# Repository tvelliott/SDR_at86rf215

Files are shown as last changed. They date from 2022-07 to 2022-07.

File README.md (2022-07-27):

# SDR_at86rf215
SDR design based on the AT86RF215 transceiver with IQ LVDS / FPGA DDR (dual-data-rate) interface. The quadrature data is clocked on the rising *and* falling edges. Ethernet is 100Mbps. The firmware and HDL was written and operational in 2018. It supports stand-alone reception of P25. The firmware implementation is P25 P1 only. It does not currently do P25 P2 or P25 trunk-tracking, but the hardware is capable. It can also be used with SDR software over Ethernet such as GQRX with modified RTL-TCP drivers (mods allow 16-bit samples).

<BR>To compile:
<BR>install the gcc arm toolchain version gcc-arm-none-eabi-7-2018-q2-update/   
<BR>https://developer.arm.com/tools-and-software/open-source-software/developer-tools/gnu-toolchain/gnu-rm/downloads/7-2018-q2-update
<BR><BR>In the firmware directory, create a symbolic link to the toolchain: 
<BR>e.g.  ln -s ../gcc-arm-none-eabi-7-2018-q2-update  arm-toolchain
<BR>Then type 'make'
<BR>
<BR>
To compile the verilog code and place-route for the FPGA, you will need to install project ice-storm,Yosys, and nextpnr. In order to run the testbench for the DDR verilog code, you will also need to install iverilog and gtkwave.
<BR>
<BR>https://github.com/YosysHQ/icestorm
<BR>https://github.com/YosysHQ/yosys
<BR>https://github.com/YosysHQ/nextpnr
<BR>https://github.com/steveicarus/iverilog
<BR>https://github.com/gtkwave/gtkwave
<BR><BR>
AT86RF215 12-bit I/Q Receiver PCB / ICE40 BGA-256 FPGA / STM32H743 MCU / 100Mbps Ethernet / Stereo I2S Audio
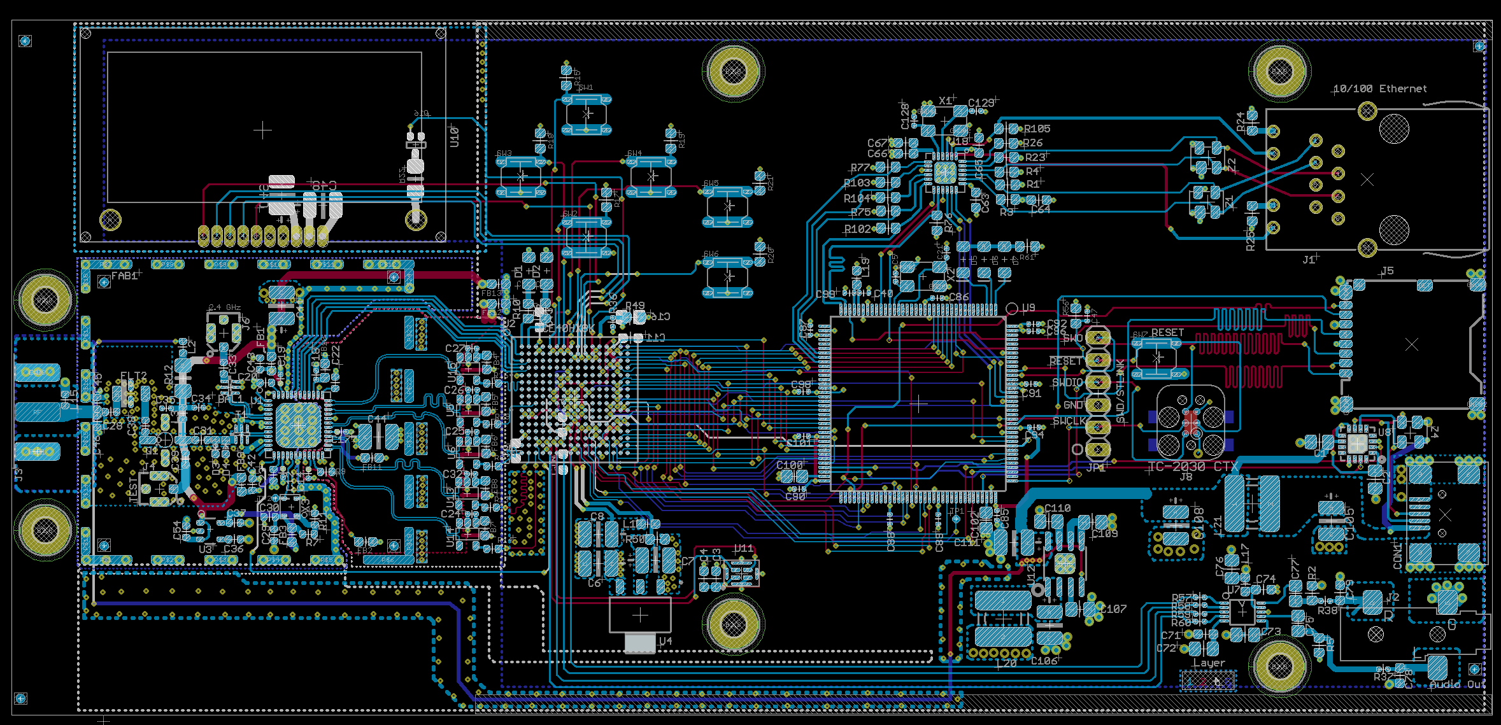
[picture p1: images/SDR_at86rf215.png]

<BR>
Dual-antenna VHF/UHF Tuner PCB (1MHz to 1200 MHz), IF output is 914 MHz and fed to the AT86RF215 receiver.
<BR>
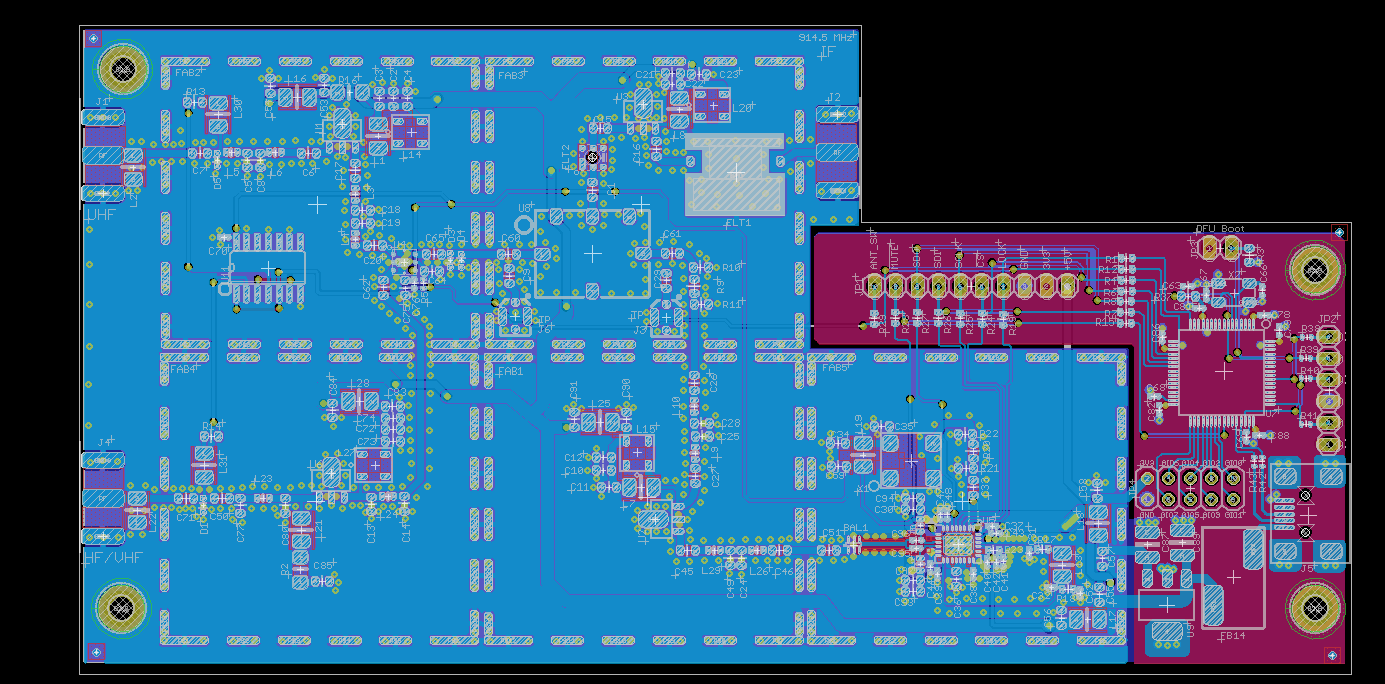
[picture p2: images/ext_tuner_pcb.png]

<BR>
FPGA Routing / Usage
<BR>
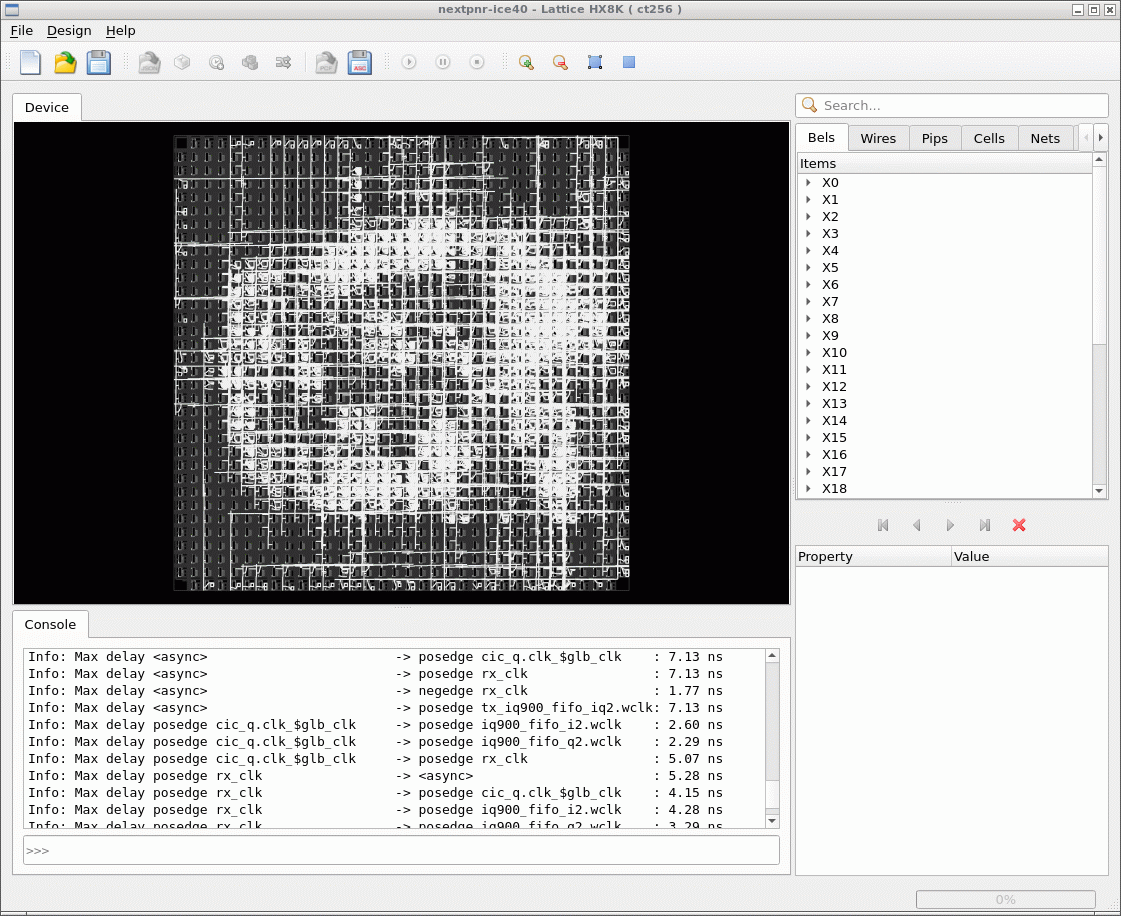
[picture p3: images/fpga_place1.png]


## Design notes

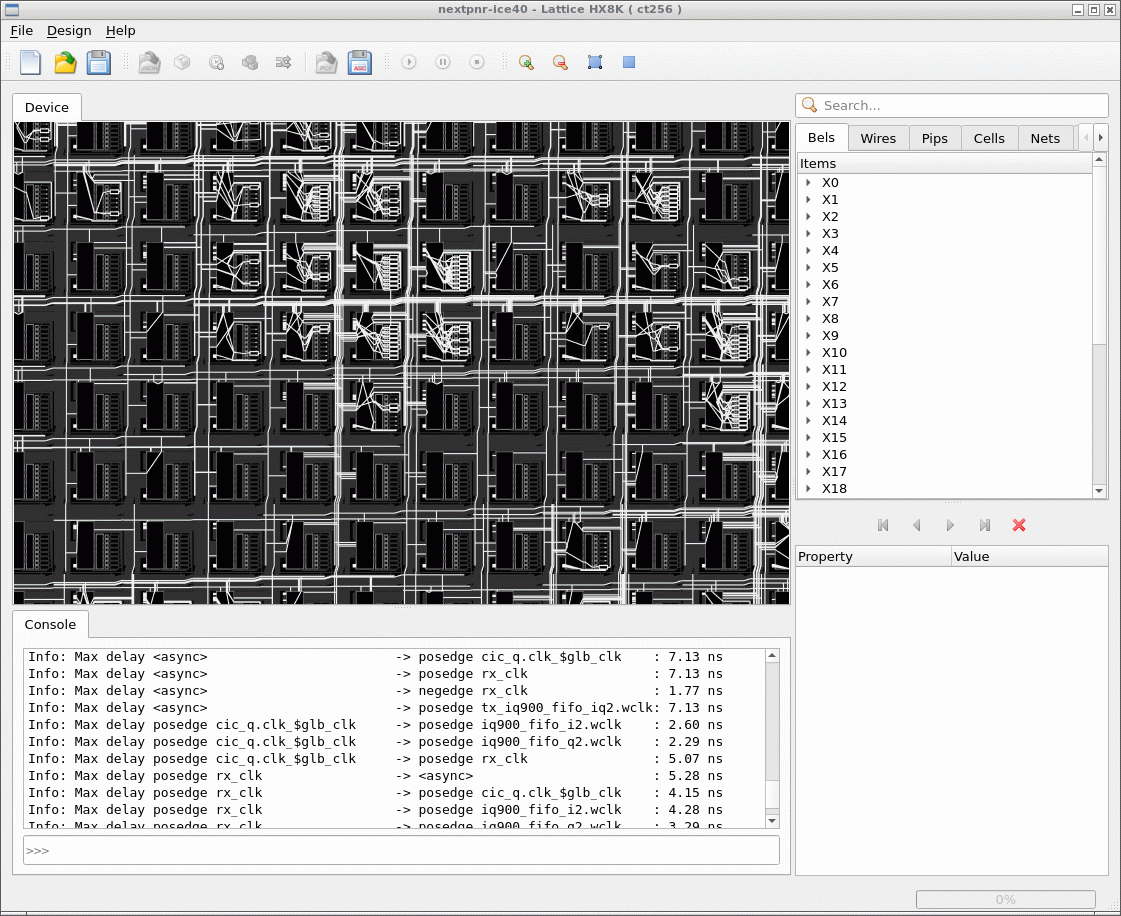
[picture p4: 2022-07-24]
images/fpga_place2.png

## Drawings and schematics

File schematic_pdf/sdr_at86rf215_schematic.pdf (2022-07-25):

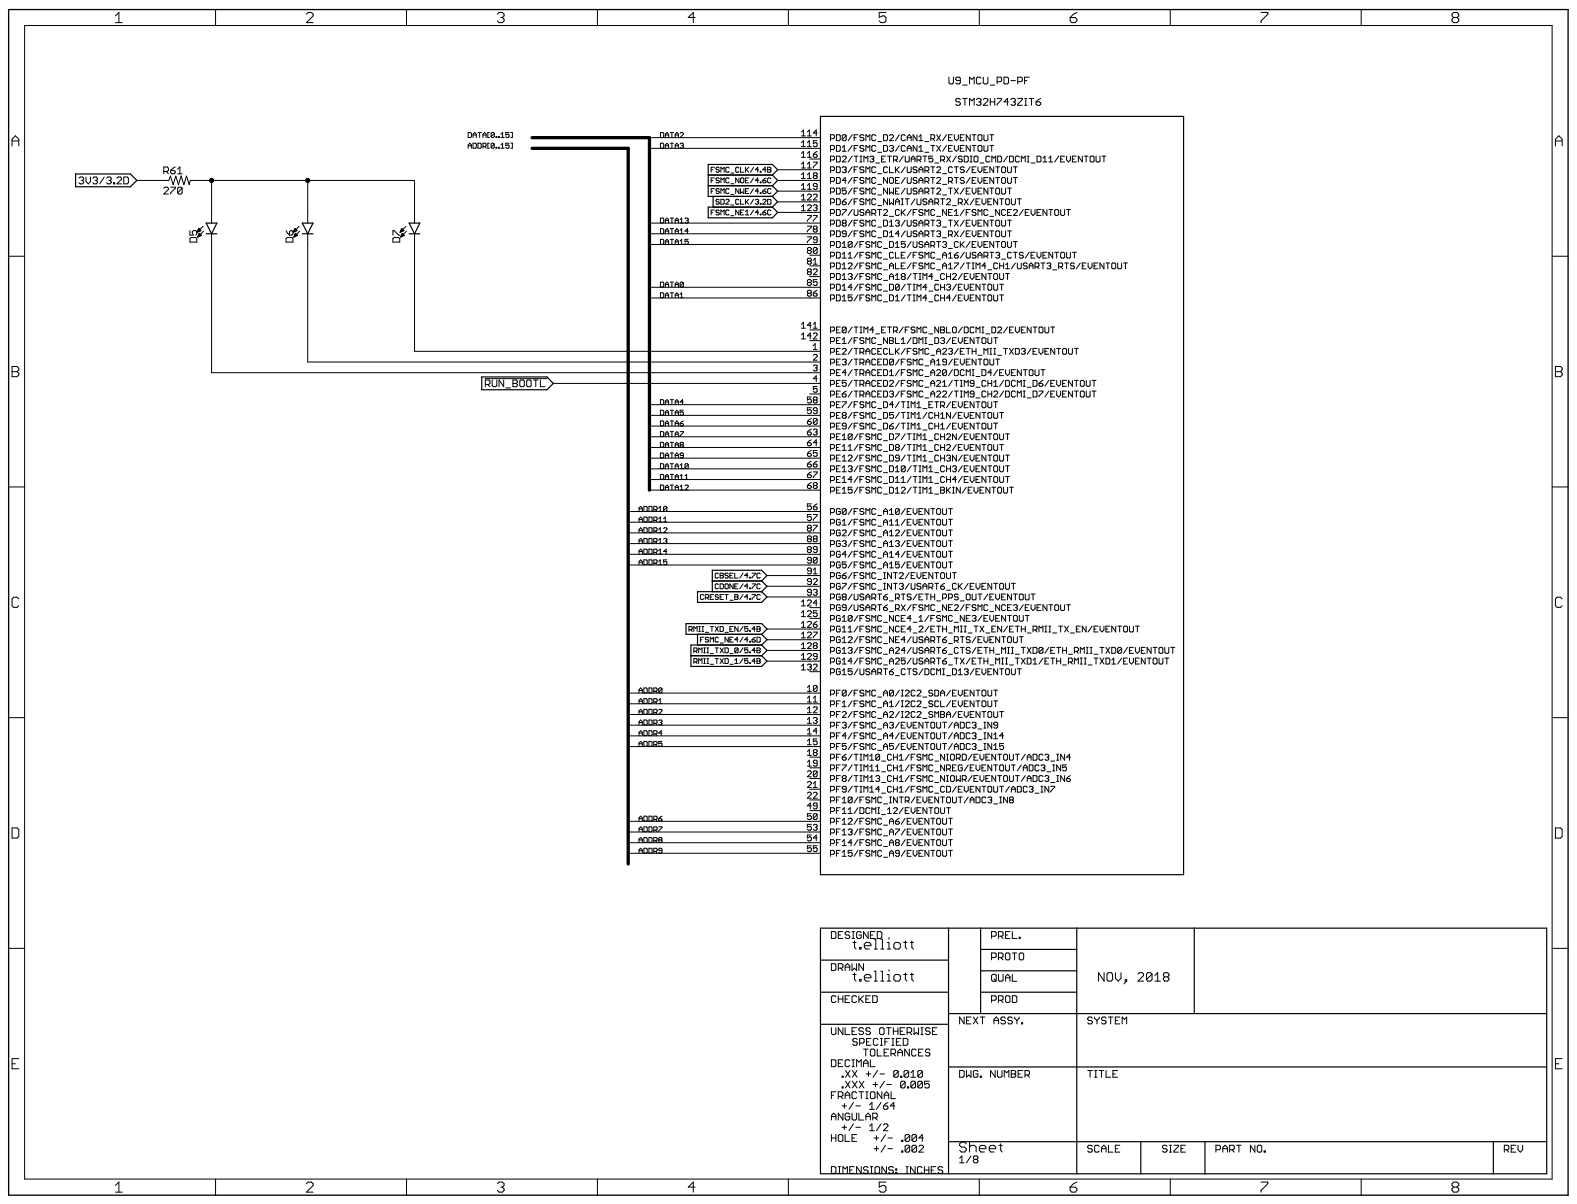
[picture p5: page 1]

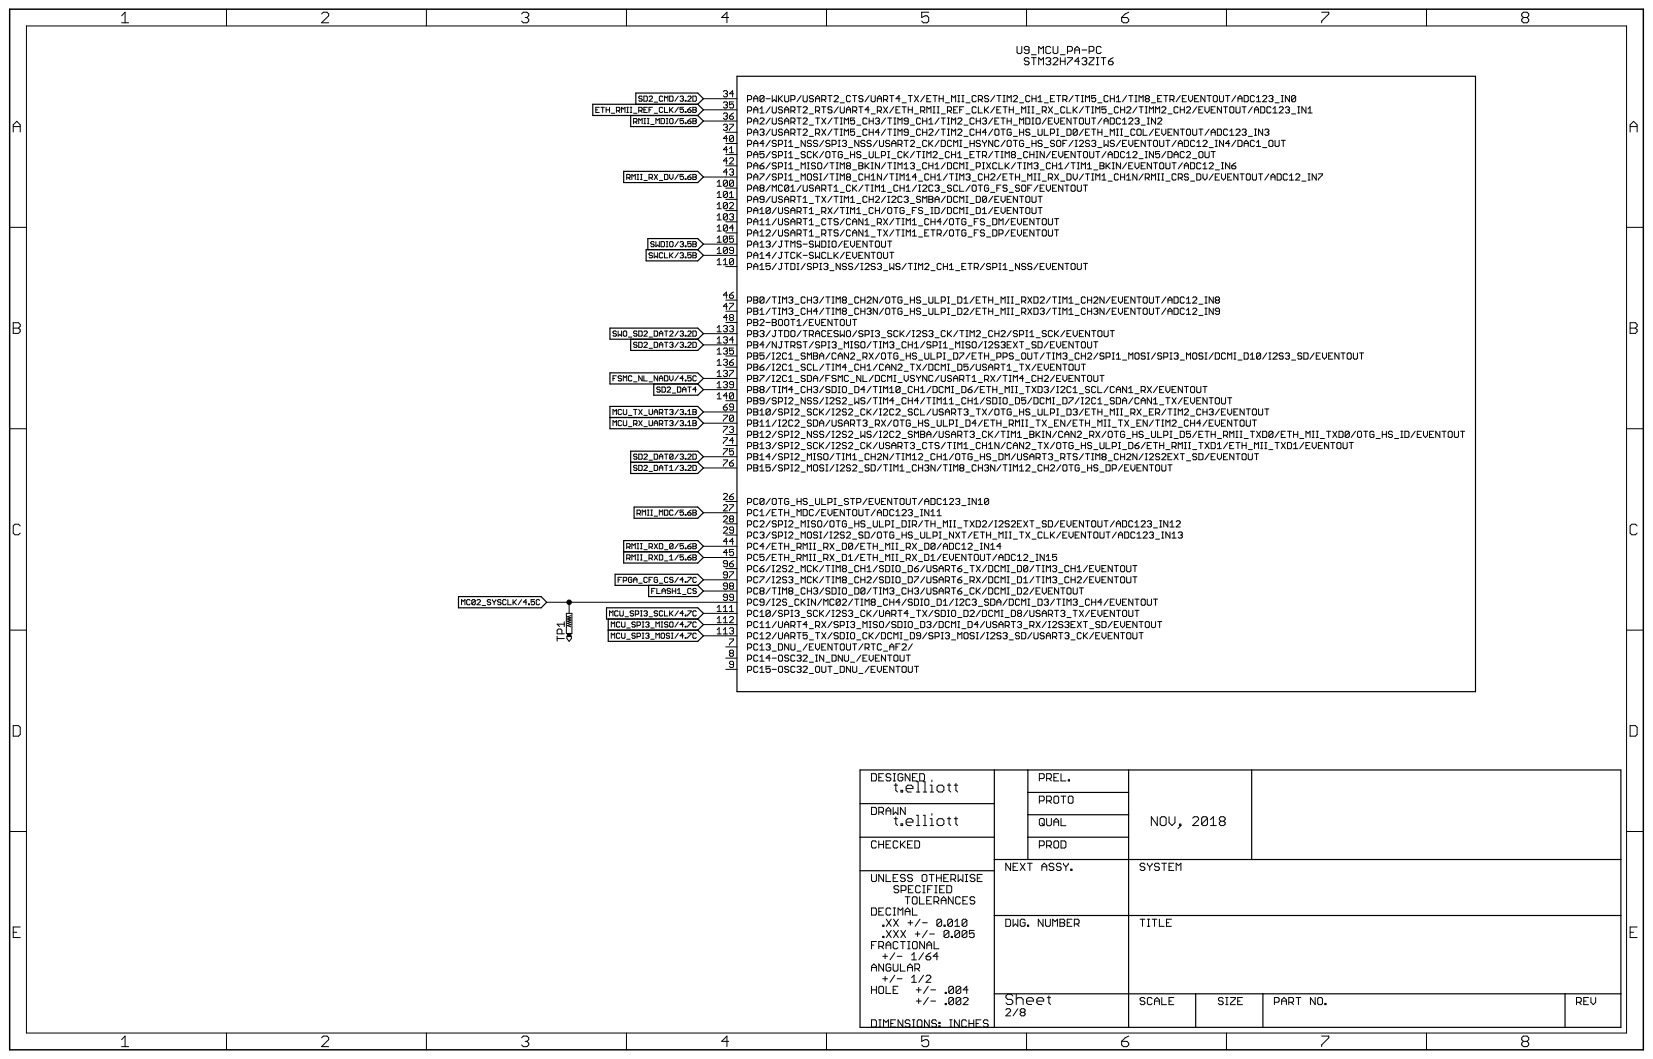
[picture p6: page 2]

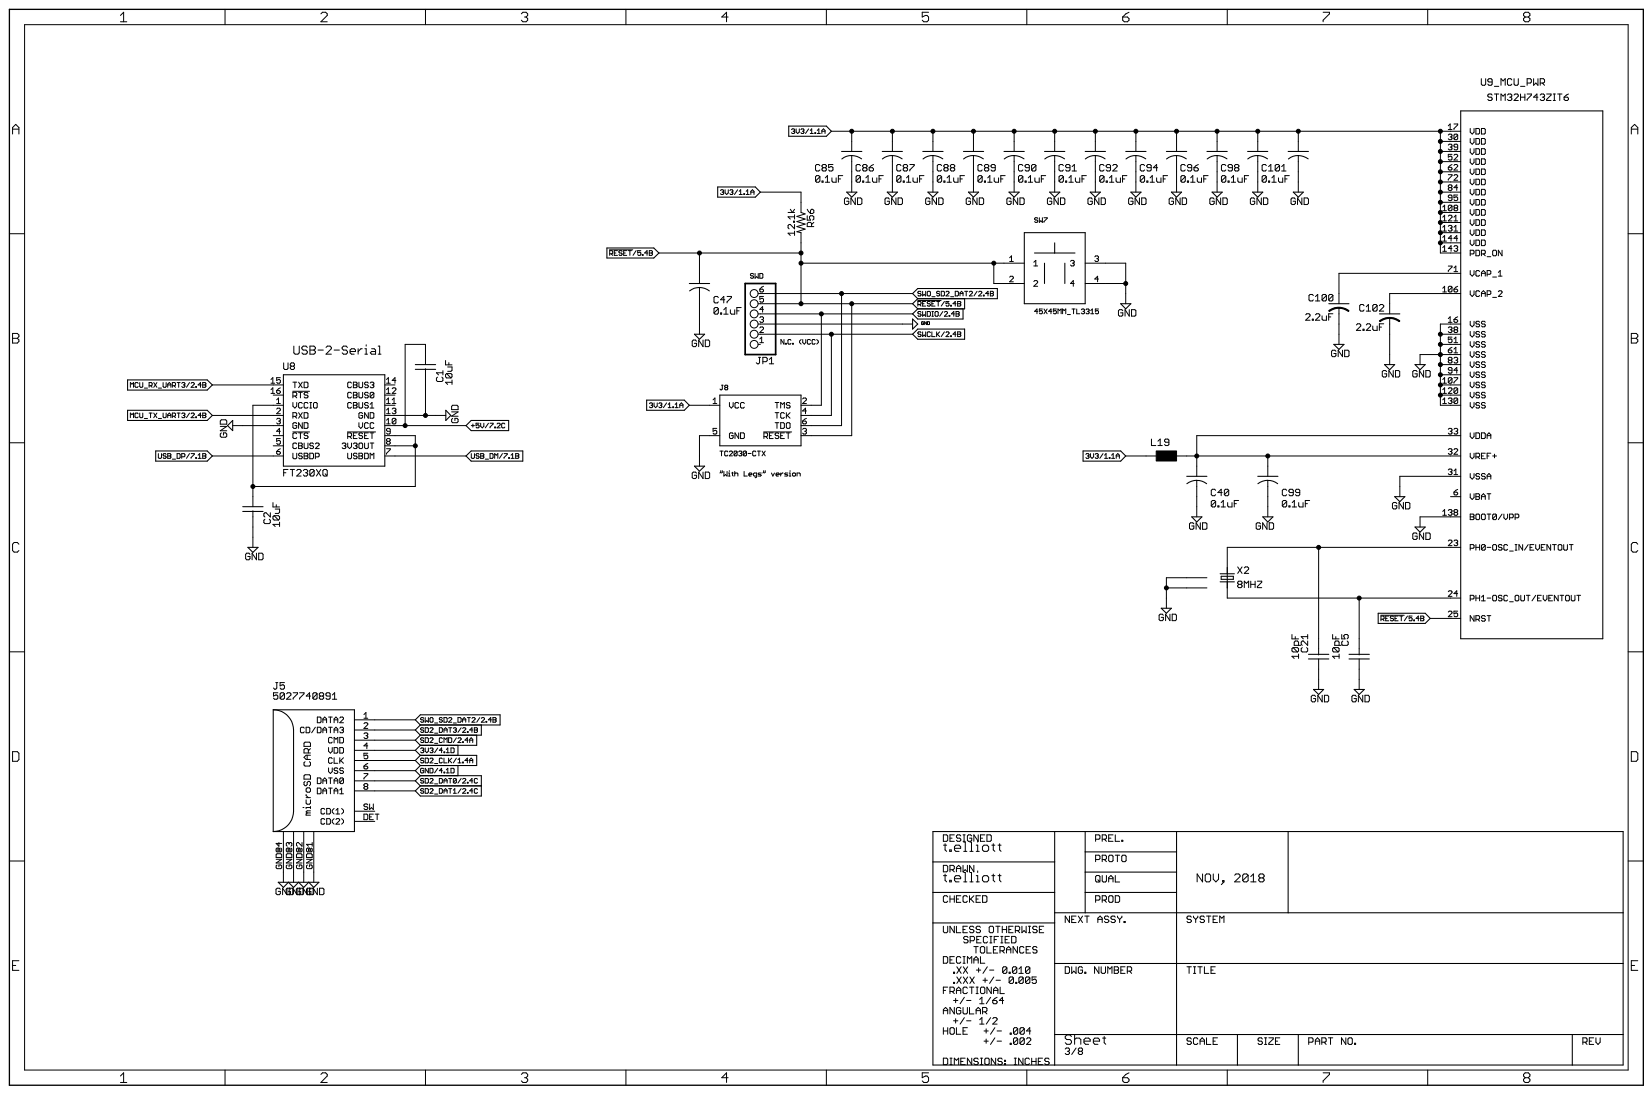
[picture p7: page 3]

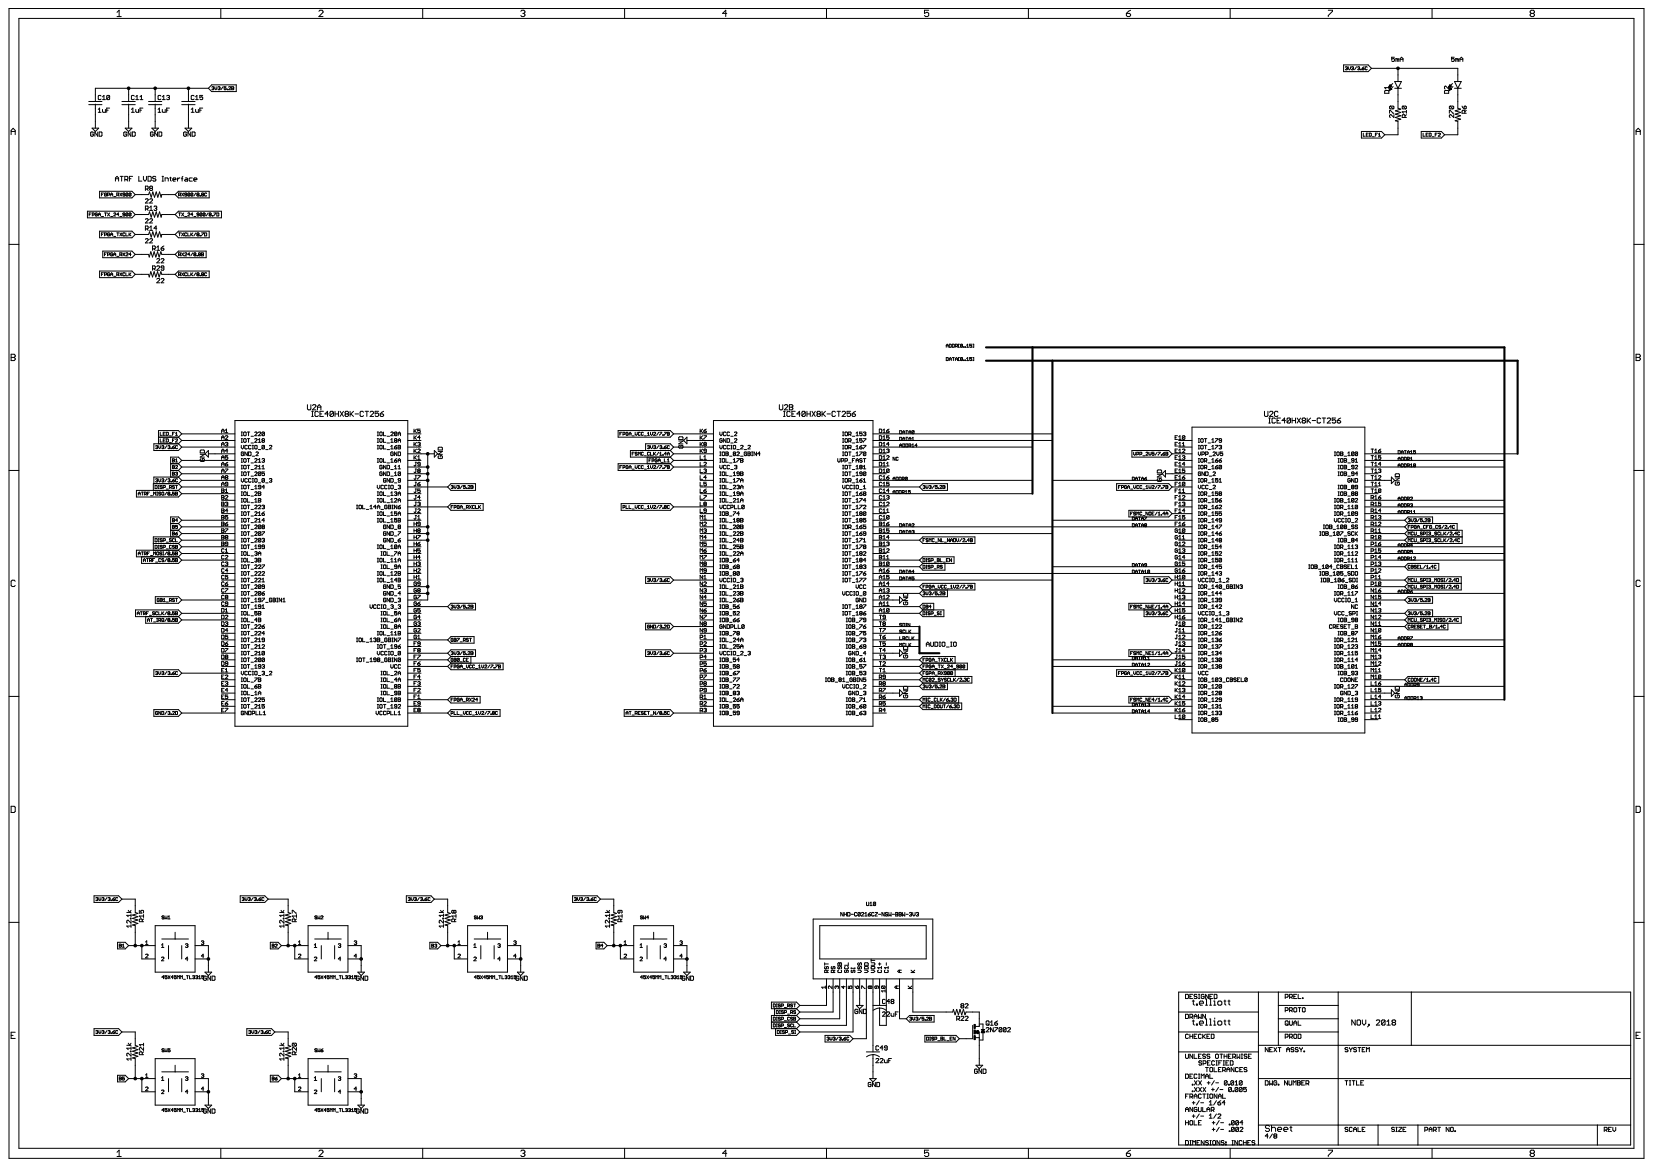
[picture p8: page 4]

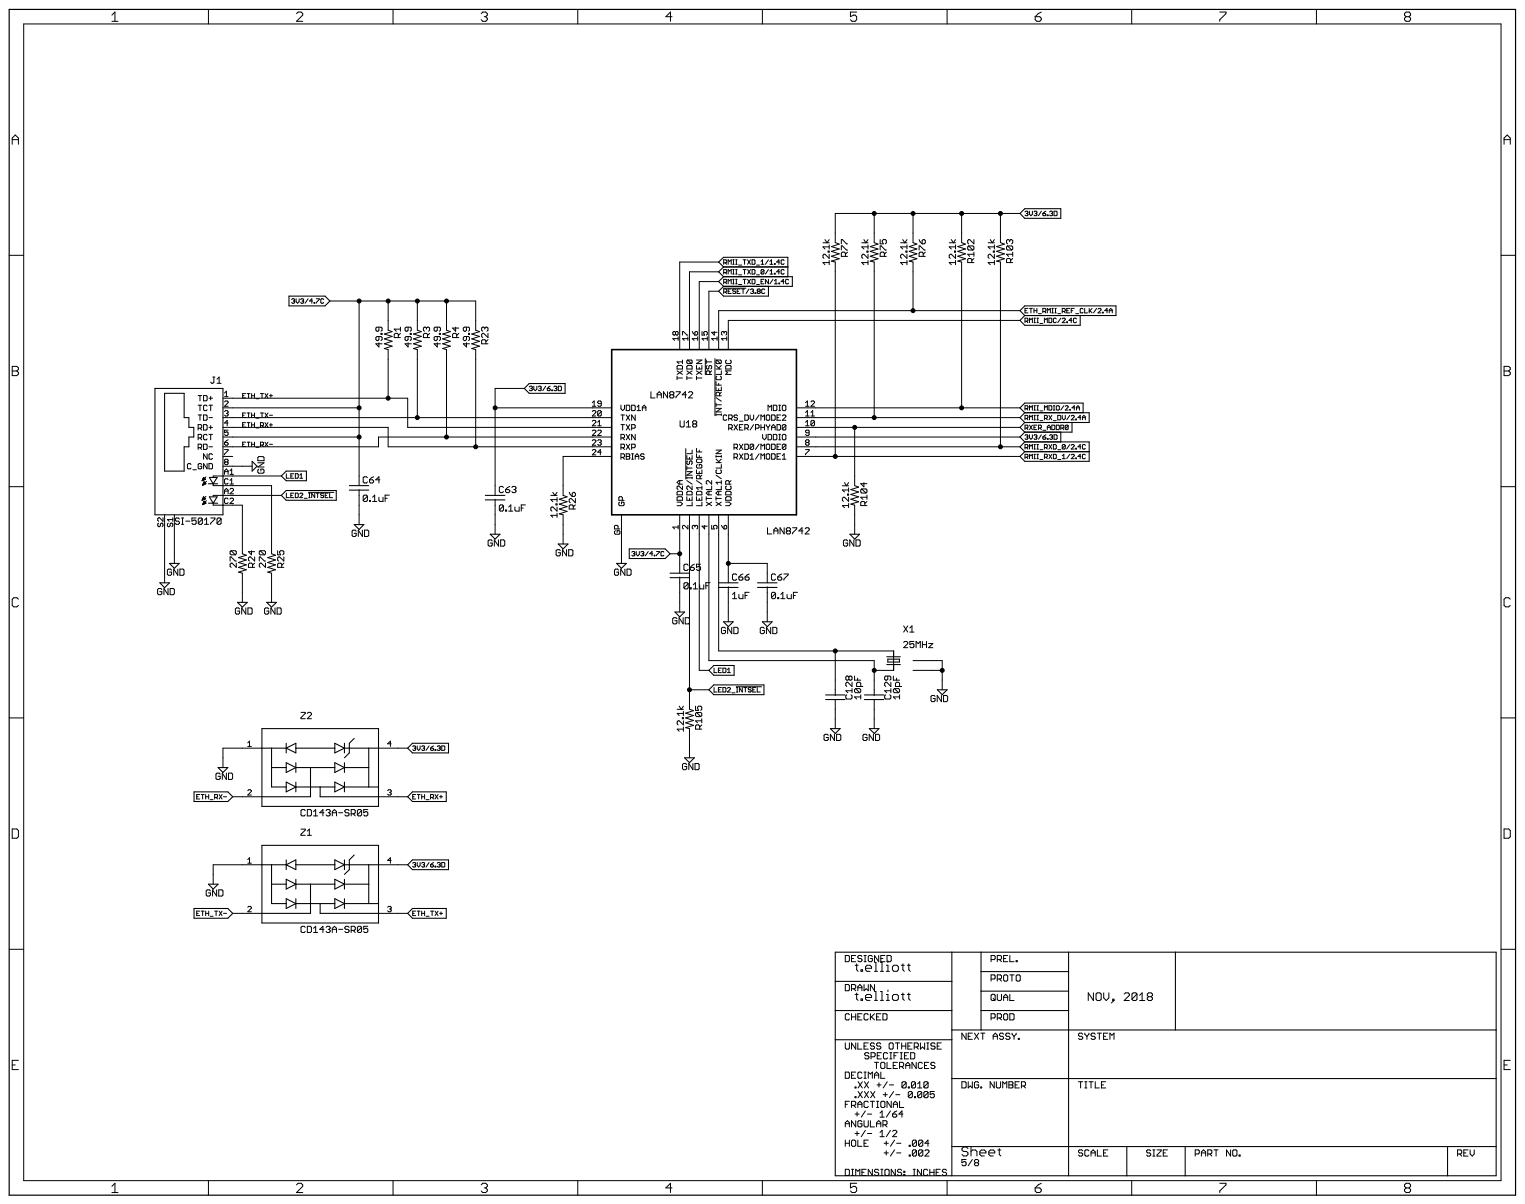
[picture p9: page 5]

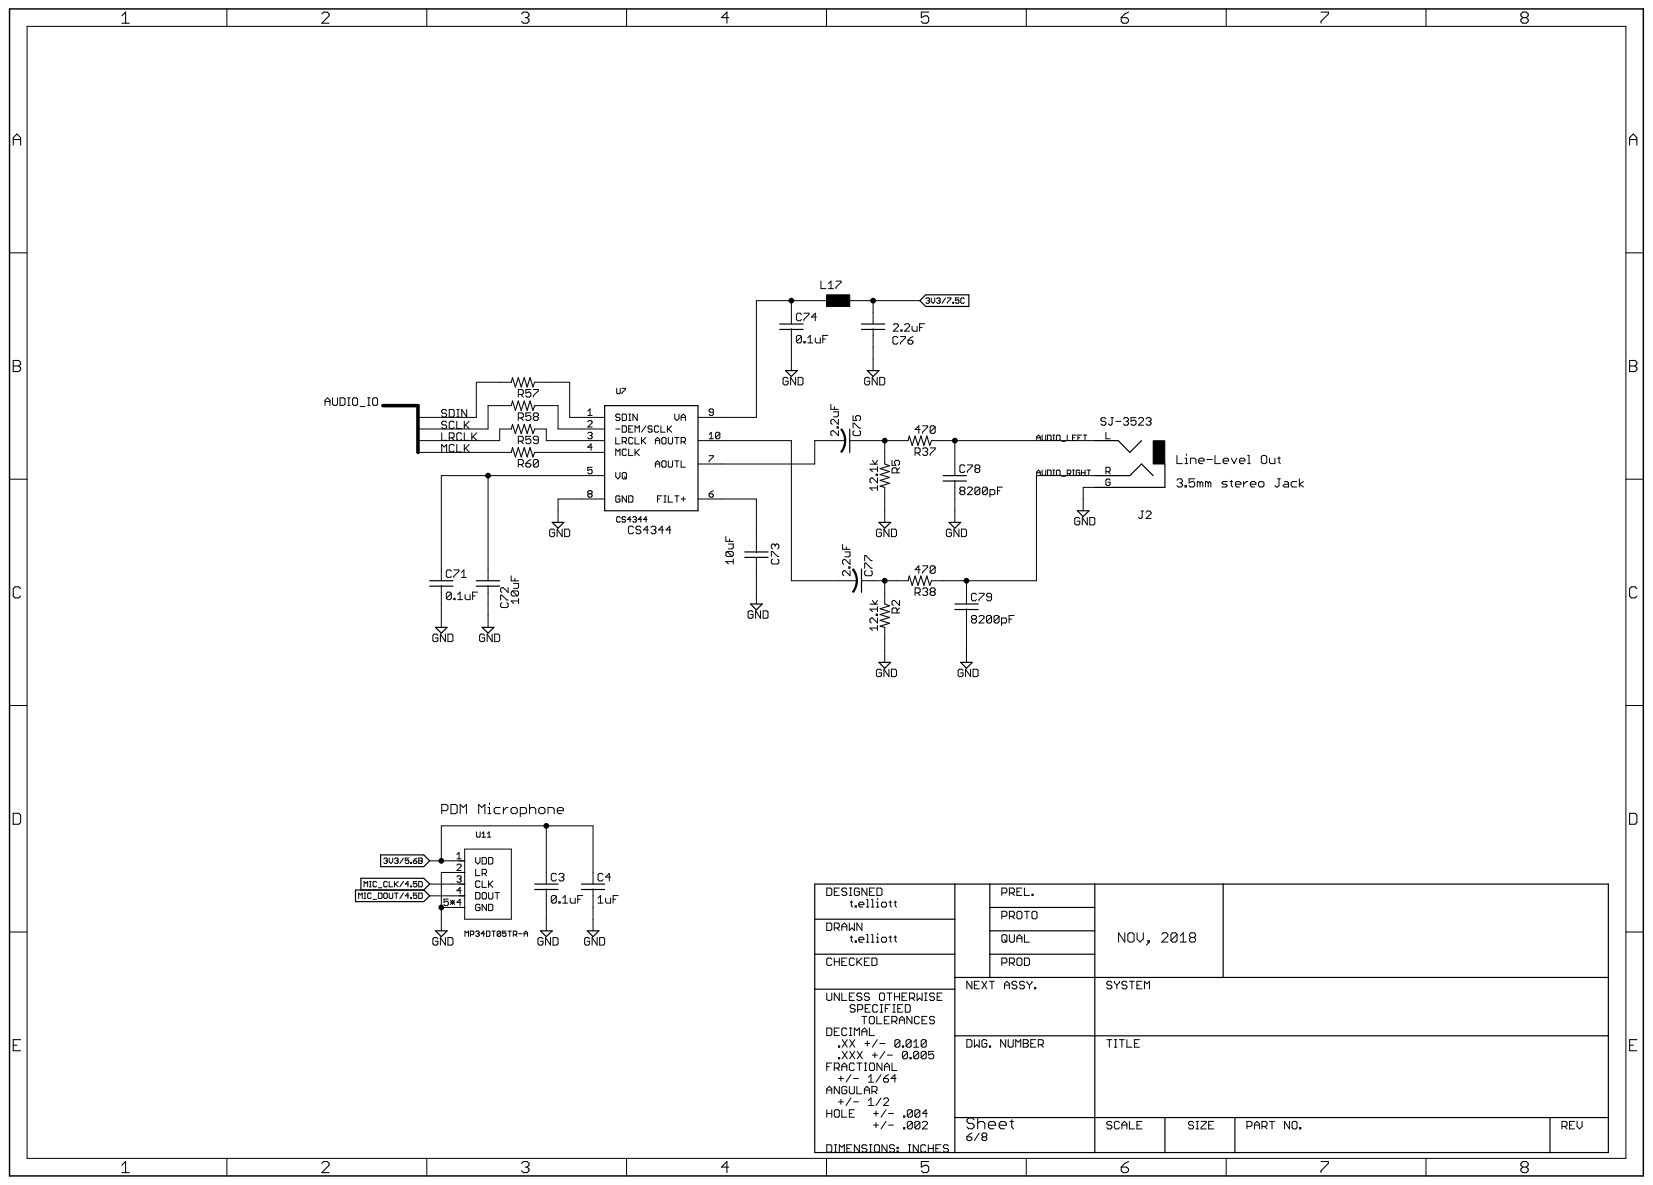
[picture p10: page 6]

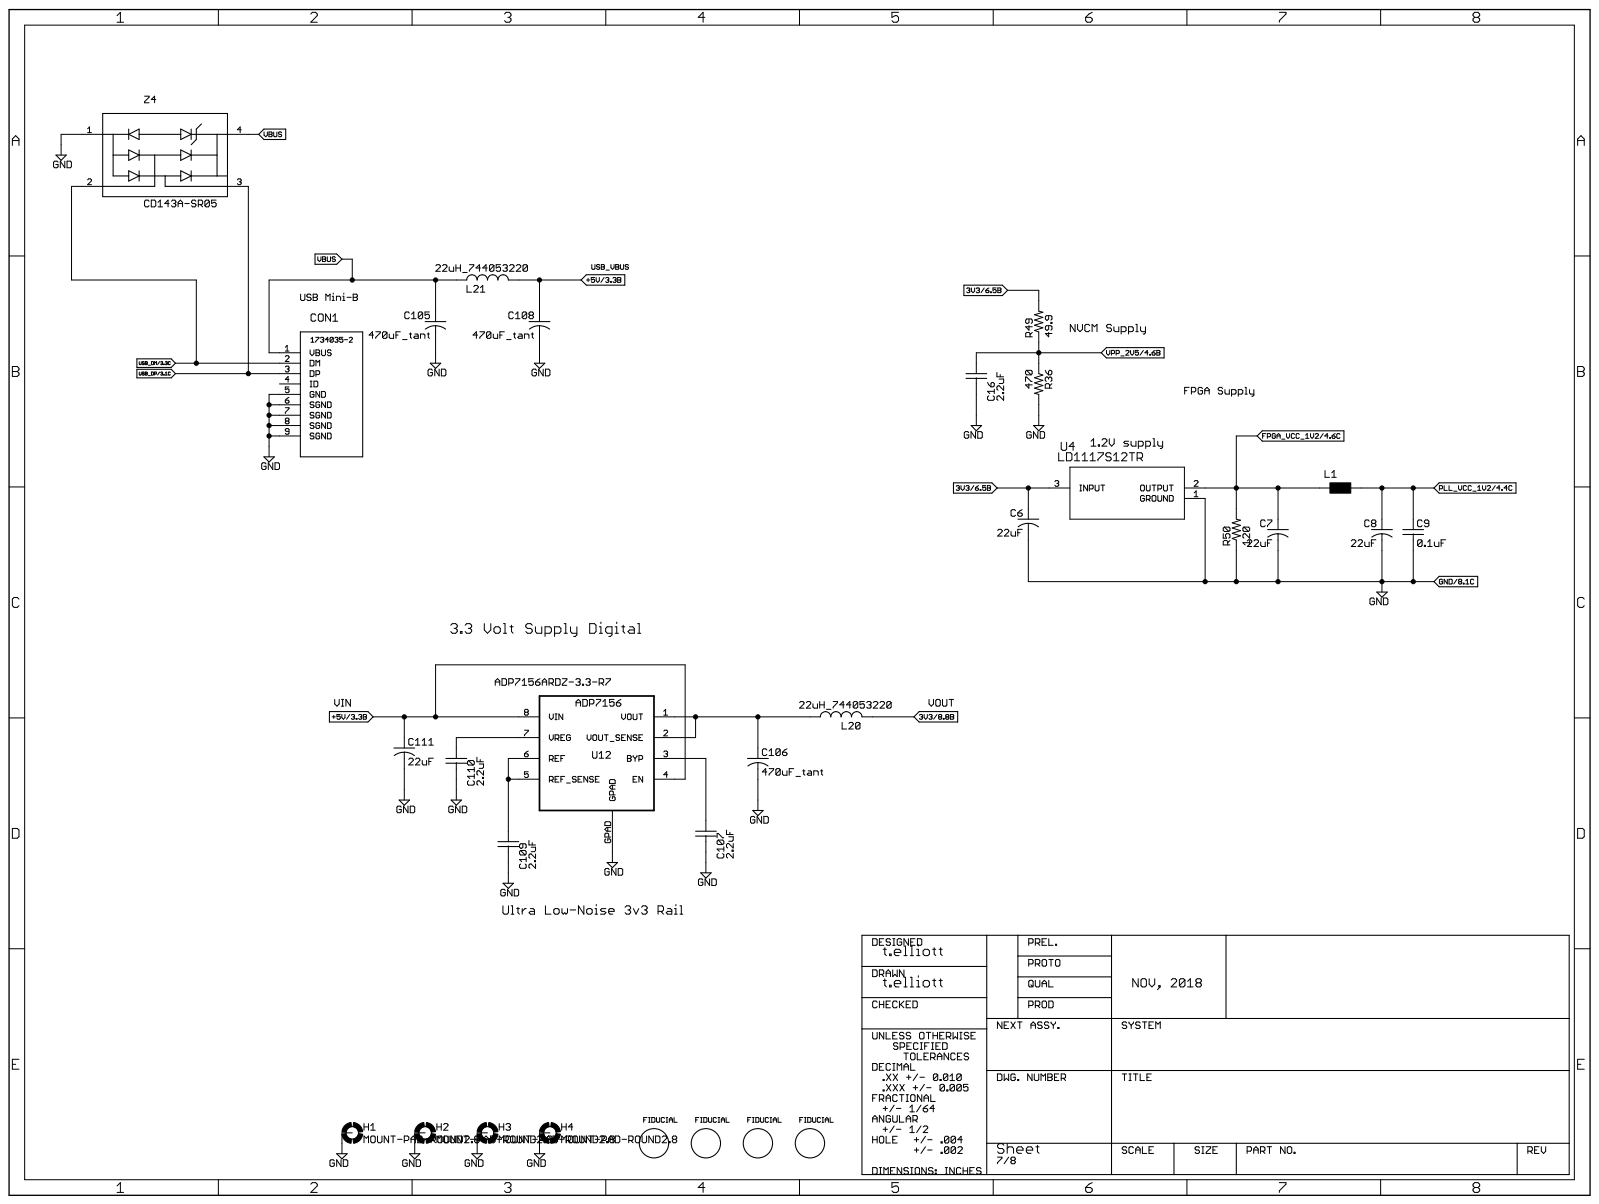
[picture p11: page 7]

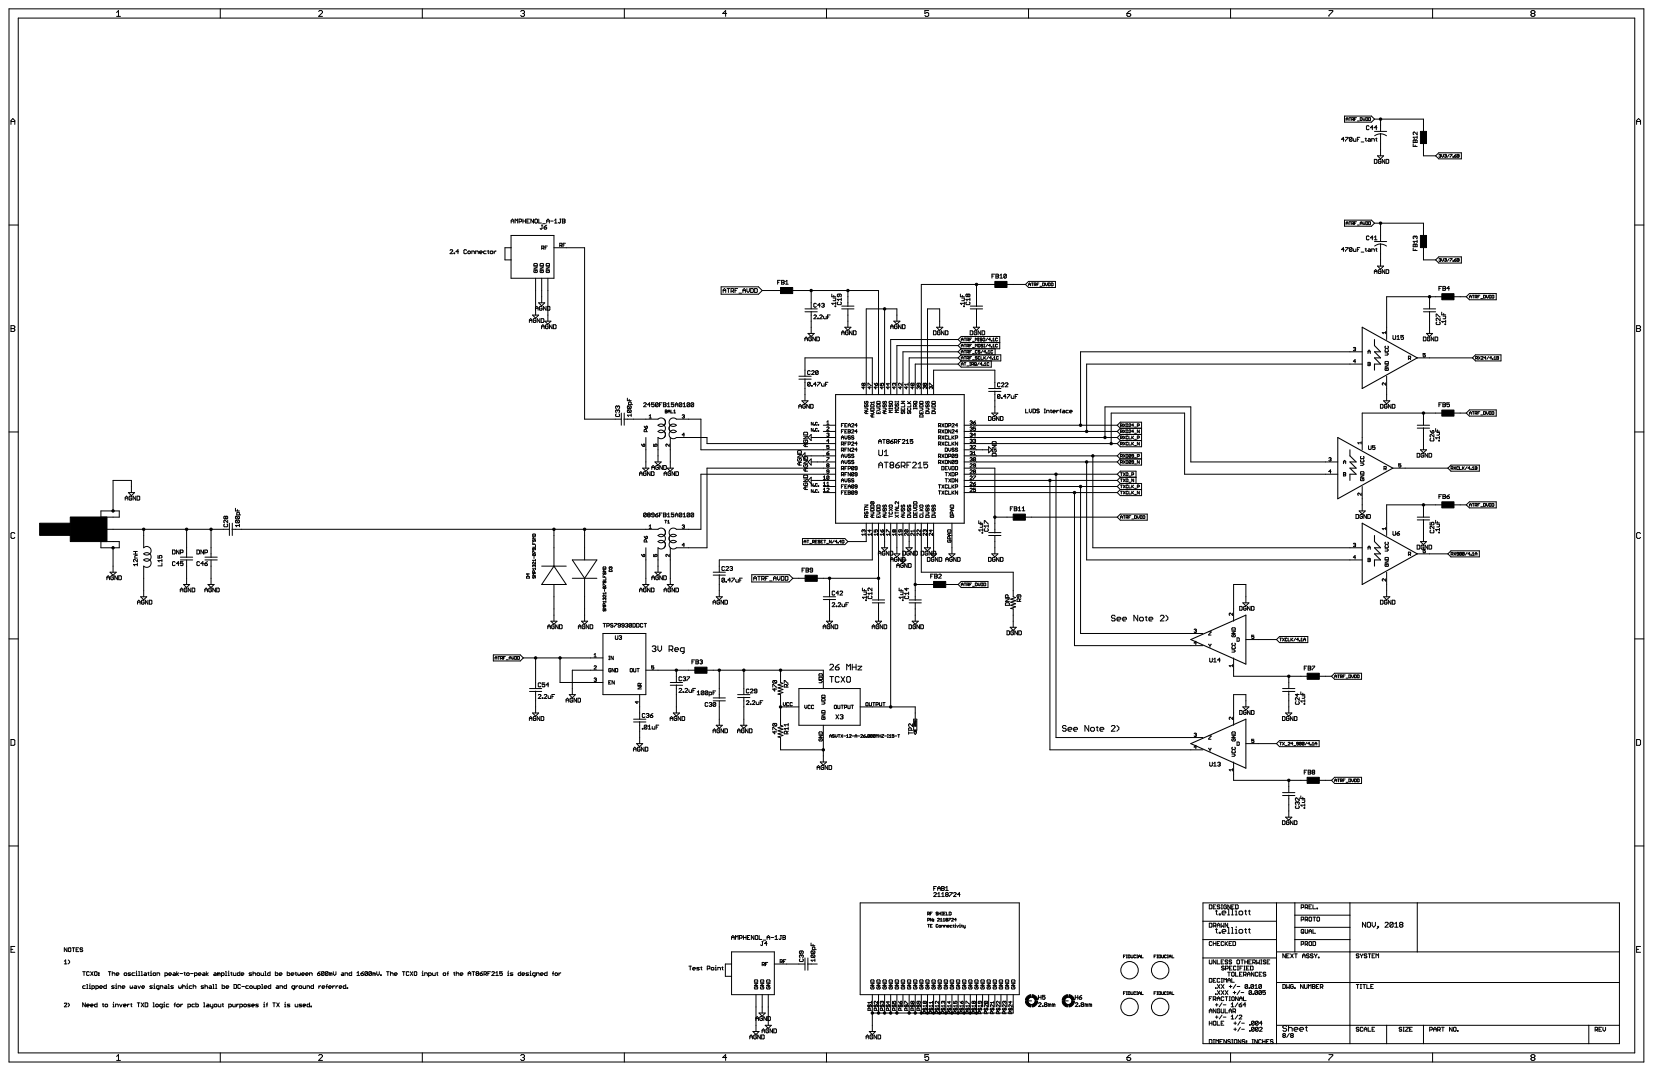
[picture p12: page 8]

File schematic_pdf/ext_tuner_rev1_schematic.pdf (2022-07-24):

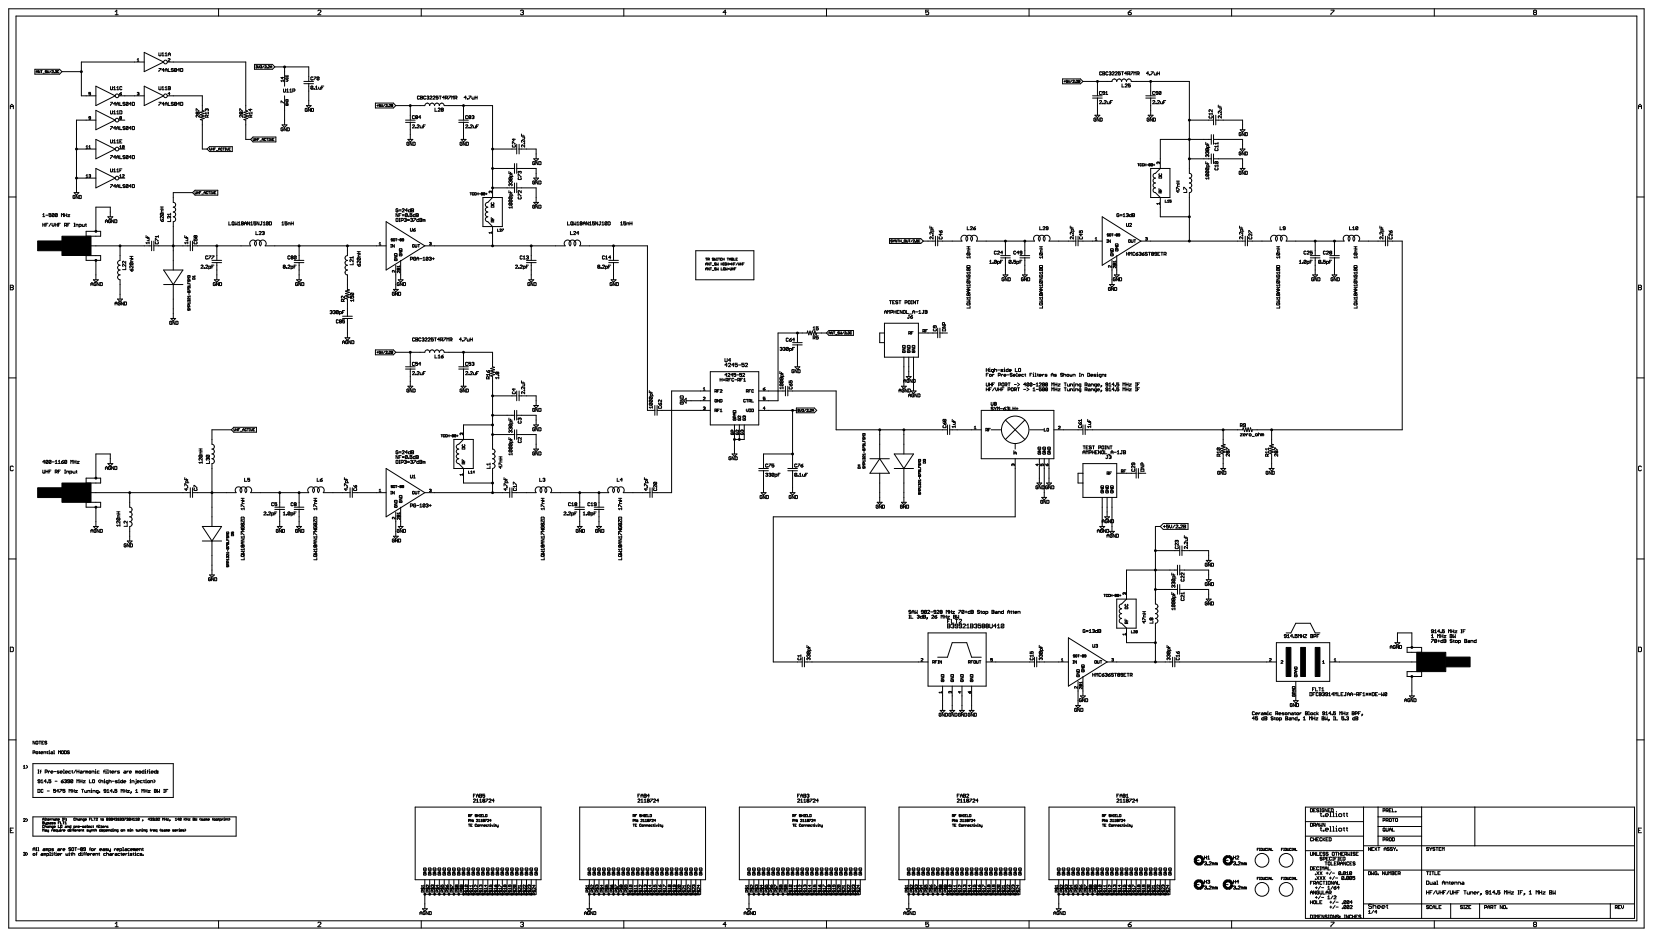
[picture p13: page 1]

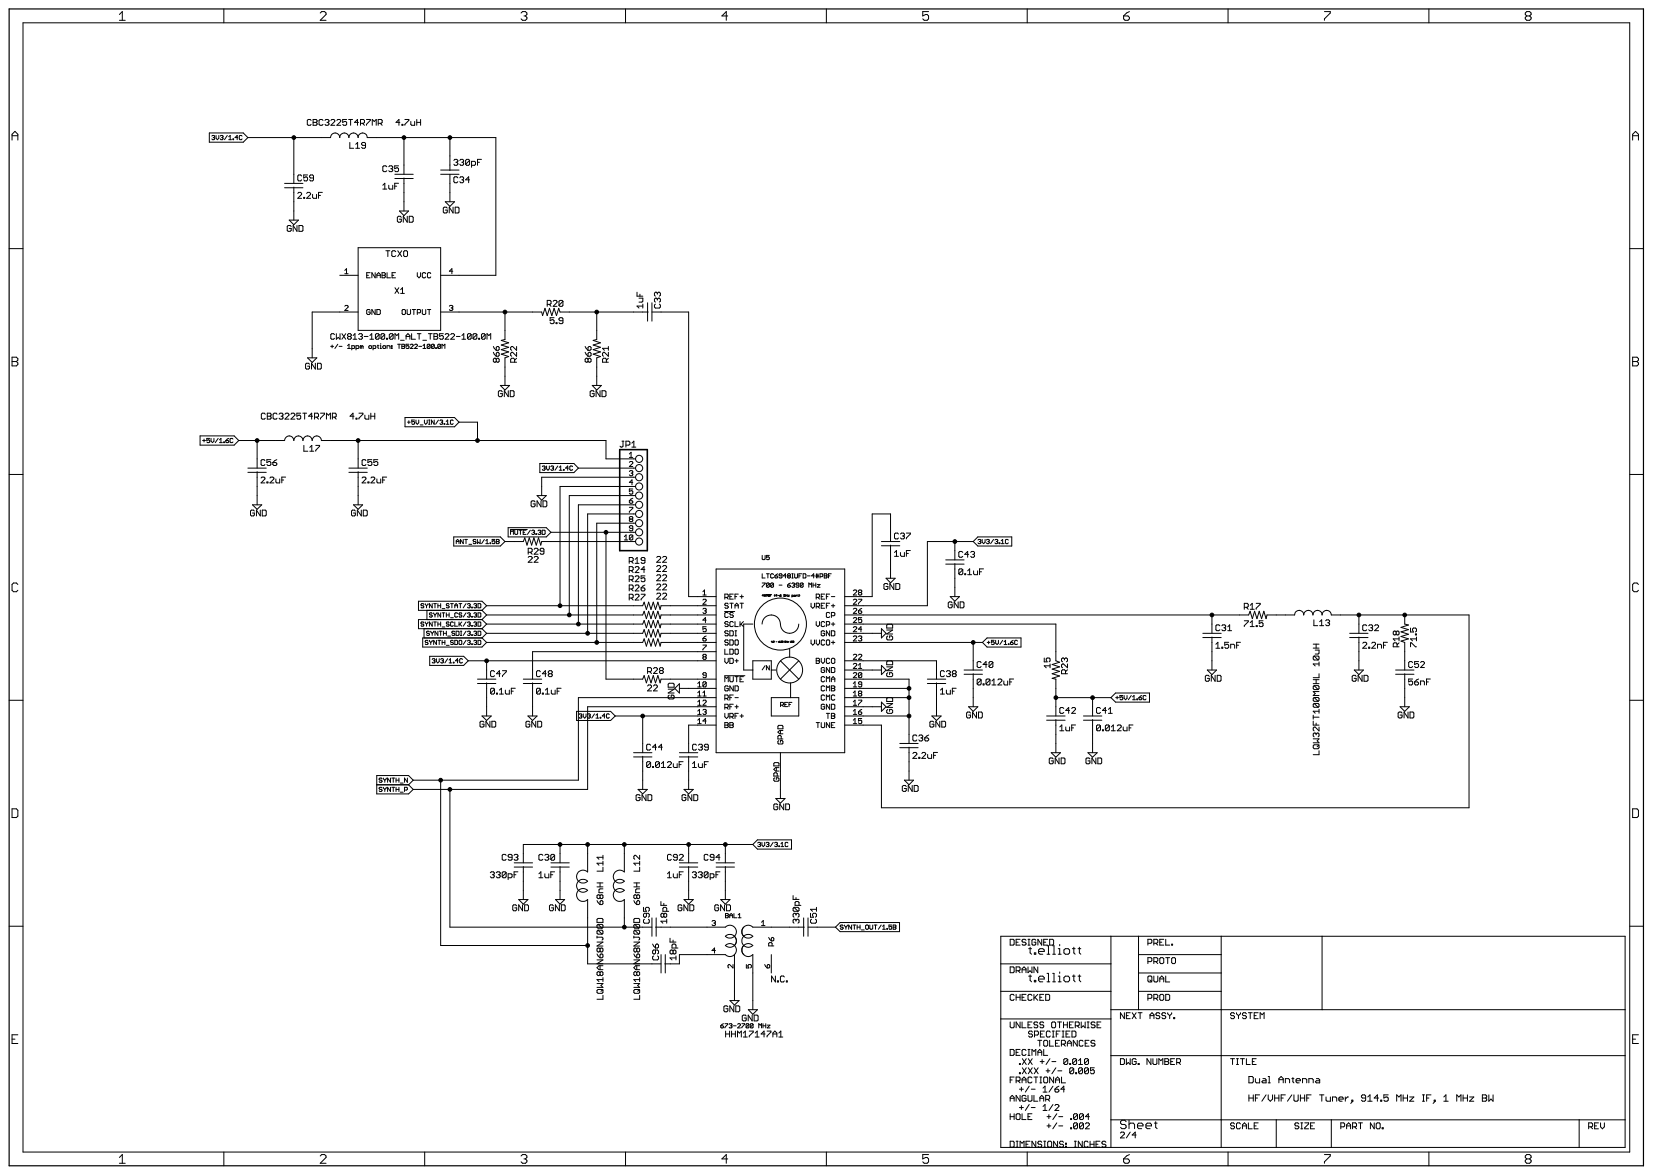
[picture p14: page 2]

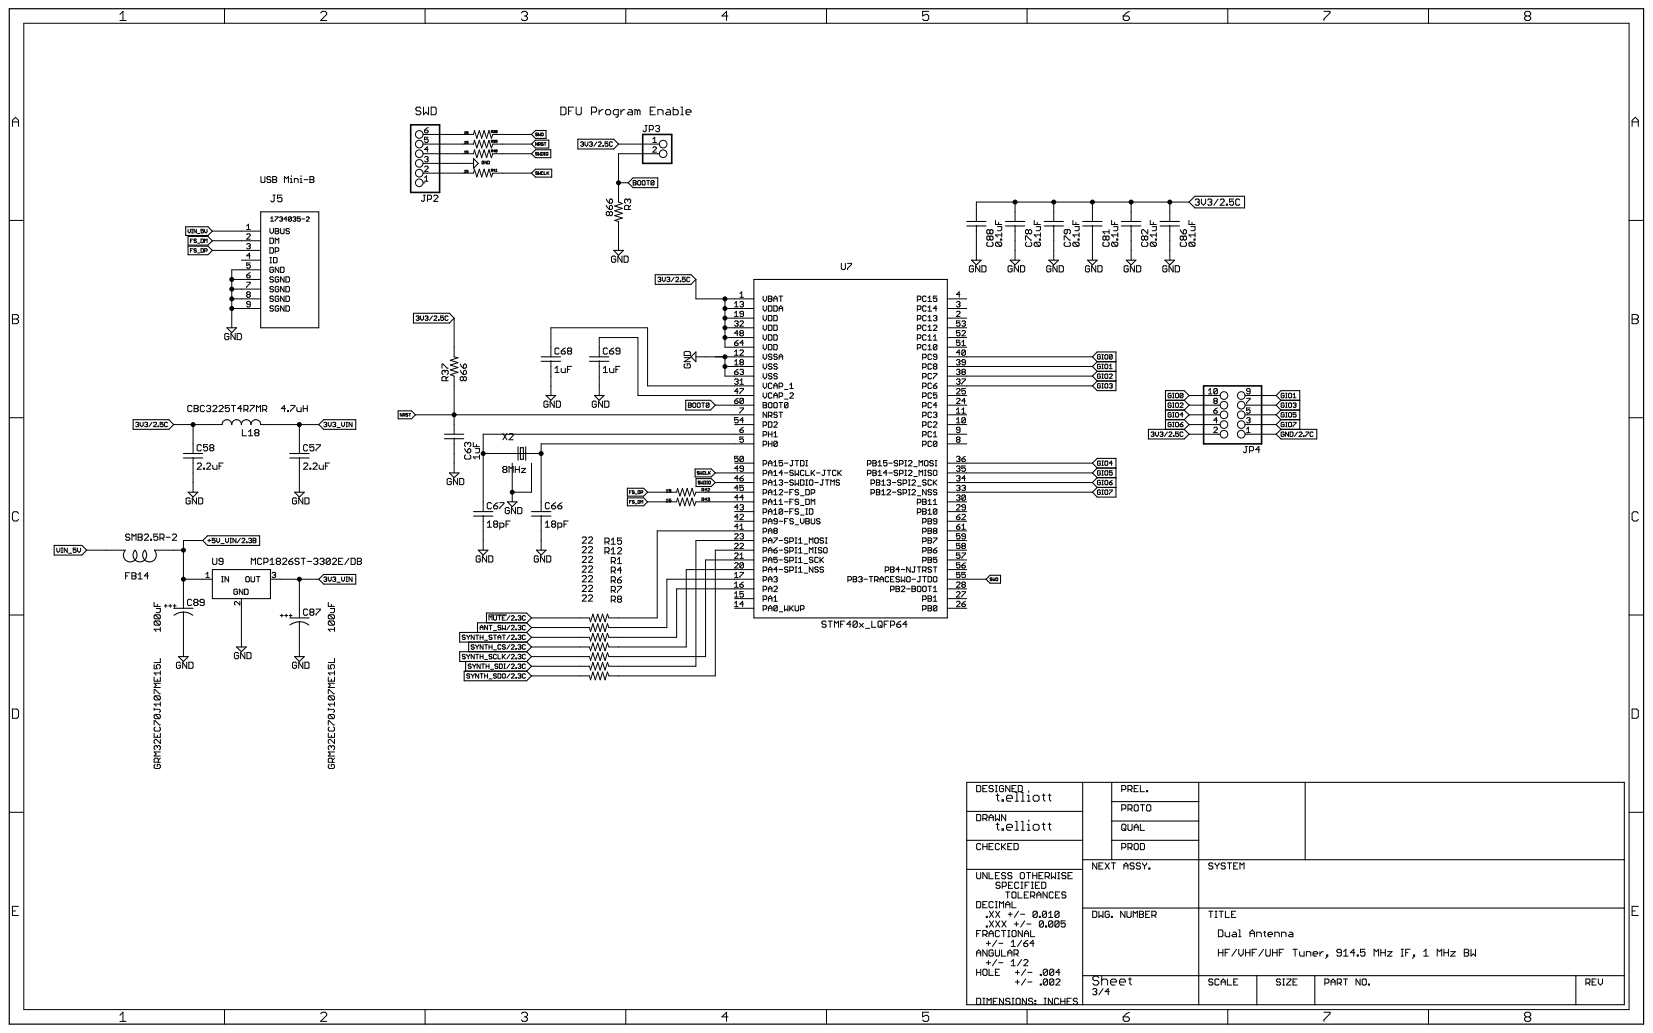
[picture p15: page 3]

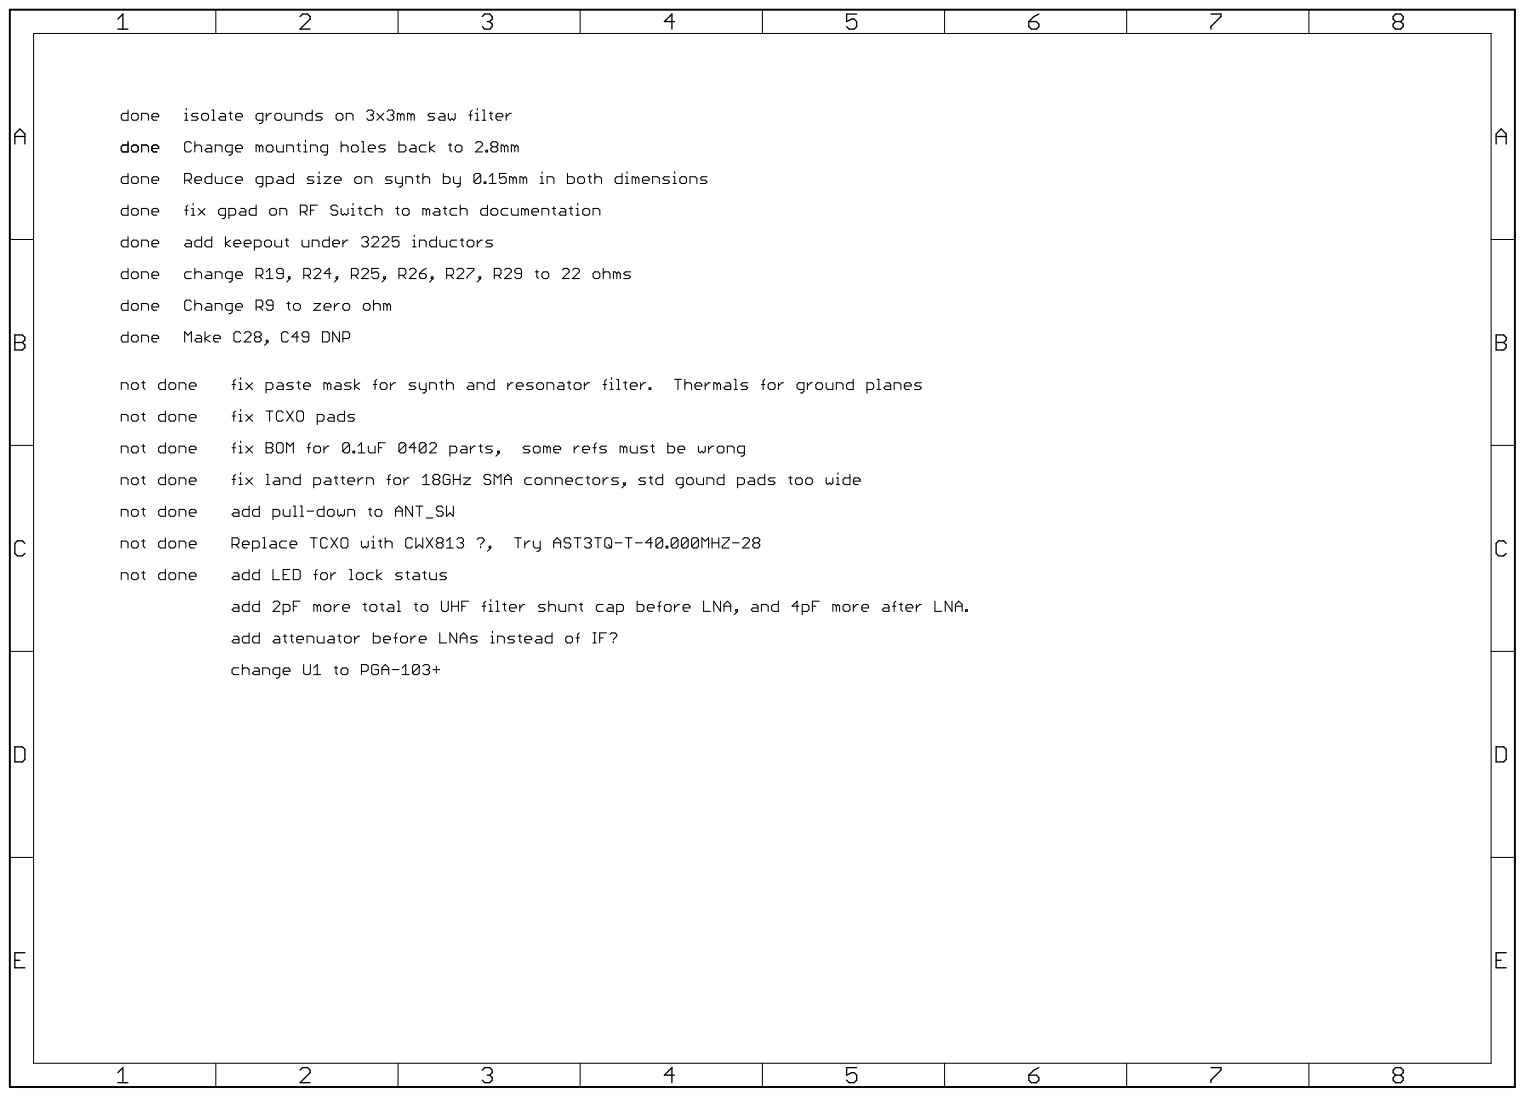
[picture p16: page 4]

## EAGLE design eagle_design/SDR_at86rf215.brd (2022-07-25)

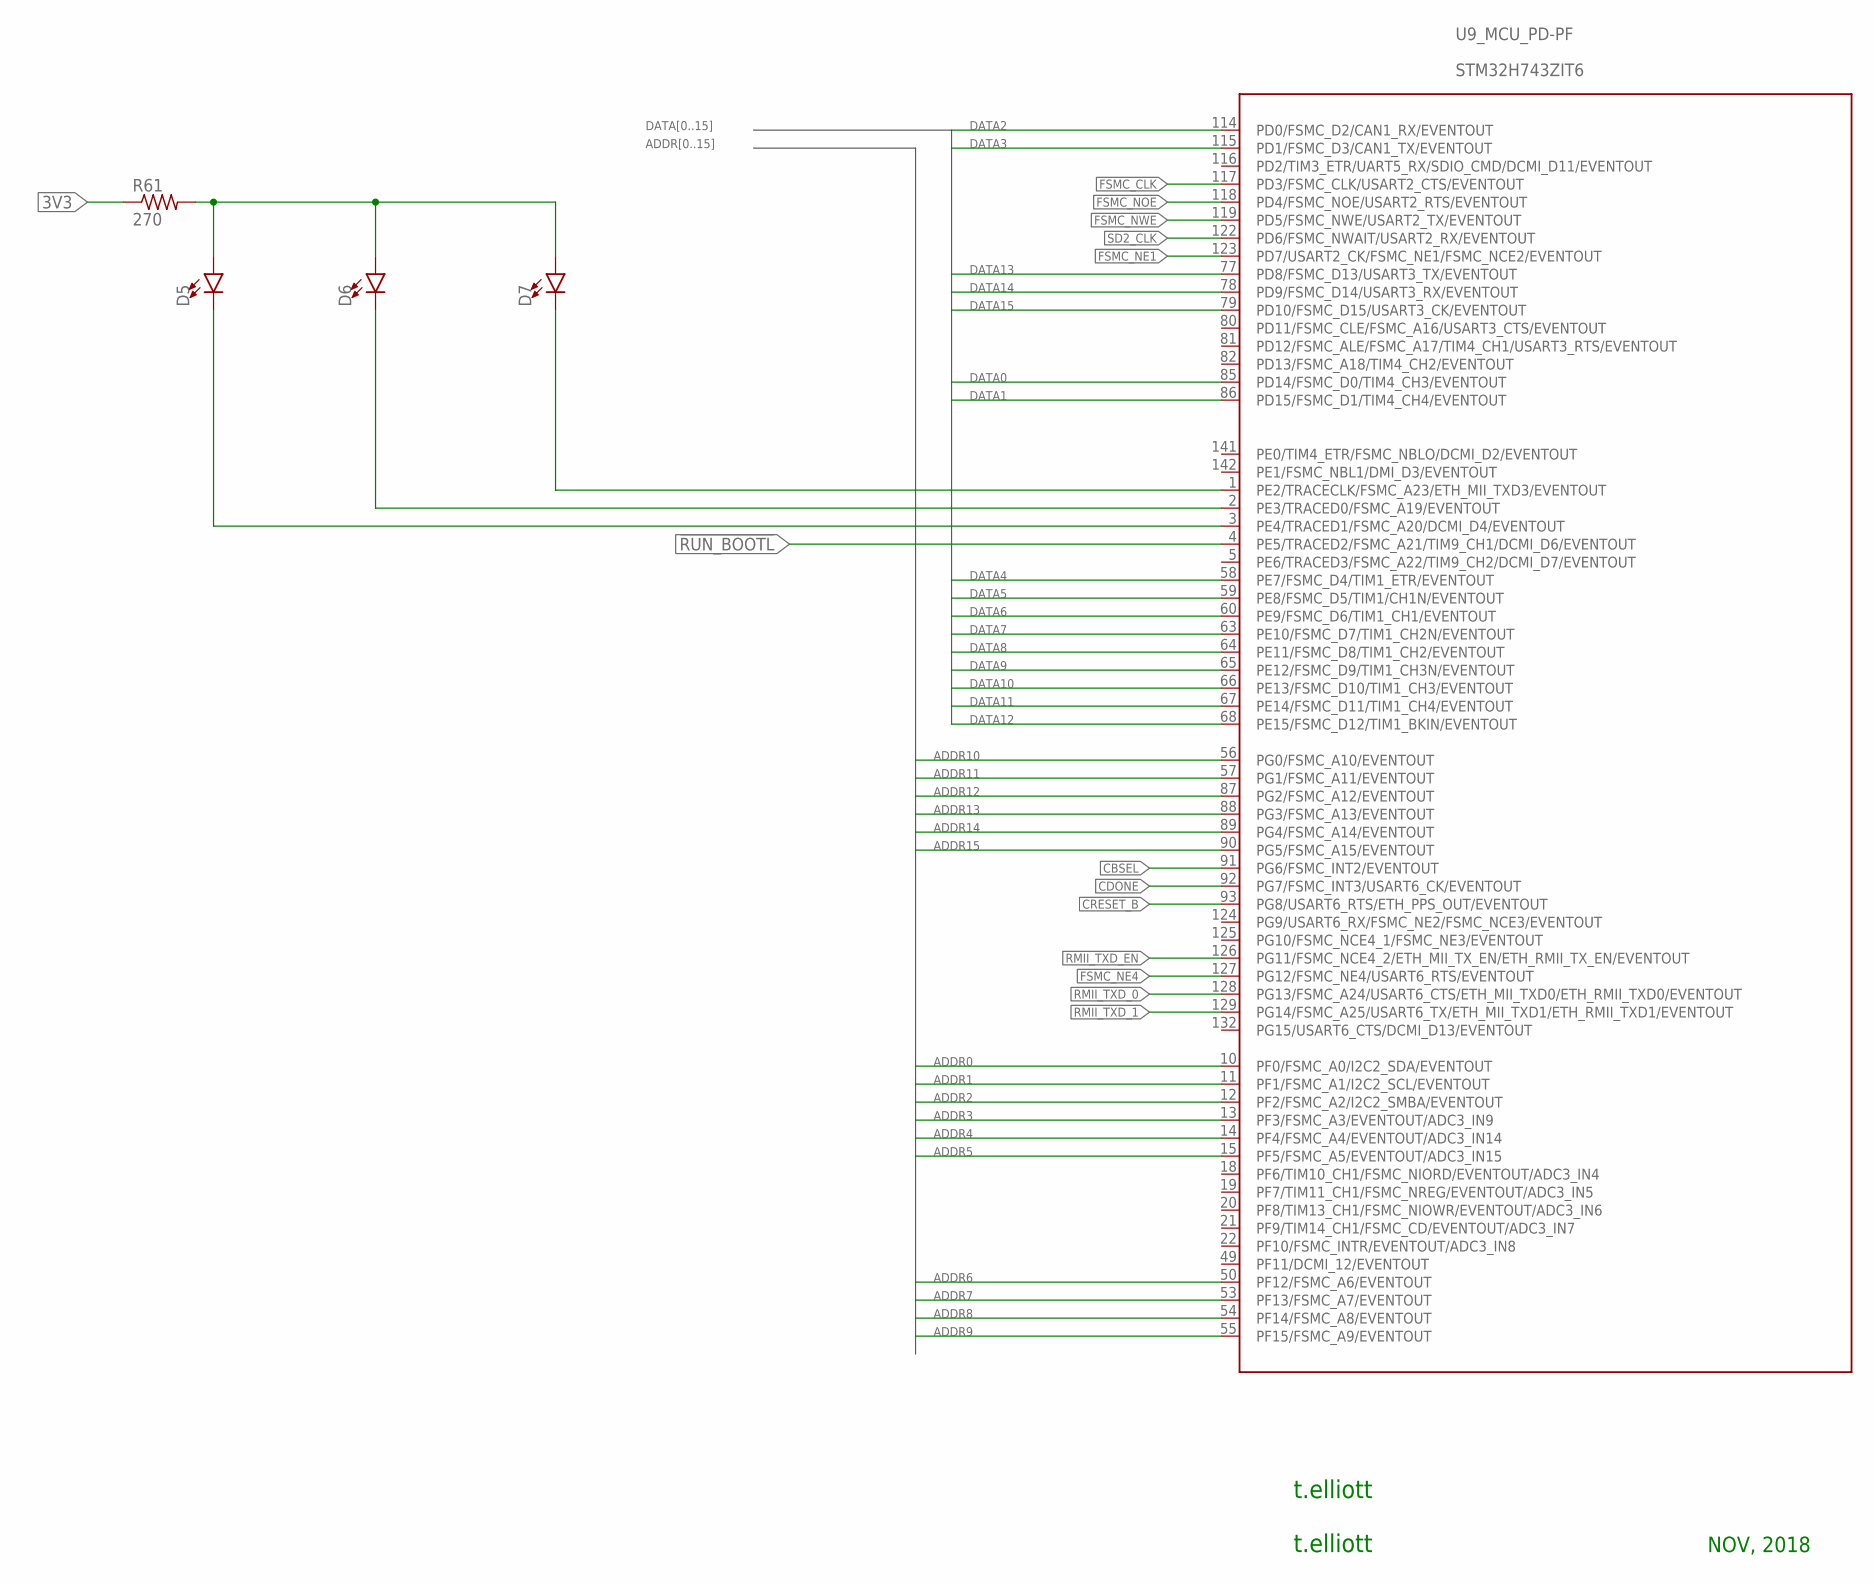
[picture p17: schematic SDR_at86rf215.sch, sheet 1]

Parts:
D5, D6, D7: LED1206; LED-1206
R61: 270; R0603
U9: STM32H743ZIT6; STM32F407_144

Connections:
3V3: R61.1; also elsewhere on the board
!RUN_BOOTL: U9.4 (PE5/TRACED2/FSMC_A21/TIM9_CH1/DCMI_D6/E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)
ADDR0: U9.10 (PF0/FSMC_A0/I2C2_SDA/EVENTOUT); also elsewhere on the board
ADDR1: U9.11 (PF1/FSMC_A1/I2C2_SCL/EVENTOUT); also elsewhere on the board
ADDR2: U9.12 (PF2/FSMC_A2/I2C2_SMBA/EVENTOUT); also elsewhere on the board
ADDR3: U9.13 (PF3/FSMC_A3/EVENTOUT/ADC3_IN9); also elsewhere on the board
ADDR4: U9.14 (PF4/FSMC_A4/EVENTOUT/ADC3_IN14); also elsewhere on the board
ADDR5: U9.15 (PF5/FSMC_A5/EVENTOUT/ADC3_IN15); also elsewhere on the board
ADDR6: U9.50 (PF12/FSMC_A6/EVENTOUT); also elsewhere on the board
ADDR7: U9.53 (PF13/FSMC_A7/EVENTOUT); also elsewhere on the board
ADDR8: U9.54 (PF14/FSMC_A8/EVENTOUT); also elsewhere on the board
ADDR9: U9.55 (PF15/FSMC_A9/EVENTOUT); also elsewhere on the board
ADDR10: U9.56 (PG0/FSMC_A10/EVENTOUT); also elsewhere on the board
ADDR11: U9.57 (PG1/FSMC_A11/EVENTOUT); also elsewhere on the board
ADDR12: U9.87 (PG2/FSMC_A12/EVENTOUT); also elsewhere on the board
ADDR13: U9.88 (PG3/FSMC_A13/EVENTOUT); also elsewhere on the board
ADDR14: U9.89 (PG4/FSMC_A14/EVENTOUT); also elsewhere on the board
ADDR15: U9.90 (PG5/FSMC_A15/EVENTOUT); also elsewhere on the board
CBSEL: U9.91 (PG6/FSMC_INT2/EVENTOUT); also elsewhere on the board
CDONE: U9.92 (PG7/FSMC_INT3/USART6_CK/EVENTOUT); also elsewhere on the board
CRESET_B: U9.93 (PG8/USART6_RTS/ETH_PPS_OUT/EVENTOUT); also elsewhere on the board
DATA0: U9.85 (PD14/FSMC_D0/TIM4_CH3/EVENTOUT); also elsewhere on the board
DATA1: U9.86 (PD15/FSMC_D1/TIM4_CH4/EVENTOUT); also elsewhere on the board
DATA2: U9.114 (PD0/FSMC_D2/CAN1_RX/EVENTOUT); also elsewhere on the board
DATA3: U9.115 (PD1/FSMC_D3/CAN1_TX/EVENTOUT); also elsewhere on the board
DATA4: U9.58 (PE7/FSMC_D4/TIM1_ETR/EVENTOUT); also elsewhere on the board
DATA5: U9.59 (PE8/FSMC_D5/TIM1/CH1N/EVENTOUT); also elsewhere on the board
DATA6: U9.60 (PE9/FSMC_D6/TIM1_CH1/EVENTOUT); also elsewhere on the board
DATA7: U9.63 (PE10/FSMC_D7/TIM1_CH2N/EVENTOUT); also elsewhere on the board
DATA8: U9.64 (PE11/FSMC_D8/TIM1_CH2/EVENTOUT); also elsewhere on the board
DATA9: U9.65 (PE12/FSMC_D9/TIM1_CH3N/EVENTOUT); also elsewhere on the board
DATA10: U9.66 (PE13/FSMC_D10/TIM1_CH3/EVENTOUT); also elsewhere on the board
DATA11: U9.67 (PE14/FSMC_D11/TIM1_CH4/EVENTOUT); also elsewhere on the board
DATA12: U9.68 (PE15/FSMC_D12/TIM1_BKIN/EVENTOUT); also elsewhere on the board
DATA13: U9.77 (PD8/FSMC_D13/USART3_TX/EVENTOUT); also elsewhere on the board
DATA14: U9.78 (PD9/FSMC_D14/USART3_RX/EVENTOUT); also elsewhere on the board
DATA15: U9.79 (PD10/FSMC_D15/USART3_CK/EVENTOUT); also elsewhere on the board
FSMC_CLK: U9.117 (PD3/FSMC_CLK/USART2_CTS/EVENTOUT); also elsewhere on the board
FSMC_NE1: U9.123 (PD7/USART2_CK/FSMC_NE1/FSMC_NCE2/EVENTO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); also elsewhere on the board
FSMC_NE4: U9.127 (PG12/FSMC_NE4/USART6_RTS/EVENTOUT); also elsewhere on the board
FSMC_NOE: U9.118 (PD4/FSMC_NOE/USART2_RTS/EVENTOUT); also elsewhere on the board
FSMC_NWE: U9.119 (PD5/FSMC_NWE/USART2_TX/EVENTOUT); also elsewhere on the board
unnamed: D5.A, D6.A, D7.A, R61.2
unnamed: D7.C, U9.1 (PE2/TRACECLK/FSMC_A23/ETH_MII_TXD3/EVEN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)
unnamed: D6.C, U9.2 (PE3/TRACED0/FSMC_A19/EVENTOUT)
unnamed: D5.C, U9.3 (PE4/TRACED1/FSMC_A20/DCMI_D4/EVENTOUT)
RMII_TXD_0: U9.128 (PG13/FSMC_A24/USART6_CTS/ETH_MII_TXD0/E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); also elsewhere on the board
RMII_TXD_1: U9.129 (PG14/FSMC_A25/USART6_TX/ETH_MII_TXD1/ET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); also elsewhere on the board
RMII_TXD_EN: U9.126 (PG11/FSMC_NCE4_2/ETH_MII_TX_EN/ETH_RMII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); also elsewhere on the board
SD2_CLK: U9.122 (PD6/FSMC_NWAIT/USART2_RX/EVENTOUT); also elsewhere on the board

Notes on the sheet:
t.elliott
NOV, 2018

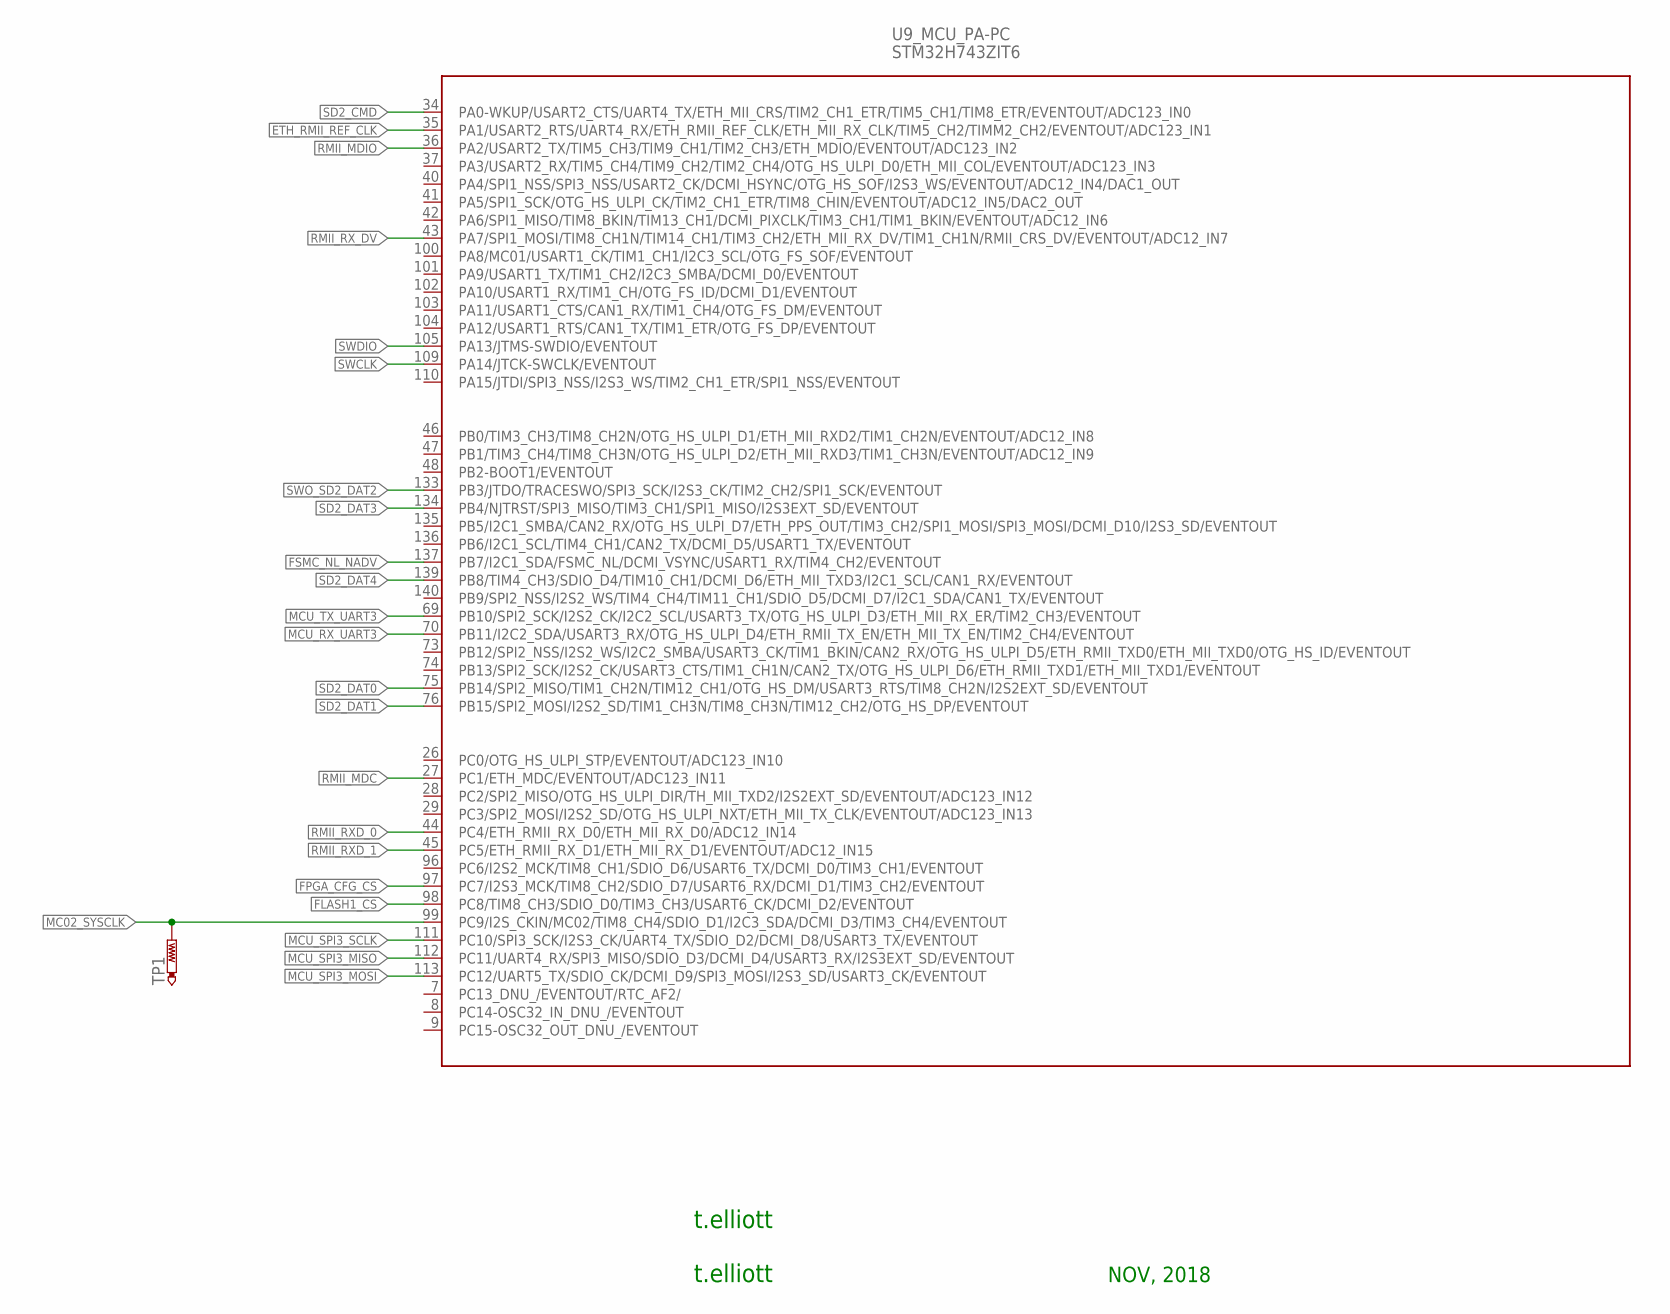
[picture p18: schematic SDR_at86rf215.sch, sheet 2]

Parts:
TP1: PTR1TP08R; TP08R
U9: STM32H743ZIT6; STM32F407_144

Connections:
ETH_RMII_REF_CLK: U9.35 (PA1/USART2_RTS/UART4_RX/ETH_RMII_REF_CL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); also elsewhere on the board
FLASH1_CS: U9.98 (PC8/TIM8_CH3/SDIO_D0/TIM3_CH3/USART6_CK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)
FPGA_CFG_CS: U9.97 (PC7/I2S3_MCK/TIM8_CH2/SDIO_D7/USART6_RX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); also elsewhere on the board
FSMC_NL_NADV: U9.137 (PB7/I2C1_SDA/FSMC_NL/DCMI_VSYNC/USART1_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); also elsewhere on the board
MC02_SYSCLK: TP1.TP, U9.99 (PC9/I2S_CKIN/MC02/TIM8_CH4/SDIO_D1/I2C3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); also elsewhere on the board
MCU_RX_UART3: U9.70 (PB11/I2C2_SDA/USART3_RX/OTG_HS_ULPI_D4/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); also elsewhere on the board
MCU_SPI3_MISO: U9.112 (PC11/UART4_RX/SPI3_MISO/SDIO_D3/DCMI_D4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); also elsewhere on the board
MCU_SPI3_MOSI: U9.113 (PC12/UART5_TX/SDIO_CK/DCMI_D9/SPI3_MOSI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); also elsewhere on the board
MCU_SPI3_SCLK: U9.111 (PC10/SPI3_SCK/I2S3_CK/UART4_TX/SDIO_D2/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); also elsewhere on the board
MCU_TX_UART3: U9.69 (PB10/SPI2_SCK/I2S2_CK/I2C2_SCL/USART3_T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); also elsewhere on the board
RMII_MDC: U9.27 (PC1/ETH_MDC/EVENTOUT/ADC123_IN11); also elsewhere on the board
RMII_MDIO: U9.36 (PA2/USART2_TX/TIM5_CH3/TIM9_CH1/TIM2_CH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); also elsewhere on the board
RMII_RXD_0: U9.44 (PC4/ETH_RMII_RX_D0/ETH_MII_RX_D0/ADC12_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); also elsewhere on the board
RMII_RXD_1: U9.45 (PC5/ETH_RMII_RX_D1/ETH_MII_RX_D1/EVENTO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); also elsewhere on the board
RMII_RX_DV: U9.43 (PA7/SPI1_MOSI/TIM8_CH1N/TIM14_CH1/TIM3_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); also elsewhere on the board
SD2_CMD: U9.34 (PA0-WKUP/USART2_CTS/UART4_TX/ETH_MII_CR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); also elsewhere on the board
SD2_DAT0: U9.75 (PB14/SPI2_MISO/TIM1_CH2N/TIM12_CH1/OTG_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); also elsewhere on the board
SD2_DAT1: U9.76 (PB15/SPI2_MOSI/I2S2_SD/TIM1_CH3N/TIM8_C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); also elsewhere on the board
SD2_DAT3: U9.134 (PB4/NJTRST/SPI3_MISO/TIM3_CH1/SPI1_MISO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); also elsewhere on the board
SD2_DAT4: U9.139 (PB8/TIM4_CH3/SDIO_D4/TIM10_CH1/DCMI_D6/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)
SWCLK: U9.109 (PA14/JTCK-SWCLK/EVENTOUT); also elsewhere on the board
SWDIO: U9.105 (PA13/JTMS-SWDIO/EVENTOUT); also elsewhere on the board
SWO_SD2_DAT2: U9.133 (PB3/JTDO/TRACESWO/SPI3_SCK/I2S3_CK/TIM2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); also elsewhere on the board

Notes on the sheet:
t.elliott
NOV, 2018

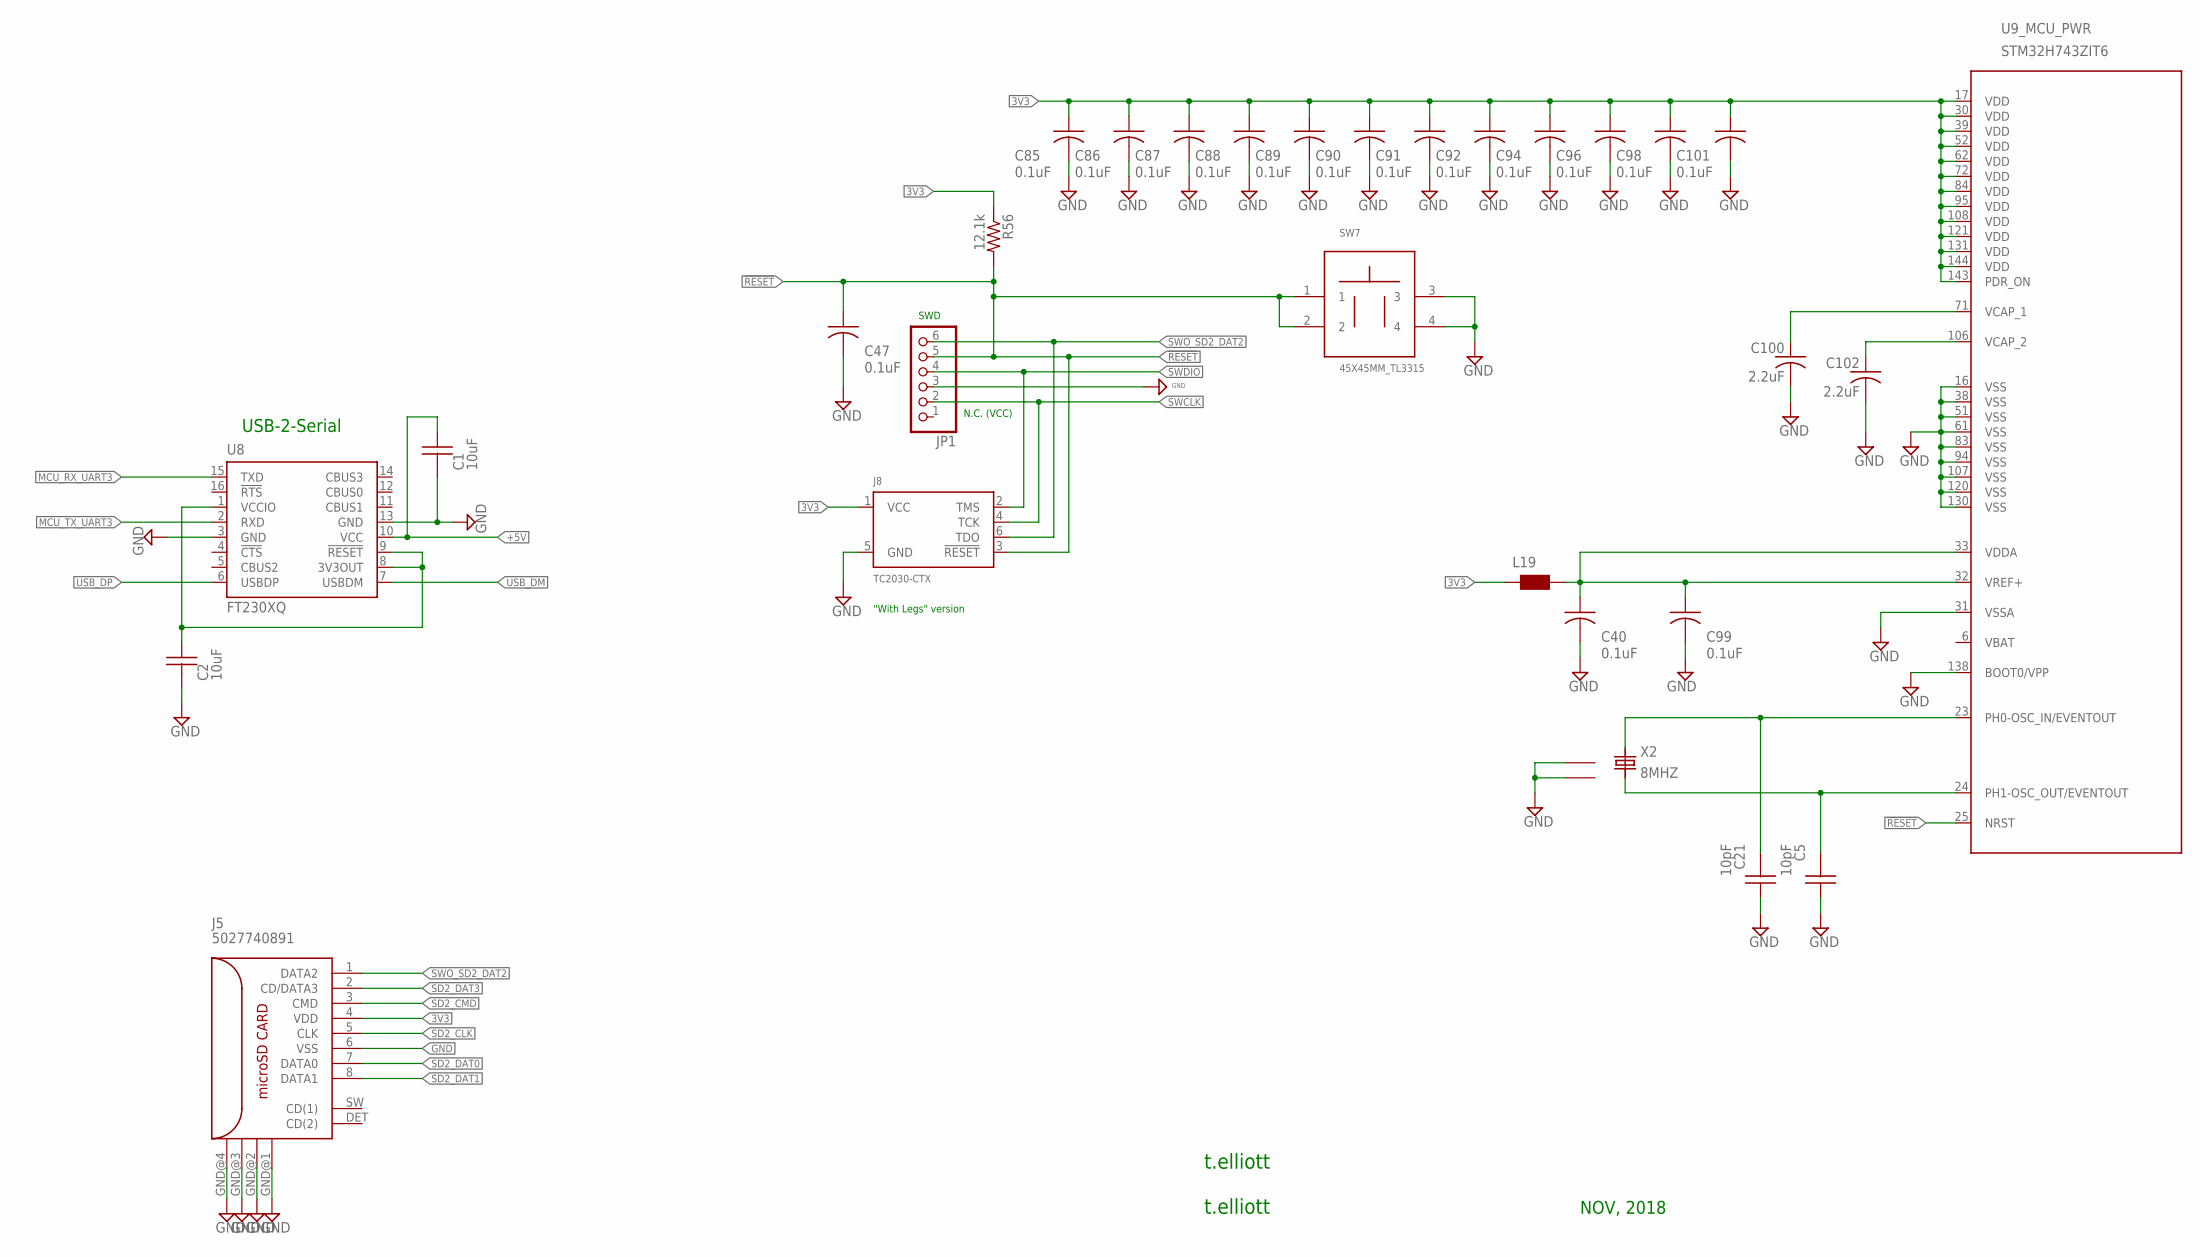
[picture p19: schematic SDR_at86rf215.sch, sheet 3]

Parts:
C1, C2: 10uF; C0805
C5, C21: 10pF; C0402
C40, C47, C85, C86, C87, C88, C89, C90, C91, C92, C94, C96, C98, C99, C101: 0.1uF; 0402
C100, C102: 2.2uF; C0805
J5: 5027740891; SD-502774-001
J8: TC2030-CTX; TC2030-IDC
JP1: PINHD-1X6; 1X06
L19: WE-CBF_0603; 0603
R56: 12.1k; R0603
SW7: 45X45MM_TL3315; PBUT_SW_TACTILE_4_5MMX4_5MM
U8: FT230XQ; QFN16
U9: STM32H743ZIT6; STM32F407_144
X2: 8MHZ; ECS-250-20-30B-DU_CRYSTAL

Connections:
3V3: C85.1 (A), C86.1 (A), C87.1 (A), C88.1 (A), C89.1 (A), C90.1 (A), C91.1 (A), C92.1 (A), C94.1 (A), C96.1 (A), C98.1 (A), C101.1 (A), J5.4 (VDD), J8.1 (VCC), L19.1, R56.1, U9.17 (VDD), U9.30 (VDD), U9.39 (VDD), U9.52 (VDD), U9.62 (VDD), U9.72 (VDD), U9.84 (VDD), U9.95 (VDD), U9.108 (VDD), U9.121 (VDD), U9.131 (VDD), U9.143 (PDR_ON), U9.144 (VDD); also elsewhere on the board
3V_ANALOG: C40.1 (A), C99.1 (A), L19.2, U9.32 (VREF+), U9.33 (VDDA)
20MHZ_REF: C21.2, U9.23 (PH0-OSC_IN/EVENTOUT), X2.1
!RESET: C47.1 (A), J8.3 (!RESET), JP1.5, R56.2, SW7.1, SW7.2, U9.25 (NRST); also elsewhere on the board
+5V: C1.1, U8.10 (VCC); also elsewhere on the board
GND: C1.2, C2.2, C5.1, C21.1, C40.2 (C), C47.2 (C), C85.2 (C), C86.2 (C), C87.2 (C), C88.2 (C), C89.2 (C), C90.2 (C), C91.2 (C), C92.2 (C), C94.2 (C), C96.2 (C), C98.2 (C), C99.2 (C), C100.2, C101.2 (C), C102.2, J5.6 (VSS), J5.GND@1 (GND), J5.GND@2 (GND), J5.GND@3 (GND), J5.GND@4 (GND), J8.5 (GND), JP1.3, SW7.3, SW7.4, U8.3 (GND), U8.13 (GND), U9.16 (VSS), U9.31 (VSSA), U9.38 (VSS), U9.51 (VSS), U9.61 (VSS), U9.83 (VSS), U9.94 (VSS), U9.107 (VSS), U9.120 (VSS), U9.130 (VSS), U9.138 (BOOT0/VPP), X2.GND@1 (1), X2.GND@2 (2); also elsewhere on the board
MCU_RX_UART3: U8.15 (TXD); also elsewhere on the board
MCU_TX_UART3: U8.2 (RXD); also elsewhere on the board
unnamed: C102.1, U9.106 (VCAP_2)
unnamed: C2.1, U8.1 (VCCIO), U8.8 (3V3OUT), U8.9 (!RESET)
unnamed: C100.1, U9.71 (VCAP_1)
SD2_CLK: J5.5 (CLK); also elsewhere on the board
SD2_CMD: J5.3 (CMD); also elsewhere on the board
SD2_DAT0: J5.7 (DATA0); also elsewhere on the board
SD2_DAT1: J5.8 (DATA1); also elsewhere on the board
SD2_DAT3: J5.2 (CD/DATA3); also elsewhere on the board
SWCLK: J8.4 (TCK), JP1.2; also elsewhere on the board
SWDIO: J8.2 (TMS), JP1.4; also elsewhere on the board
SWO_SD2_DAT2: J5.1 (DATA2), J8.6 (TDO), JP1.6; also elsewhere on the board
USB_DM: U8.7 (USBDM); also elsewhere on the board
USB_DP: U8.6 (USBDP); also elsewhere on the board
X2: C5.2, U9.24 (PH1-OSC_OUT/EVENTOUT), X2.3

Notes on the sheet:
t.elliott
SWD
USB-2-Serial
N.C. (VCC)
"With Legs" version
NOV, 2018

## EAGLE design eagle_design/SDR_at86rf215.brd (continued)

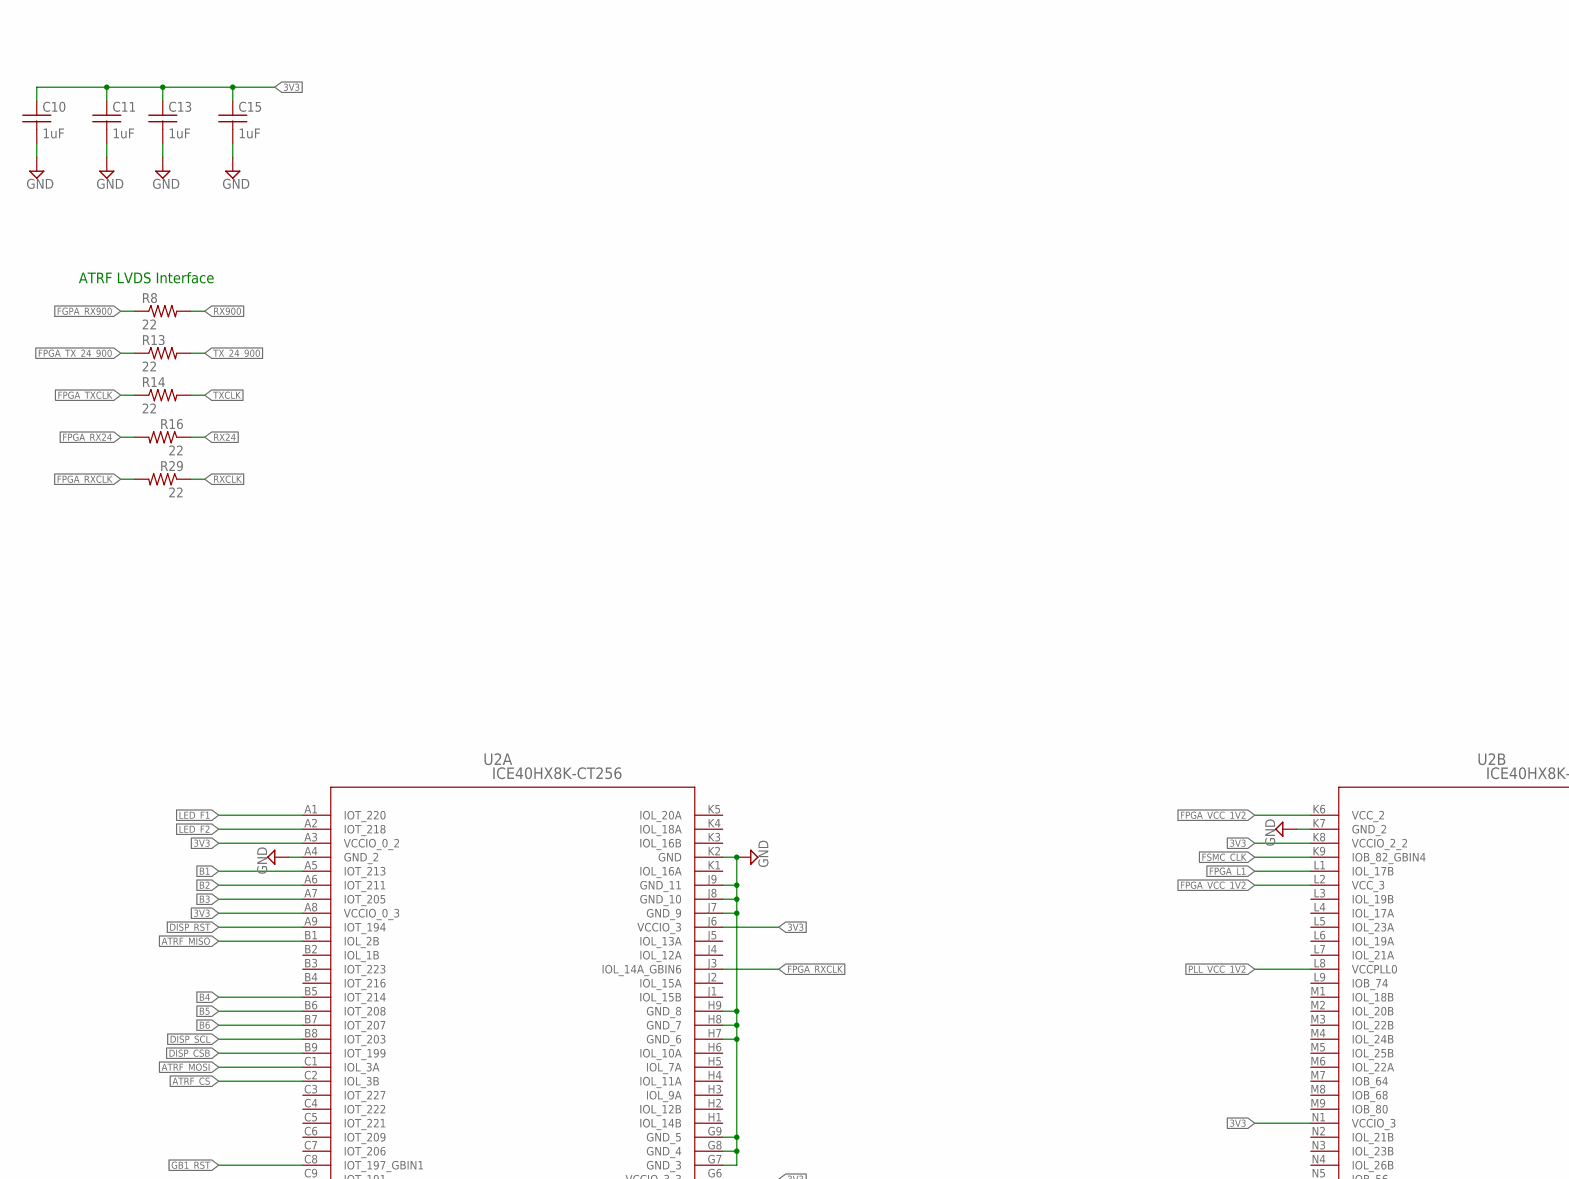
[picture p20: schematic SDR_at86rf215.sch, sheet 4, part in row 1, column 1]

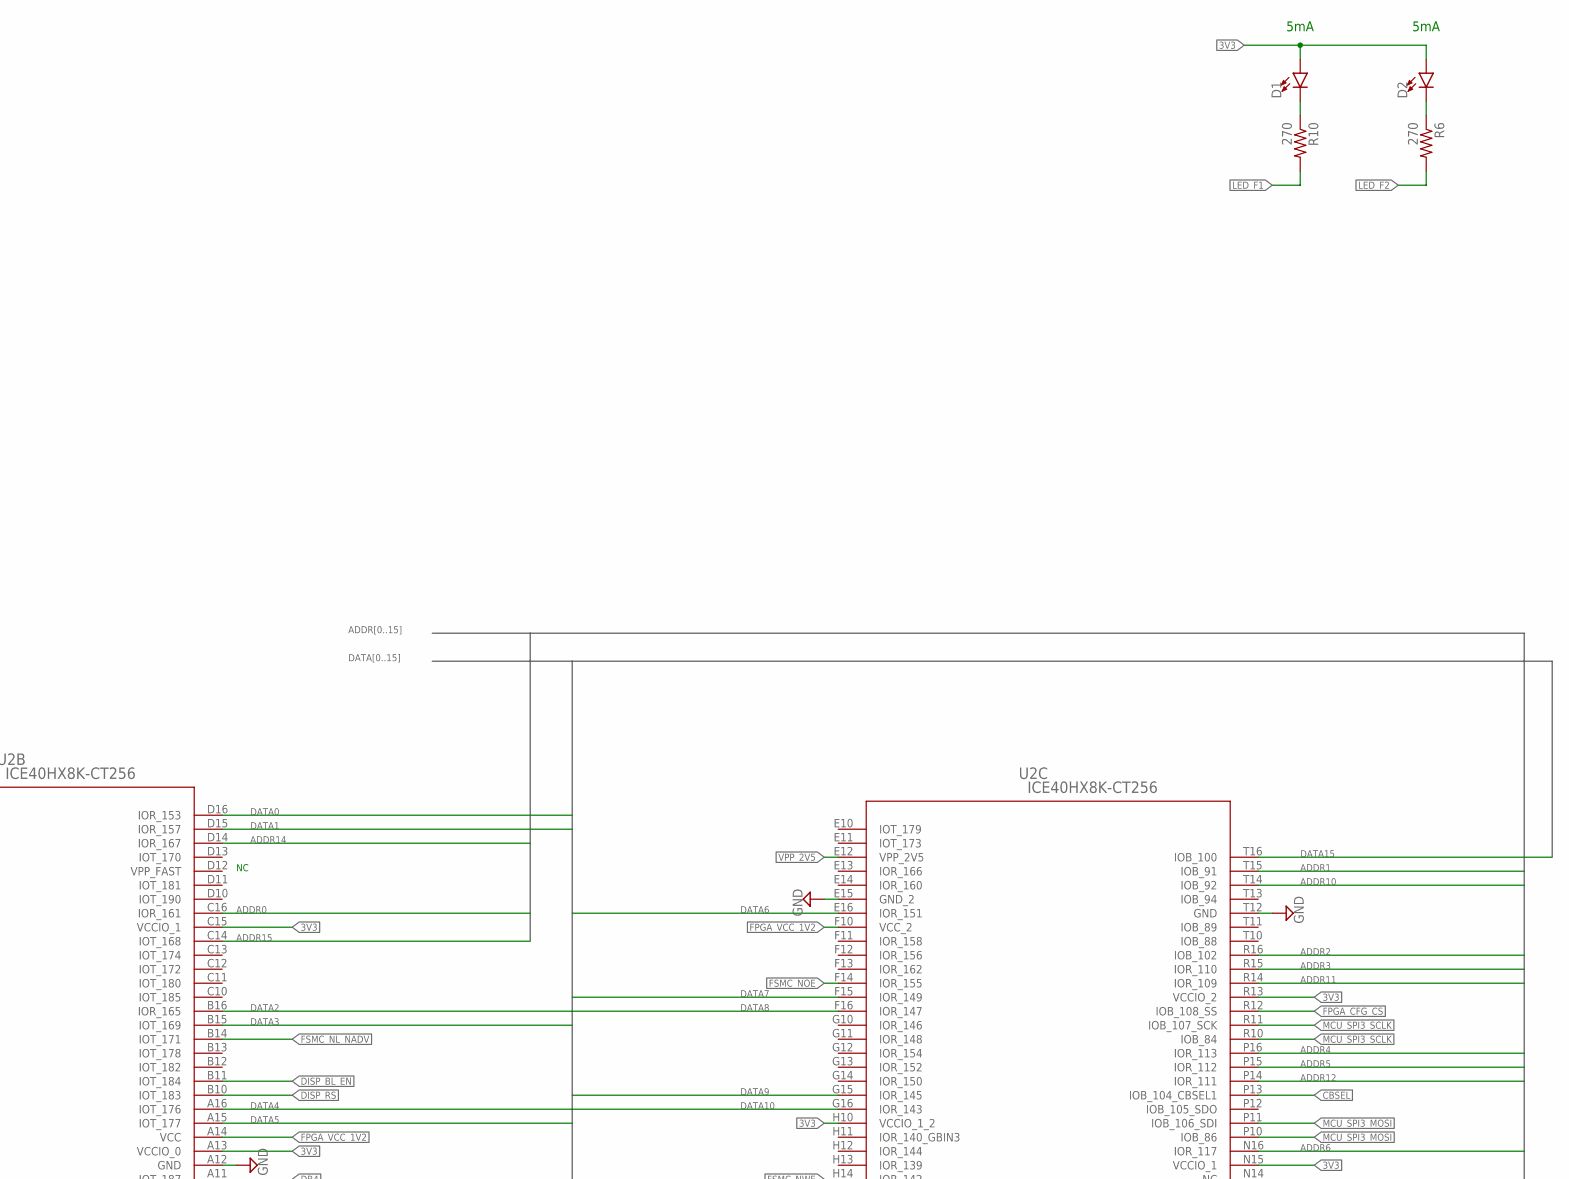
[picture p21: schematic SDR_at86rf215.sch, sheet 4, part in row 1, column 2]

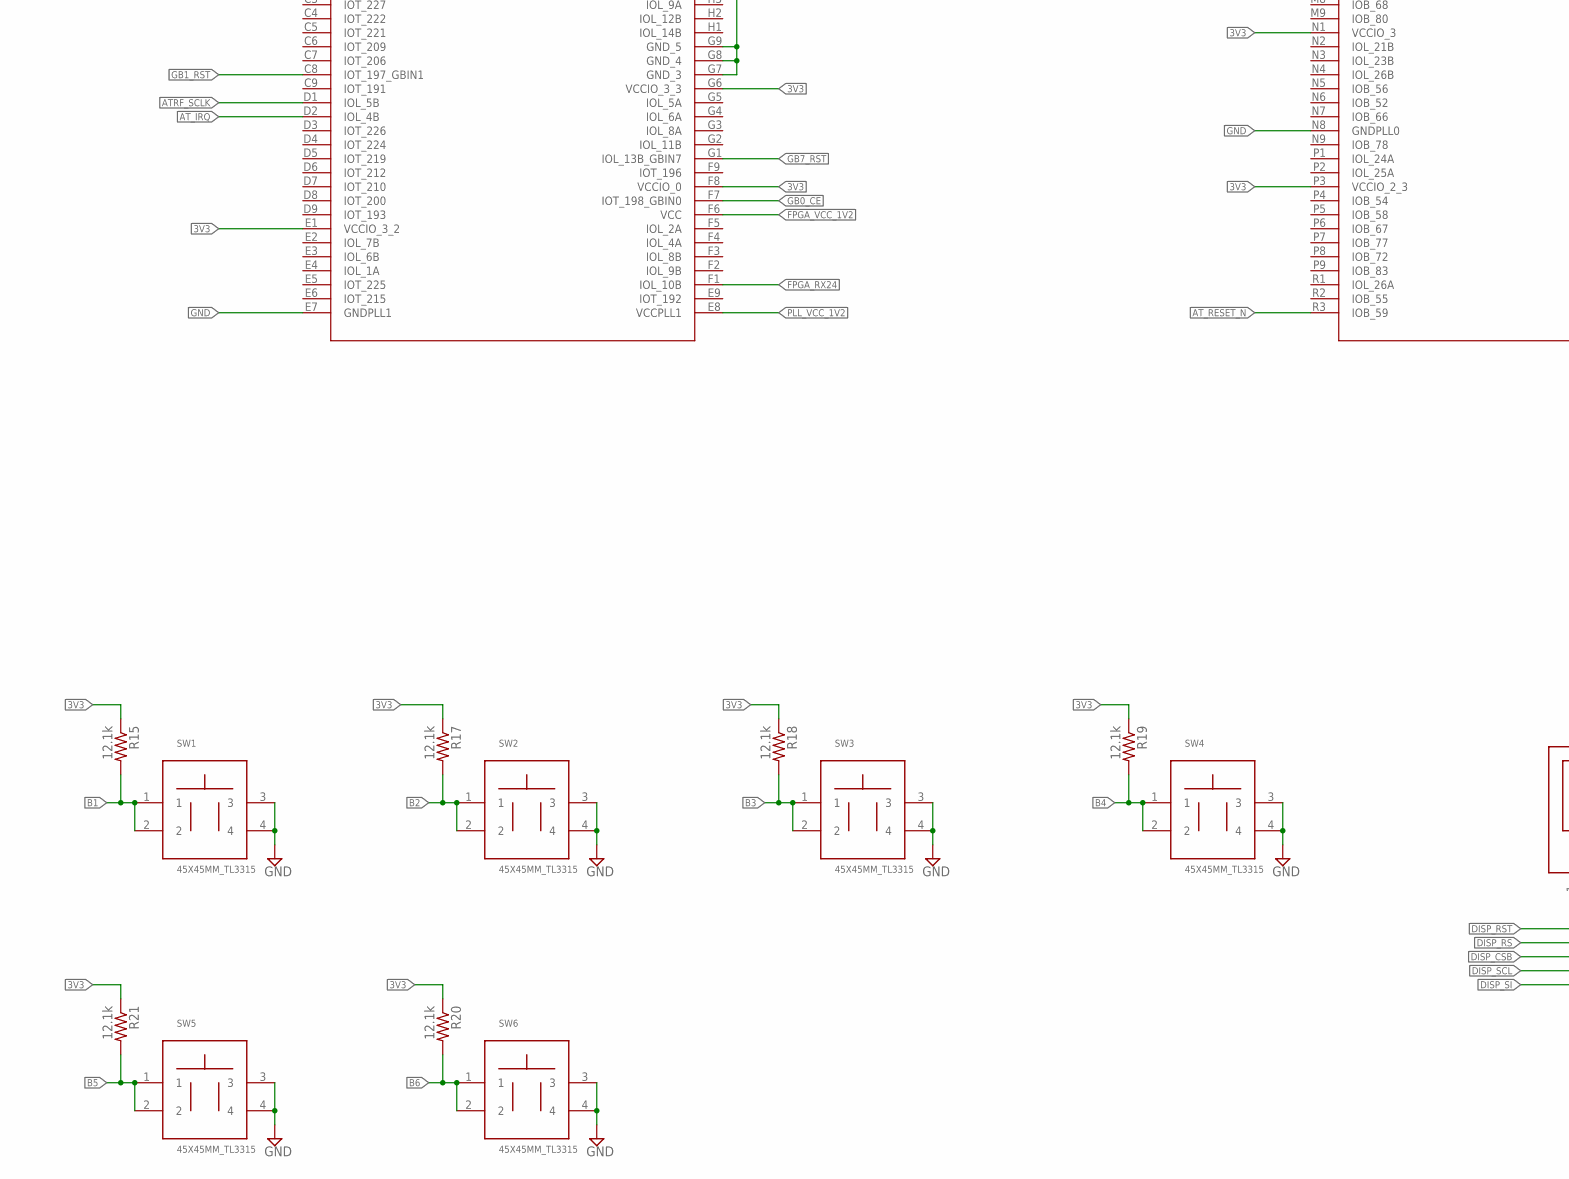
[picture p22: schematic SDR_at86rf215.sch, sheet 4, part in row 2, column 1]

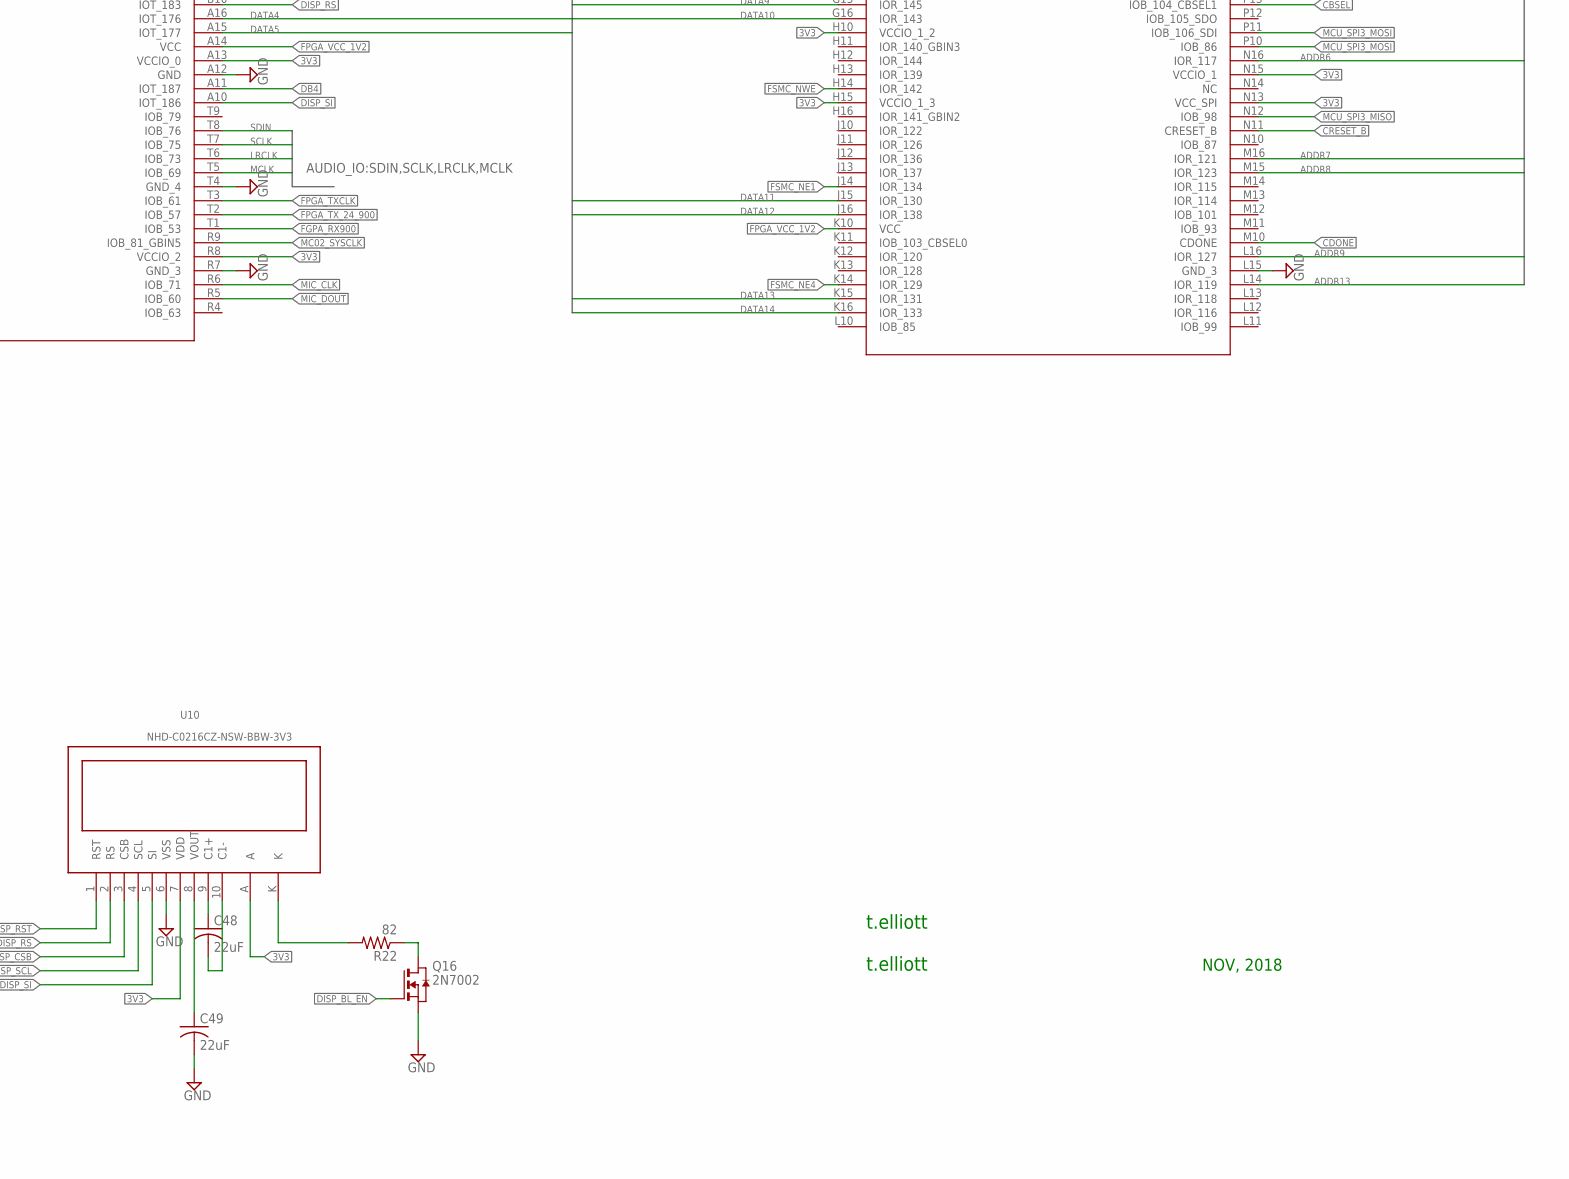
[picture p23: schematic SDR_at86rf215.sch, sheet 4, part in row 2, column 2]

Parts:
C10, C11, C13, C15: 1uF; C0603
C48, C49: 22uF; 1210K
D1, D2: LED1206; LED-1206
Q16: 2N7002; SOT23_2N7002_PACKAGE
R6, R10: 270; R0603
R8, R13, R14, R16, R29: 22; R0603_COMPACT
R15, R17, R18, R19, R20, R21: 12.1k; R0603
R22: 82; R1206
SW1, SW2, SW3, SW4, SW5, SW6: 45X45MM_TL3315; PBUT_SW_TACTILE_4_5MMX4_5MM
U2: ICE40HX8K-CT256; CABGA256
U10: NHD-C0216CZ-NSW-BBW-3V3

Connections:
3V3: C10.1, C11.1, C13.1, C15.1, D1.A, D2.A, R15.1, R17.1, R18.1, R19.1, R20.1, R21.1, U2.A3 (VCCIO_0_2), U2.A8 (VCCIO_0_3), U2.A13 (VCCIO_0), U2.C15 (VCCIO_1), U2.E1 (VCCIO_3_2), U2.F8 (VCCIO_0), U2.G6 (VCCIO_3_3), U2.H10 (VCCIO_1_2), U2.H15 (VCCIO_1_3), U2.J6 (VCCIO_3), U2.K8 (VCCIO_2_2), U2.N1 (VCCIO_3), U2.N13 (VCC_SPI), U2.N15 (VCCIO_1), U2.P3 (VCCIO_2_3), U2.R8 (VCCIO_2), U2.R13 (VCCIO_2), U10.7 (VDD), U10.A; also elsewhere on the board
ADDR0: U2.C16 (IOR_161); also elsewhere on the board
ADDR1: U2.T15 (IOB_91); also elsewhere on the board
ADDR2: U2.R16 (IOB_102); also elsewhere on the board
ADDR3: U2.R15 (IOR_110); also elsewhere on the board
ADDR4: U2.P16 (IOR_113); also elsewhere on the board
ADDR5: U2.P15 (IOR_112); also elsewhere on the board
ADDR6: U2.N16 (IOR_117); also elsewhere on the board
ADDR7: U2.M16 (IOR_121); also elsewhere on the board
ADDR8: U2.M15 (IOR_123); also elsewhere on the board
ADDR9: U2.L16 (IOR_127); also elsewhere on the board
ADDR10: U2.T14 (IOB_92); also elsewhere on the board
ADDR11: U2.R14 (IOR_109); also elsewhere on the board
ADDR12: U2.P14 (IOR_111); also elsewhere on the board
ADDR13: U2.L14 (IOR_119); also elsewhere on the board
ADDR14: U2.D14 (IOR_167); also elsewhere on the board
ADDR15: U2.C14 (IOT_168); also elsewhere on the board
ATRF_CS: U2.C2 (IOL_3B); also elsewhere on the board
ATRF_MISO: U2.B1 (IOL_2B); also elsewhere on the board
ATRF_MOSI: U2.C1 (IOL_3A); also elsewhere on the board
ATRF_SCLK: U2.D1 (IOL_5B); also elsewhere on the board
AT_IRQ: U2.D2 (IOL_4B); also elsewhere on the board
AT_RESET_N: U2.R3 (IOB_59); also elsewhere on the board
B1: R15.2, SW1.1, SW1.2, U2.A5 (IOT_213)
B2: R17.2, SW2.1, SW2.2, U2.A6 (IOT_211)
B3: R18.2, SW3.1, SW3.2, U2.A7 (IOT_205)
B4: R19.2, SW4.1, SW4.2, U2.B5 (IOT_214)
B5: R21.2, SW5.1, SW5.2, U2.B6 (IOT_208)
B6: R20.2, SW6.1, SW6.2, U2.B7 (IOT_207)
CBSEL: U2.P13 (IOB_104_CBSEL1); also elsewhere on the board
CDONE: U2.M10 (CDONE); also elsewhere on the board
CRESET_B: U2.N11 (CRESET_B); also elsewhere on the board
DATA0: U2.D16 (IOR_153); also elsewhere on the board
DATA1: U2.D15 (IOR_157); also elsewhere on the board
DATA2: U2.B16 (IOR_165); also elsewhere on the board
DATA3: U2.B15 (IOT_169); also elsewhere on the board
DATA4: U2.A16 (IOT_176); also elsewhere on the board
DATA5: U2.A15 (IOT_177); also elsewhere on the board
DATA6: U2.E16 (IOR_151); also elsewhere on the board
DATA7: U2.F15 (IOR_149); also elsewhere on the board
DATA8: U2.F16 (IOR_147); also elsewhere on the board
DATA9: U2.G15 (IOR_145); also elsewhere on the board
DATA10: U2.G16 (IOR_143); also elsewhere on the board
DATA11: U2.J15 (IOR_130); also elsewhere on the board
DATA12: U2.J16 (IOR_138); also elsewhere on the board
DATA13: U2.K15 (IOR_131); also elsewhere on the board
DATA14: U2.K16 (IOR_133); also elsewhere on the board
DATA15: U2.T16 (IOB_100); also elsewhere on the board
DB4: U2.A11 (IOT_187)
DISP_BL_EN: Q16.1 (G), U2.B11 (IOT_184)
DISP_CSB: U2.B9 (IOT_199), U10.3 (CSB)
DISP_RS: U2.B10 (IOT_183), U10.2 (RS)
DISP_RST: U2.A9 (IOT_194), U10.1 (RST)
DISP_SCL: U2.B8 (IOT_203), U10.4 (SCL)
DISP_SI: U2.A10 (IOT_186), U10.5 (SI)
FGPA_RX900: R8.1, U2.T1 (IOB_53)
FPGA_CFG_CS: U2.R12 (IOB_108_SS); also elsewhere on the board
FPGA_L1: U2.L1 (IOL_17B)
FPGA_RX24: R16.2, U2.F1 (IOL_10B)
FPGA_RXCLK: R29.2, U2.J3 (IOL_14A_GBIN6)
FPGA_TXCLK: R14.1, U2.T3 (IOB_61)
FPGA_TX_24_900: R13.1, U2.T2 (IOB_57)
FPGA_VCC_1V2: U2.A14 (VCC), U2.F6 (VCC), U2.F10 (VCC_2), U2.K6 (VCC_2), U2.K10 (VCC), U2.L2 (VCC_3); also elsewhere on the board
FSMC_CLK: U2.K9 (IOB_82_GBIN4); also elsewhere on the board
FSMC_NE1: U2.J14 (IOR_134); also elsewhere on the board
FSMC_NE4: U2.K14 (IOR_129); also elsewhere on the board
FSMC_NL_NADV: U2.B14 (IOT_171); also elsewhere on the board
FSMC_NOE: U2.F14 (IOR_155); also elsewhere on the board
FSMC_NWE: U2.H14 (IOR_142); also elsewhere on the board
GB0_CE: U2.F7 (IOT_198_GBIN0)
GB1_RST: U2.C8 (IOT_197_GBIN1)
GB7_RST: U2.G1 (IOL_13B_GBIN7)
GND: C10.2, C11.2, C13.2, C15.2, C49.C, Q16.2 (S), SW1.3, SW1.4, SW2.3, SW2.4, SW3.3, SW3.4, SW4.3, SW4.4, SW5.3, SW5.4, SW6.3, SW6.4, U2.A4 (GND_2), U2.A12 (GND), U2.E7 (GNDPLL1), U2.E15 (GND_2), U2.G7 (GND_3), U2.G8 (GND_4), U2.G9 (GND_5), U2.H7 (GND_6), U2.H8 (GND_7), U2.H9 (GND_8), U2.J7 (GND_9), U2.J8 (GND_10), U2.J9 (GND_11), U2.K2 (GND), U2.K7 (GND_2), U2.L15 (GND_3), U2.N8 (GNDPLL0), U2.R7 (GND_3), U2.T4 (GND_4), U2.T12 (GND), U10.6 (VSS); also elsewhere on the board
LED_F1: R10.2, U2.A1 (IOT_220)
LED_F2: R6.2, U2.A2 (IOT_218)
LRCLK: U2.T6 (IOB_73); also elsewhere on the board
MC02_SYSCLK: U2.R9 (IOB_81_GBIN5); also elsewhere on the board
MCLK: U2.T5 (IOB_69); also elsewhere on the board
MCU_SPI3_MISO: U2.N12 (IOB_98); also elsewhere on the board
MCU_SPI3_MOSI: U2.P10 (IOB_86), U2.P11 (IOB_106_SDI); also elsewhere on the board
MCU_SPI3_SCLK: U2.R10 (IOB_84), U2.R11 (IOB_107_SCK); also elsewhere on the board
MIC_CLK: U2.R6 (IOB_71); also elsewhere on the board
MIC_DOUT: U2.R5 (IOB_60); also elsewhere on the board
unnamed: D1.C, R10.1
unnamed: D2.C, R6.1
unnamed: C48.A, U10.9 (C1+)
unnamed: C48.C, U10.10 (C1-)
unnamed: C49.A, U10.8 (VOUT)
unnamed: Q16.3 (D), R22.1
unnamed: R22.2, U10.K
PLL_VCC_1V2: U2.E8 (VCCPLL1), U2.L8 (VCCPLL0); also elsewhere on the board
RX24: R16.1; also elsewhere on the board
RX900: R8.2; also elsewhere on the board
RXCLK: R29.1; also elsewhere on the board
SCLK: U2.T7 (IOB_75); also elsewhere on the board
SDIN: U2.T8 (IOB_76); also elsewhere on the board
TXCLK: R14.2; also elsewhere on the board
TX_24_900: R13.2; also elsewhere on the board
VPP_2V5: U2.E12 (VPP_2V5); also elsewhere on the board
VPP_FAST: U2.D12 (VPP_FAST)

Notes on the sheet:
5mA
t.elliott
ATRF LVDS Interface
NOV, 2018

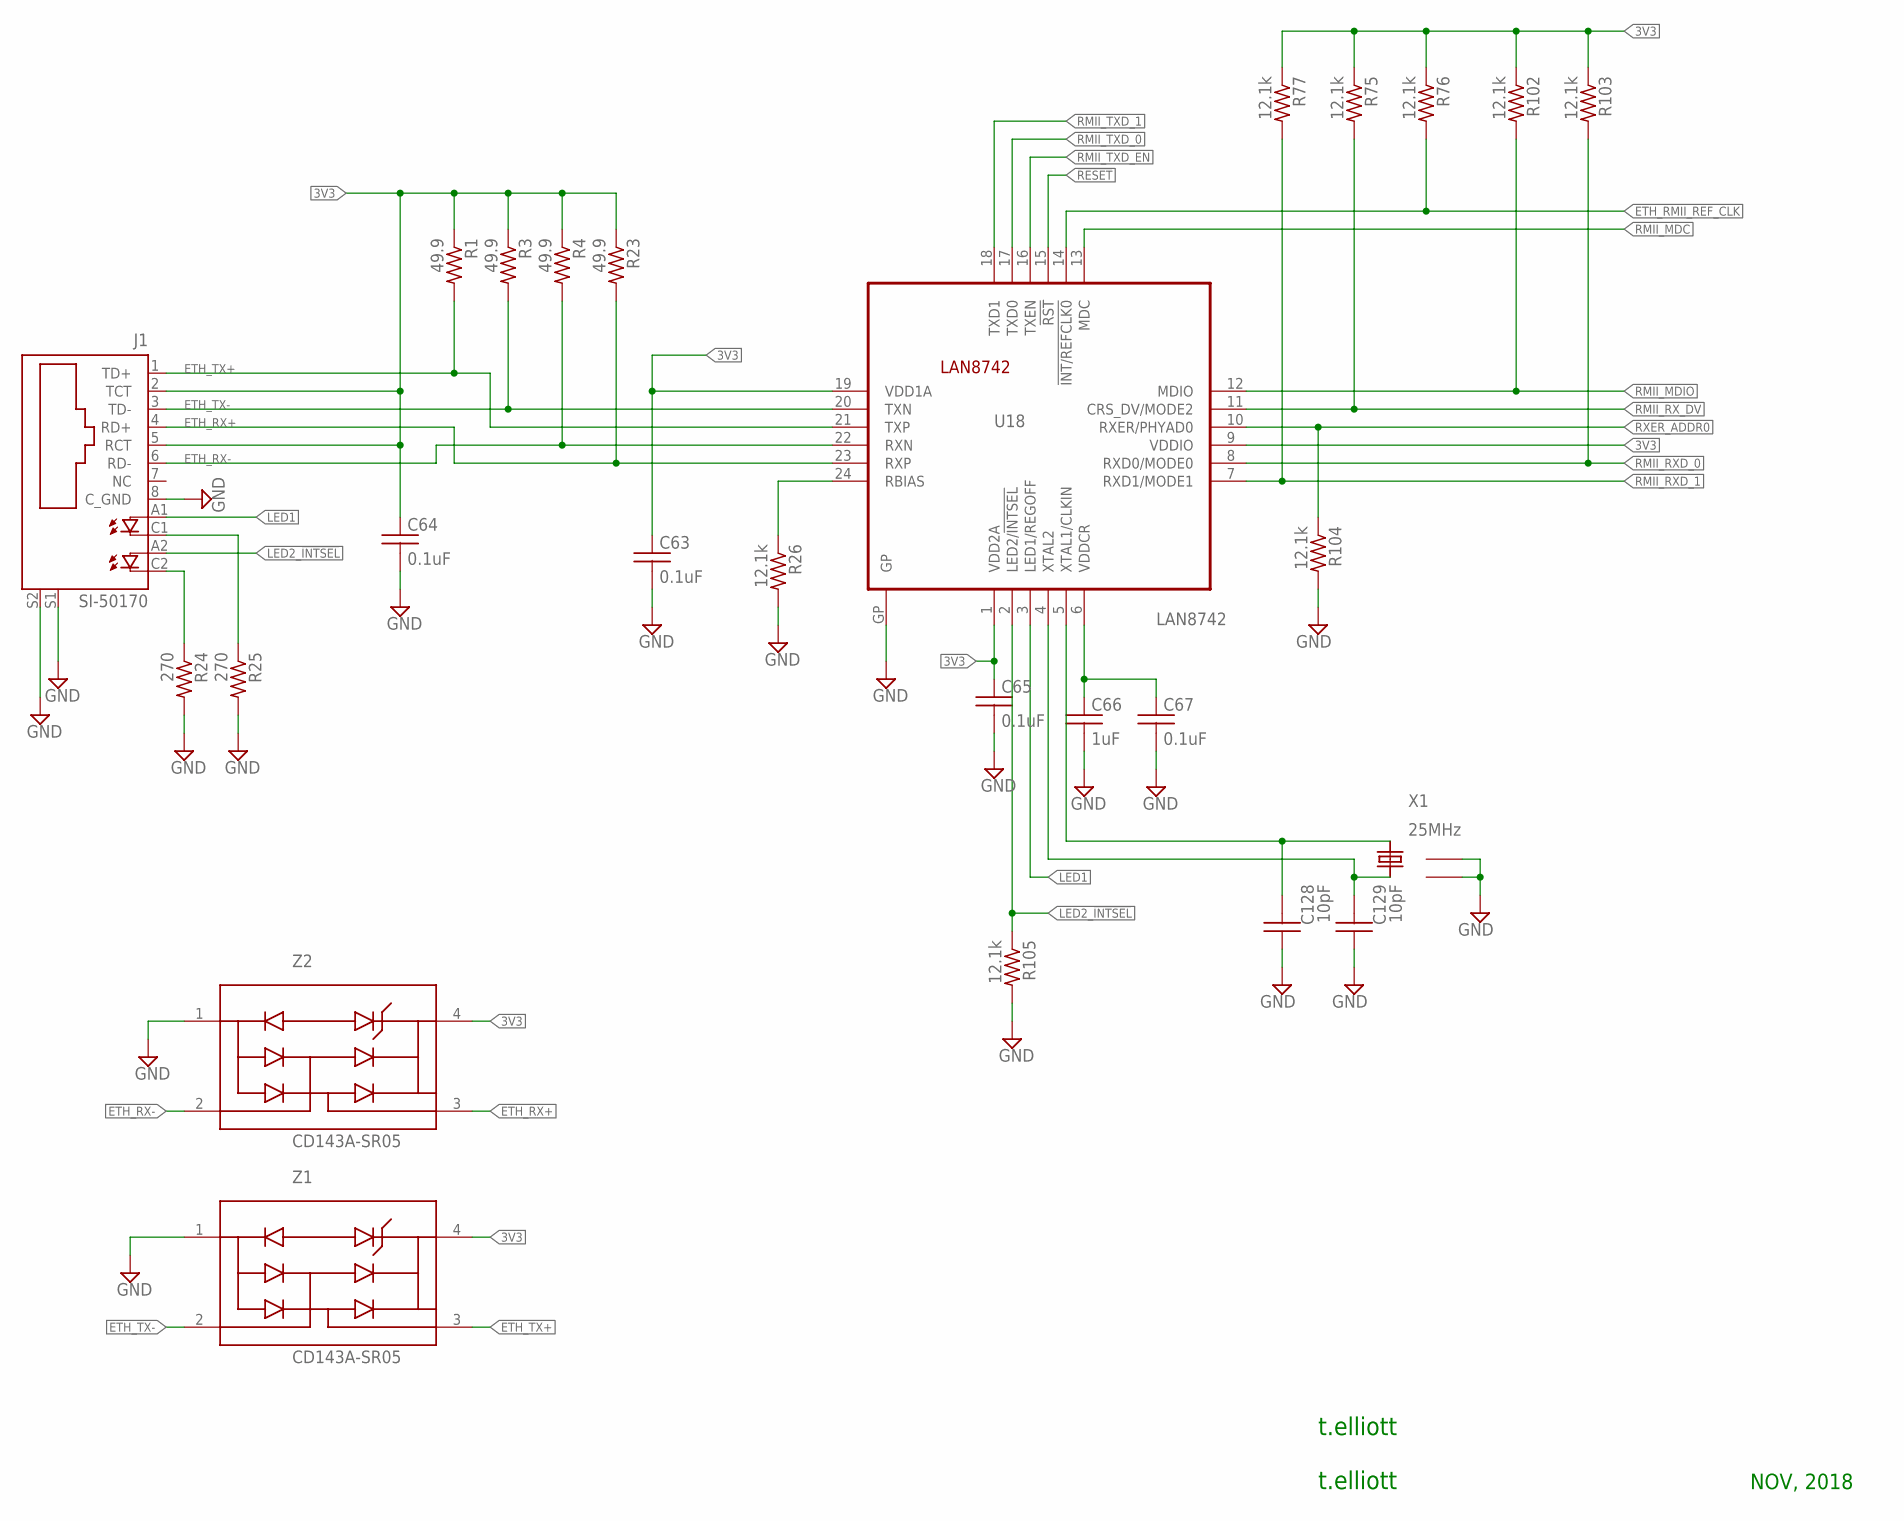
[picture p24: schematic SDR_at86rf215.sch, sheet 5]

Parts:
C63, C64, C65, C67: 0.1uF; C0603
C66: 1uF; C0603
C128, C129: 10pF; C0402
J1: SI-50170
R1, R3, R4, R23: 49.9; R0603
R24, R25: 270; R0603
R26, R75, R76, R77, R102, R103, R104, R105: 12.1k; R0603
U18: LAN8742; QFN-24
X1: 25MHz; ECS-250-20-30B-DU_CRYSTAL
Z1, Z2: CD143A-SR05; SR2.8.TCT_1PRIMARY

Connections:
3V3: C63.1, C64.1, C65.1, J1.2 (TCT), J1.5 (RCT), R1.1, R3.1, R4.1, R23.1, R75.1, R76.1, R77.1, R102.1, R103.1, U18.1 (VDD2A), U18.9 (VDDIO), U18.19 (VDD1A), Z1.4 (REF), Z2.4 (REF); also elsewhere on the board
!RESET: U18.15 (!RST); also elsewhere on the board
ETH_RMII_REF_CLK: R76.2, U18.14 (!INT/REFCLK0); also elsewhere on the board
ETH_RX+: J1.4 (RD+), R23.2, U18.23 (RXP), Z2.3 (I/O)
ETH_RX-: J1.6 (RD-), R4.2, U18.22 (RXN), Z2.2 (I/O)
ETH_TX+: J1.1 (TD+), R1.2, U18.21 (TXP), Z1.3 (I/O)
ETH_TX-: J1.3 (TD-), R3.2, U18.20 (TXN), Z1.2 (I/O)
GND: C63.2, C64.2, C65.2, C66.2, C67.2, C128.1, C129.1, J1.8 (C_GND), J1.S1, J1.S2, R24.2, R25.2, R26.2, R104.2, R105.2, U18.GP, X1.GND@1 (1), X1.GND@2 (2), Z1.1 (GND), Z2.1 (GND); also elsewhere on the board
LED1: J1.A1 (A), U18.3 (LED1/REGOFF)
LED2_!INTSEL: J1.A2 (A1), R105.1, U18.2 (LED2/!INTSEL)
unnamed: R26.1, U18.24 (RBIAS)
unnamed: C66.1, C67.1, U18.6 (VDDCR)
unnamed: J1.C2 (C1), R24.1
unnamed: J1.C1 (C), R25.1
unnamed: C129.2, U18.4 (XTAL2), X1.3
unnamed: C128.2, U18.5 (XTAL1/CLKIN), X1.1
RMII_MDC: U18.13 (MDC); also elsewhere on the board
RMII_MDIO: R102.2, U18.12 (MDIO); also elsewhere on the board
RMII_RXD_0: R103.2, U18.8 (RXD0/MODE0); also elsewhere on the board
RMII_RXD_1: R77.2, U18.7 (RXD1/MODE1); also elsewhere on the board
RMII_RX_DV: R75.2, U18.11 (CRS_DV/MODE2); also elsewhere on the board
RMII_TXD_0: U18.17 (TXD0); also elsewhere on the board
RMII_TXD_1: U18.18 (TXD1); also elsewhere on the board
RMII_TXD_EN: U18.16 (TXEN); also elsewhere on the board
RXER_ADDR0: R104.1, U18.10 (RXER/PHYAD0)

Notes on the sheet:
t.elliott
NOV, 2018

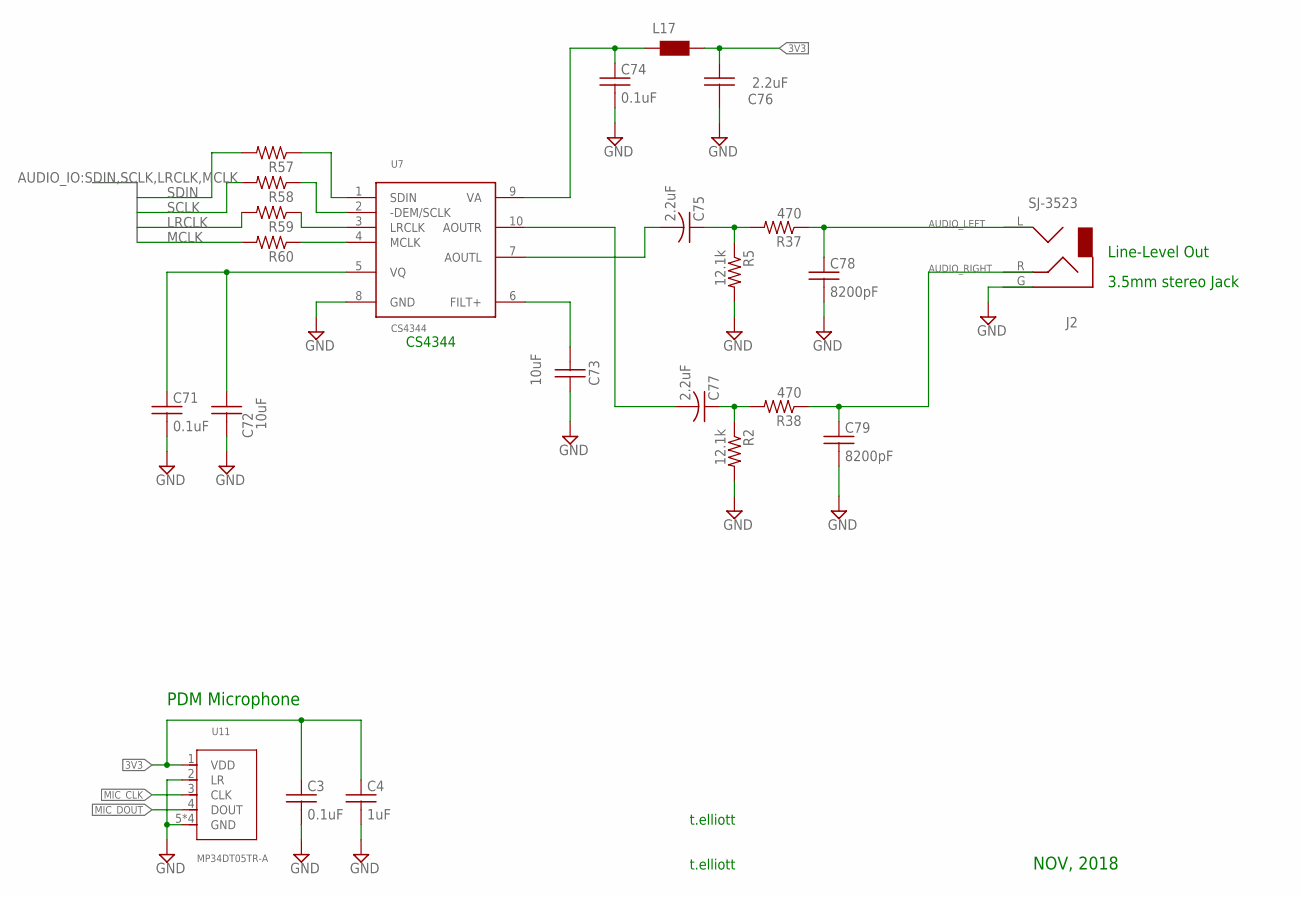
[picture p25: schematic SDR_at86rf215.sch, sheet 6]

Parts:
C3, C71, C74: 0.1uF; C0603
C4: 1uF; C0603
C72, C73: 10uF; C0805
C75, C76, C77: 2.2uF; C0805
C78, C79: 8200pF; C0603
J2: SJ-3523
L17: WE-CBF_0603; 0603
R2, R5: 12.1k; R0603
R37, R38, R57, R58, R59, R60: 470; R0402
U7: CS4344; MSOP10
U11: MP34DT05TR-A; HCLGA5P-3X4X1MM

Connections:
3V3: C3.1, C4.1, C76.1, L17.2, U11.1 (VDD); also elsewhere on the board
AUDIO_LEFT: C79.1, J2.R, R38.1
AUDIO_RIGHT: C78.1, J2.L, R37.1
GND: C3.2, C4.2, C71.2, C72.2, C73.1, C74.2, C76.2, C78.2, C79.2, J2.G, R2.2, R5.2, U7.8 (GND), U11.2 (LR), U11.5 (GND), U11.6 (GND), U11.7 (GND), U11.8 (GND); also elsewhere on the board
LRCLK: R59.2; also elsewhere on the board
MCLK: R60.2; also elsewhere on the board
MIC_CLK: U11.3 (CLK); also elsewhere on the board
MIC_DOUT: U11.4 (DOUT); also elsewhere on the board
unnamed: C77.2, U7.10 (AOUTR)
unnamed: R60.1, U7.4 (MCLK)
unnamed: R59.1, U7.3 (LRCLK)
unnamed: R58.1, U7.2 (-DEM/SCLK)
unnamed: R57.1, U7.1 (SDIN)
unnamed: C73.2, U7.6 (FILT+)
unnamed: C71.1, C72.1, U7.5 (VQ)
unnamed: C75.2, U7.7 (AOUTL)
unnamed: C75.1, R5.1, R37.2
unnamed: C77.1, R2.1, R38.2
unnamed: C74.1, L17.1, U7.9 (VA)
SCLK: R58.2; also elsewhere on the board
SDIN: R57.2; also elsewhere on the board

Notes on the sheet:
t.elliott
CS4344
Line-Level Out
3.5mm stereo Jack
PDM Microphone
NOV, 2018

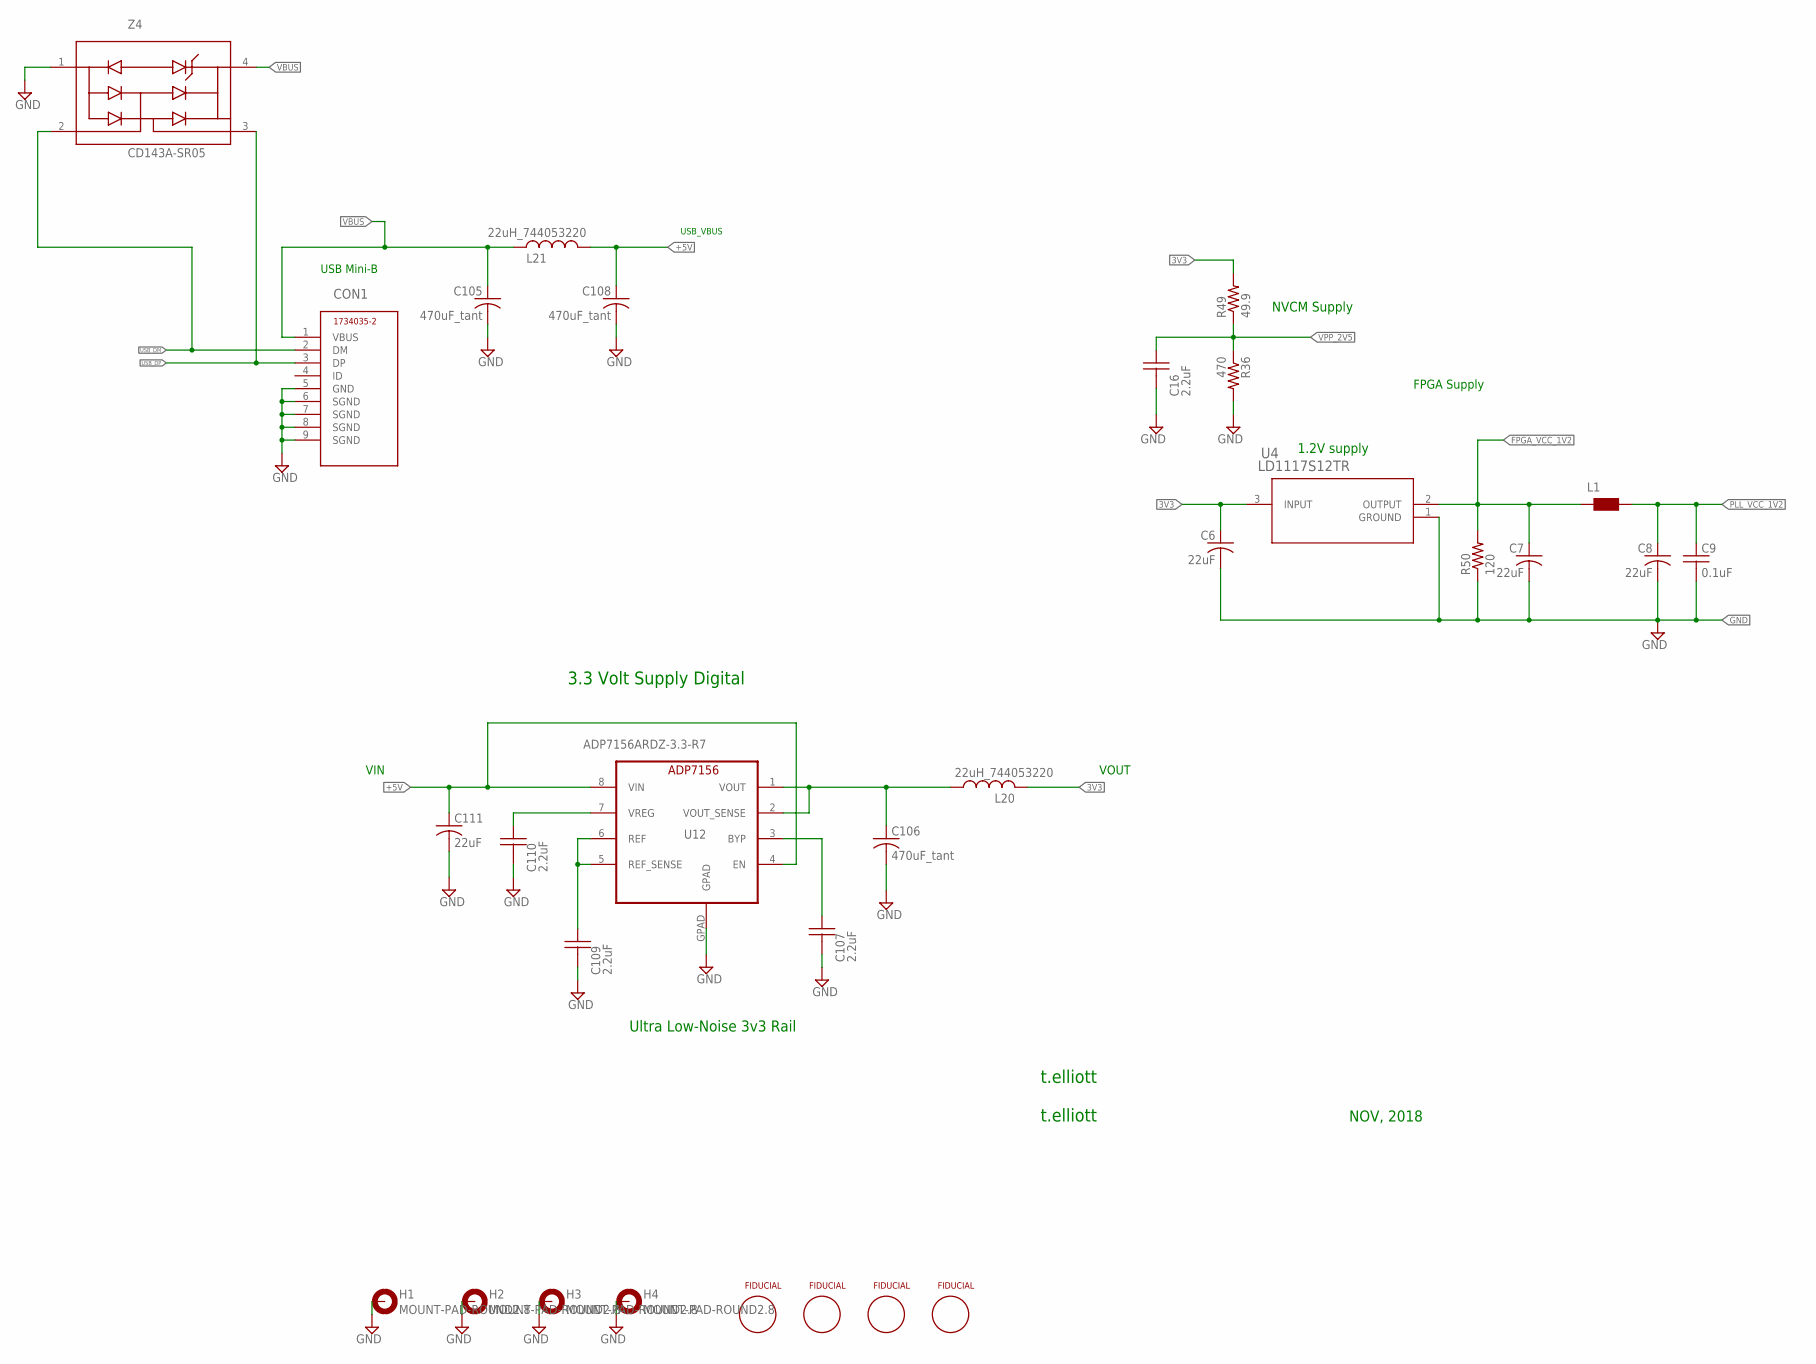
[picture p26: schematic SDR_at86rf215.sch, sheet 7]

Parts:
C6, C7, C8, C111: 22uF; 1210K
C9: 0.1uF; C0603
C16, C107, C109, C110: 2.2uF; C0805
C105, C106, C108: 470uF_tant; 1210K
CON1: 1734035-2
FID1, FID2, FID3, FID4: FIDUCIALSMD; FIDUCIAL
H1, H2, H3, H4: MOUNT-PAD-ROUND2.8; 2,8-PAD
L1: WE-CBF_0603; 0603
L20, L21: 22uH_744053220; POWER-CHOKE_WE-TPC
R36: 470; R0402
R49: 49.9; R0603
R50: 120; R0603
U4: LD1117S12TR; SOT-223
U12: ADP7156ARDZ-3.3-R7; SO8
Z4: CD143A-SR05; SR2.8.TCT_1PRIMARY

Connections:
3V3: C6.A, L20.2, R49.2, U4.3 (INPUT); also elsewhere on the board
+5V: C108.A, C111.A, L21.1, U12.4 (EN), U12.8 (VIN); also elsewhere on the board
FPGA_VCC_1V2: C7.A, L1.1, R50.2, U4.2 (OUTPUT); also elsewhere on the board
GND: C6.C, C7.C, C8.C, C9.2, C16.2, C105.C, C106.C, C107.2, C108.C, C109.2, C110.2, C111.C, CON1.5 (GND), CON1.6 (SGND), CON1.7 (SGND), CON1.8 (SGND), CON1.9 (SGND), H1.B2,8, H2.B2,8, H3.B2,8, H4.B2,8, R36.2, R50.1, U4.1 (GROUND), U12.GPAD, Z4.1 (GND); also elsewhere on the board
unnamed: C106.A, L20.1, U12.1 (VOUT), U12.2 (VOUT_SENSE)
unnamed: C109.1, U12.5 (REF_SENSE), U12.6 (REF)
unnamed: C110.1, U12.7 (VREG)
unnamed: C107.1, U12.3 (BYP)
PLL_VCC_1V2: C8.A, C9.1, L1.2; also elsewhere on the board
USB_DM: CON1.2 (DM), Z4.2 (I/O); also elsewhere on the board
USB_DP: CON1.3 (DP), Z4.3 (I/O); also elsewhere on the board
VBUS: C105.A, CON1.1 (VBUS), L21.2, Z4.4 (REF)
VPP_2V5: C16.1, R36.1, R49.1; also elsewhere on the board

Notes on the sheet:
t.elliott
VIN
VOUT
3.3 Volt Supply Digital
USB Mini-B
USB_VBUS
1.2V supply
NVCM Supply
Ultra Low-Noise 3v3 Rail
FPGA Supply
NOV, 2018

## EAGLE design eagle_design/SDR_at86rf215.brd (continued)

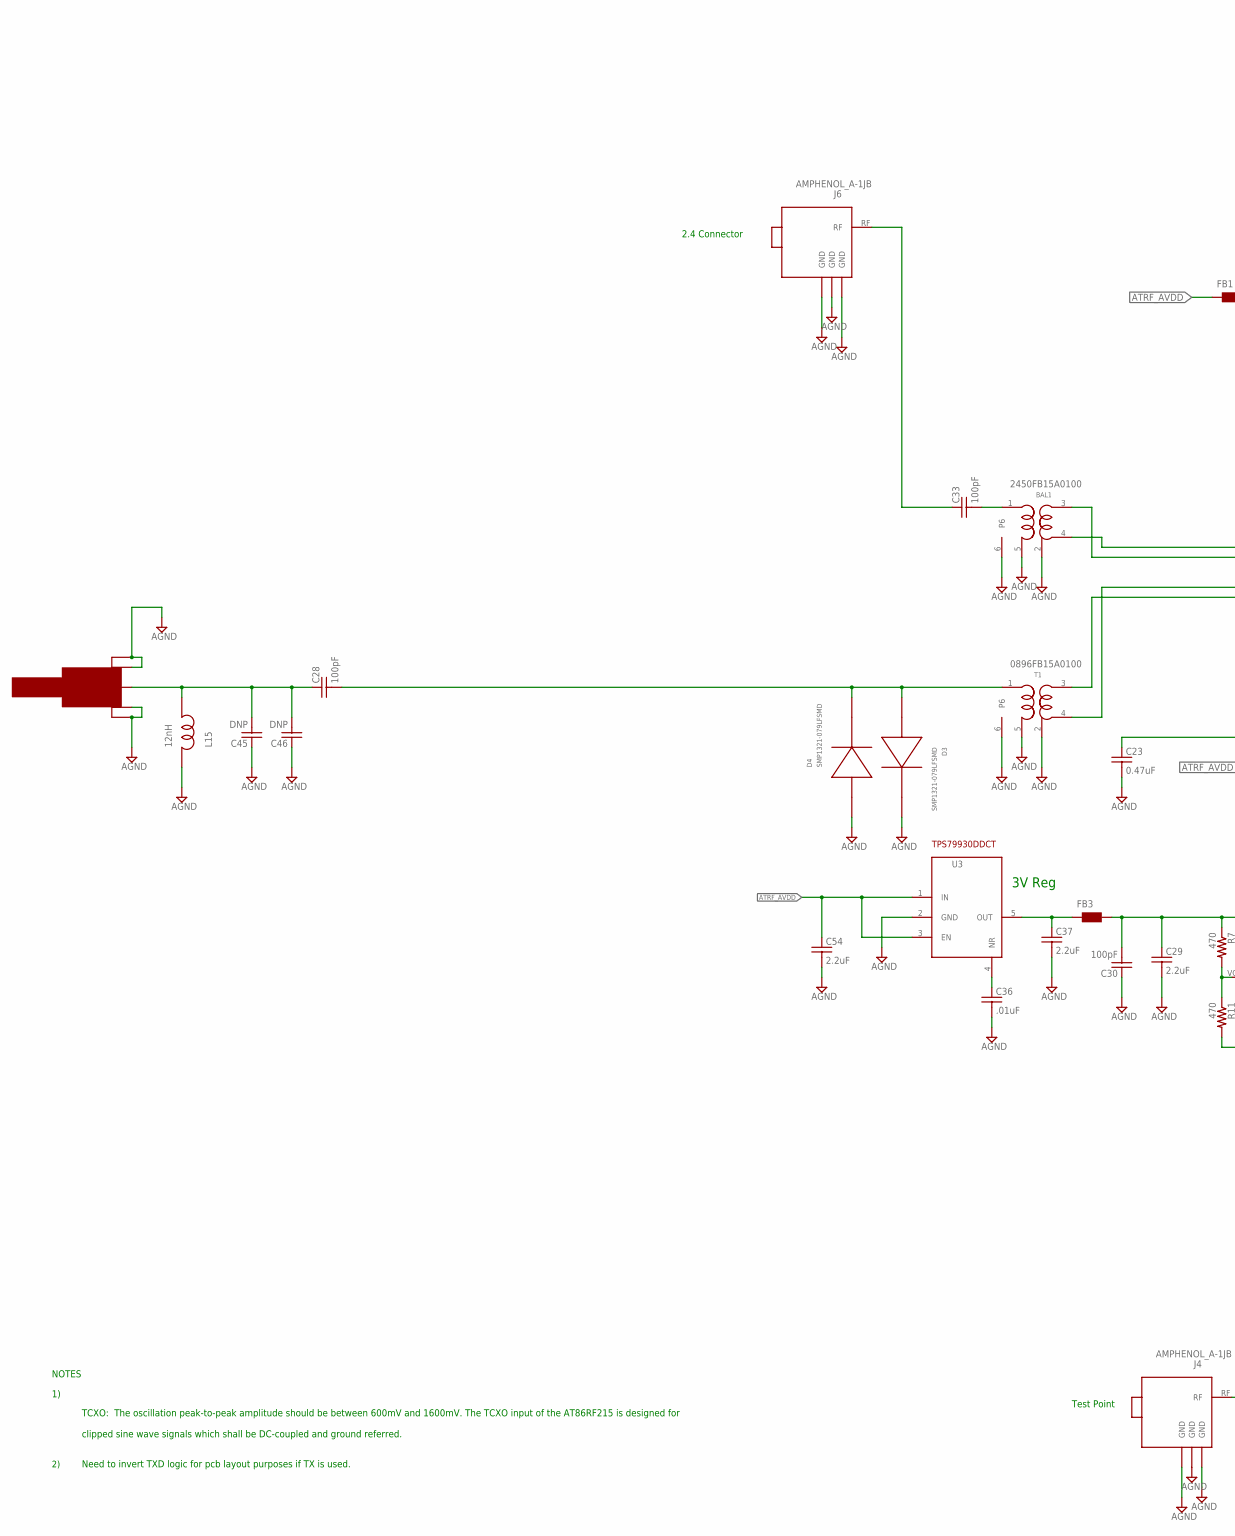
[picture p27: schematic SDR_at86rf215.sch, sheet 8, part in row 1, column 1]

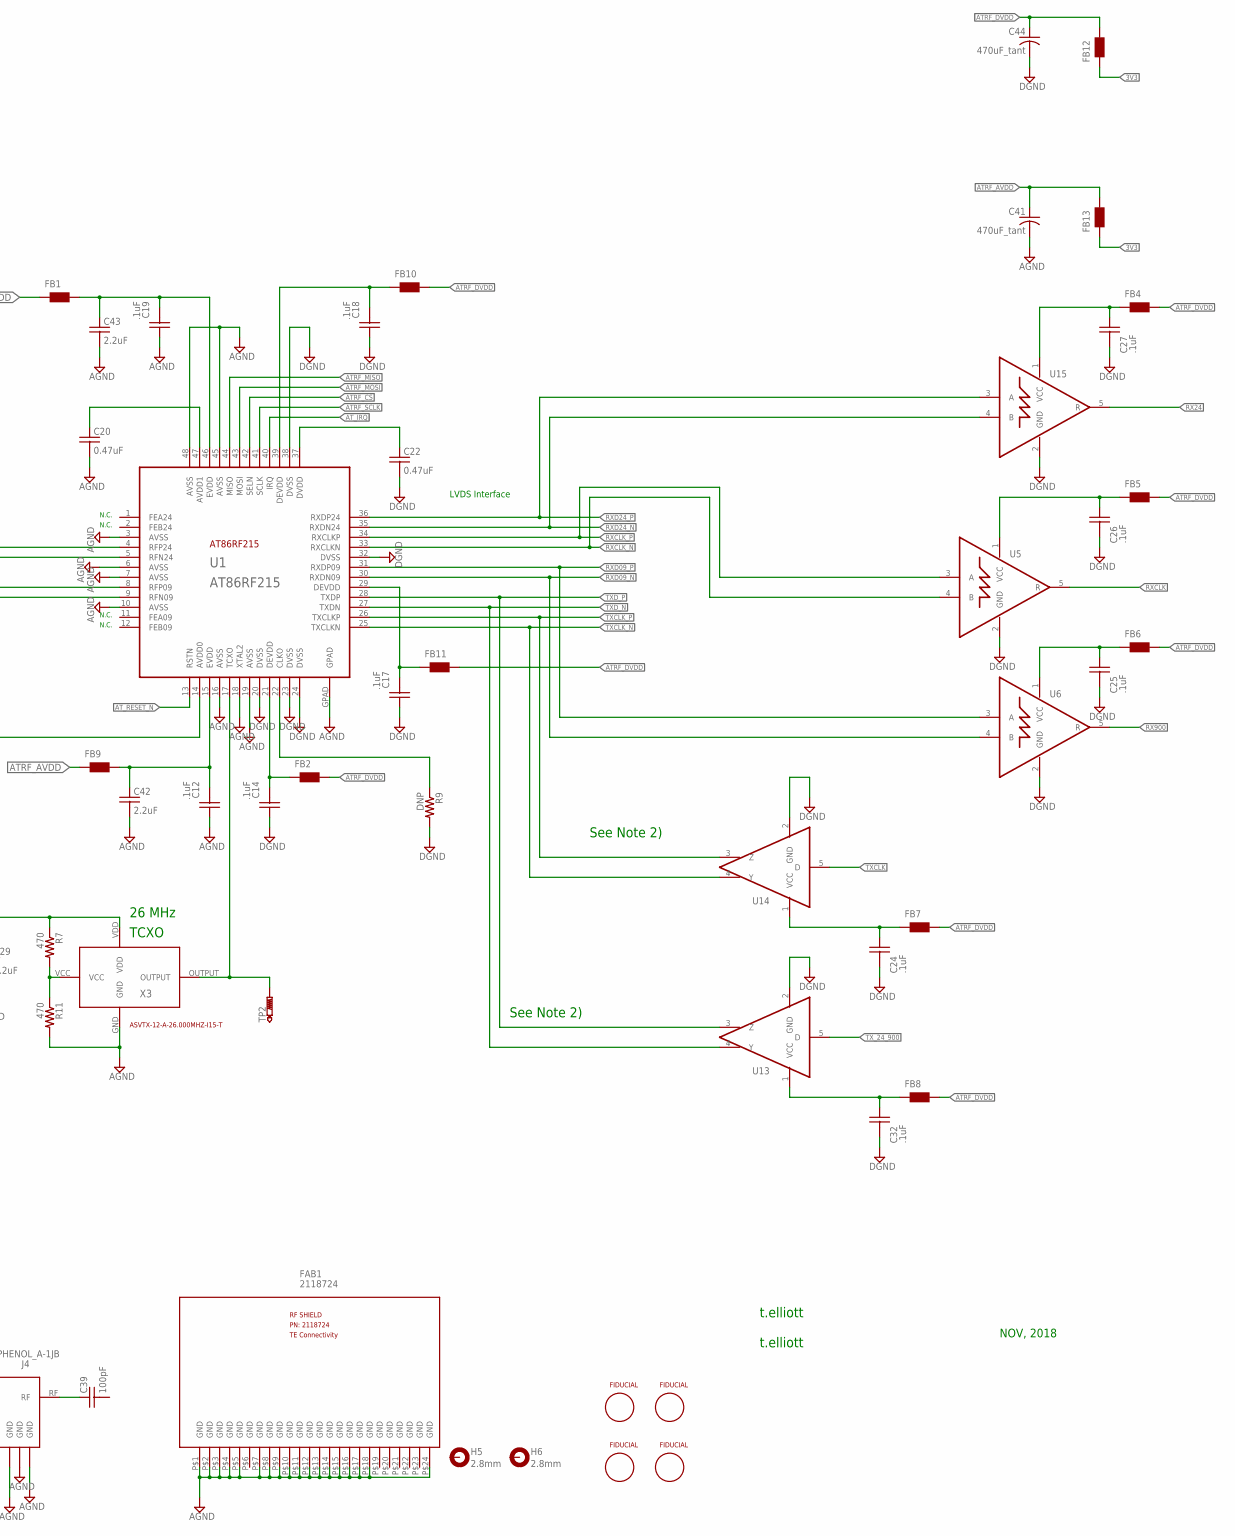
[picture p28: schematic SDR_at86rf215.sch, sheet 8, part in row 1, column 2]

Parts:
BAL1: 2450FB15A0100; BALUN
C12, C14, C17, C18, C19, C24, C25, C26, C27, C32: .1uF; C0402
C20, C22, C23: 0.47uF; C0603
C28, C30, C33, C39: 100pF; C0603
C29, C37, C42, C43, C54: 2.2uF; C0603
C36: .01uF; C0603
C41, C44: 470uF_tant; 1210K
C45, C46: DNP; C0603
D3, D4: SMP1321-079LFSMD; SC-79_PINDIODE
FAB1: 2118724; RF_SHIELD
FB1, FB2, FB3, FB4, FB5, FB6, FB7, FB8, FB9, FB10, FB11, FB12, FB13: WE-CBF_0603; 0603
FID5, FID6, FID7, FID8: FIDUCIALSMD; FIDUCIAL
H5, H6: 2.8mm; 2,8-PAD
J3: SMA0.062; SMA_EDGE
J4, J6: AMPHENOL_A-1JB; UFLCONNECTOR
L15: 12nH; C0603
R7, R11: 470; R0603_COMPACT
R9: DNP; R0603_COMPACT
T1: 0896FB15A0100; BALUN
TP2: PTR1TP08R; TP08R
U1: AT86RF215; QFN48
U3: TPS799X; SOT23-6
U5, U6, U15: SN65LVDT2; SOT23-5
U13, U14: SN65LVDS1; SOT23-5
X3: ASVTX-12-A-40.000MHZ-H10-T; CRYSTAL_2.5_2MM

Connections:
3V: C29.1, C30.2, FB3.2, R7.1, X3.VDD
3V3: FB12.1, FB13.1; also elsewhere on the board
ATRF_AVDD: C41.A, C54.1, FB1.1, FB9.1, FB13.2, U3.1 (IN), U3.3 (EN)
ATRF_CS: U1.42 (SELN); also elsewhere on the board
ATRF_DVDD: C44.A, FB2.2, FB4.2, FB5.2, FB6.2, FB7.2, FB8.2, FB10.2, FB11.2, FB12.2
ATRF_MISO: U1.44 (MISO); also elsewhere on the board
ATRF_MOSI: U1.43 (MOSI); also elsewhere on the board
ATRF_SCLK: U1.41 (SCLK); also elsewhere on the board
AT_IRQ: U1.40 (IRQ); also elsewhere on the board
AT_RESET_N: U1.13 (RSTN); also elsewhere on the board
GND: BAL1.2 (FEED), BAL1.5 (GND), BAL1.6, C12.1, C14.1, C17.1, C18.1, C19.1, C20.2, C22.2, C23.2, C24.2, C25.2, C26.2, C27.2, C29.2, C30.1, C32.2, C36.2, C37.2, C41.C, C42.2, C43.2, C44.C, C45.1, C46.1, C54.2, D3.C, D4.A, FAB1.P$1, FAB1.P$2, FAB1.P$3, FAB1.P$4, FAB1.P$5, FAB1.P$7, FAB1.P$8, FAB1.P$9, FAB1.P$10, FAB1.P$11, FAB1.P$12, FAB1.P$13, FAB1.P$14, FAB1.P$15, FAB1.P$16, FAB1.P$17, FAB1.P$18, FAB1.P$24, J3.GND1, J3.GND2 (GND3), J3.GND3 (GND2), J3.GND4, J4.1 (GND), J4.2 (GND), J4.3 (GND), J6.1 (GND), J6.2 (GND), J6.3 (GND), L15.2, R9.2, R11.2, T1.2 (FEED), T1.5 (GND), T1.6, U1.3 (AVSS), U1.6 (AVSS), U1.7 (AVSS), U1.10 (AVSS), U1.16 (AVSS), U1.18 (XTAL2), U1.19 (AVSS), U1.20 (DVSS), U1.23 (DVSS), U1.24 (DVSS), U1.32 (DVSS), U1.38 (DVSS), U1.45 (AVSS), U1.48 (AVSS), U1.GPAD, U3.2 (GND), U5.2 (GND), U6.2 (GND), U13.2 (GND), U14.2 (GND), U15.2 (GND), X3.GND; also elsewhere on the board
unnamed: C36.1, U3.4 (NR)
unnamed: TP2.TP, U1.17 (TCXO), X3.OUTPUT
unnamed: C26.1, FB5.1, U5.1 (VCC)
unnamed: C20.1, U1.47 (AVDD1)
unnamed: C22.1, U1.37 (DVDD)
unnamed: C28.1, C45.2, C46.2, J3.RF, L15.1
unnamed: R7.2, R11.1, X3.VCC
unnamed: C27.1, FB4.1, U15.1 (VCC)
unnamed: C23.1, U1.14 (AVDD0)
unnamed: C39.1, J4.RF
unnamed: C32.1, FB8.1, U13.1 (VCC)
unnamed: R9.1, U1.22 (CLKO)
unnamed: BAL1.1 (UBAL), C33.2
unnamed: C12.2, C42.1, FB9.2, U1.15 (EVDD)
unnamed: C33.1, J6.RF
unnamed: C24.1, FB7.1, U14.1 (VCC)
unnamed: C25.1, FB6.1, U6.1 (VCC)
unnamed: C19.2, C43.1, FB1.2, U1.46 (EVDD)
unnamed: C14.2, FB2.1, U1.21 (DEVDD)
unnamed: C18.2, FB10.1, U1.39 (DEVDD)
unnamed: C17.2, FB11.1, U1.29 (DEVDD)
unnamed: C28.2, D3.A, D4.C, T1.1 (UBAL)
unnamed: C37.1, FB3.1, U3.5 (OUT)
RF09_N: T1.3 (BP2), U1.9 (RFN09)
RF09_P: T1.4 (BP1), U1.8 (RFP09)
RF24_N: BAL1.3 (BP2), U1.5 (RFN24)
RF24_P: BAL1.4 (BP1), U1.4 (RFP24)
RX24: U15.5 (R); also elsewhere on the board
RX900: U6.5 (R); also elsewhere on the board
RXCLK: U5.5 (R); also elsewhere on the board
RXCLK_N: U1.33 (RXCLKN), U5.4 (B)
RXCLK_P: U1.34 (RXCLKP), U5.3 (A)
RXD09_N: U1.30 (RXDN09), U6.4 (B)
RXD09_P: U1.31 (RXDP09), U6.3 (A)
RXD24_N: U1.35 (RXDN24), U15.4 (B)
RXD24_P: U1.36 (RXDP24), U15.3 (A)
TXCLK: U14.5 (D); also elsewhere on the board
TXCLK_N: U1.25 (TXCLKN), U14.4 (Y)
TXCLK_P: U1.26 (TXCLKP), U14.3 (Z)
TXD_N: U1.27 (TXDN), U13.4 (Y)
TXD_P: U1.28 (TXDP), U13.3 (Z)
TX_24_900: U13.5 (D); also elsewhere on the board

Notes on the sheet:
t.elliott
TCXO: The oscillation peak-to-peak amplitude should be between 600mV and 1600mV. The TCXO input of the AT86RF215 is designed for clipped sine wave signals which shall be DC-coupled and ground referred.
NOTES
TCXO
26 MHz
3V Reg
ASVTX-12-A-26.000MHZ-I15-T
LVDS Interface
See Note 2)
Need to invert TXD logic for pcb layout purposes if TX is used.
2.4 Connector
Test Point
N.C.
NOV, 2018



Board: 4 copper layers, 167.6 x 78.7 mm, 212 parts (10 on the bottom side), 198 nets.

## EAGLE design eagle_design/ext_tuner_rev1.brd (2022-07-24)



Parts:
C1, C3, C11, C15, C16, C22, C64, C73, C75, C85: 330pF; C0603
C2, C10, C21, C62, C65, C72: 1000pF; C0603
C4, C12, C23, C53, C54, C74, C83, C84, C90, C91: 2.2uF; C0603
C5, C13, C18, C26, C27, C45, C46, C77: 2.2pF; C0603
C6, C7, C17, C20: 4.7pF; C0603
C8, C19, C24, C25: 1.0pF; C0603
C9, C29: DNP; C0603
C14, C80: 8.2pF; C0603
C28, C49: 0.5pF; C0603
C50, C60, C61, C71: 1uF; C0603
C70, C76: 0.1uF; C0402@1
D1, D3, D4, D5: SMP1321-079LFSMD; SC-79_PINDIODE
FAB1, FAB2, FAB3, FAB4, FAB5: 2118724; RF_SHIELD
FID1, FID2, FID3, FID4: FIDUCIALSMD; FIDUCIAL
FLT1: DFCB3914MLEJAA-RF1**DE-W0; SAWMURATA914
FLT2: B39921B3588U410; SM3030-6
H1, H2, H3, H4: 3.2mm; 2,8-PAD
J1, J2, J4: SMA0.062; SMA_EDGE
J3, J6: AMPHENOL_A-1JB; UFLCONNECTOR
L1, L7, L8: 47nH; L3225M; PARTNUMBER ELJ-PA331KF
L2, L30: 120nH; L3225M; PARTNUMBER ELJ-PA331KF
L3, L4, L5, L6: LQW18AN17NG8ZD 17nH; MURATA_LQW_0603
L9, L10, L26, L29: LQW18AN10NG10D 10nH; MURATA_LQW_0603
L14, L15, L20, L27: TCCH-80+
L16, L25, L28: CBC3225T4R7MR 4.7uH; L3225M; PARTNUMBER ELJ-PA331KF
L21, L22, L31: 620nH; L3225M; PARTNUMBER ELJ-PA331KF
L23, L24: LQW18AN15NJ10D 15nH; MURATA_LQW_0603
R2: 150; R1206
R5: 15; 0402$1
R9: zero_ohm; R0603
R10, R11: 287; R0603
R13, R14: 287; 0603
R16: 1.8; R1206
U1: PG-103+; SOT89
U2, U3: HMC636ST89ETR; SOT89
U4: 4245-52; PE4245
U6: PGA-103+; SOT89
U8: SYM-63LH+; SYM-18H
U11: 74ALS04D; SO14

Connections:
3V3: C70.1, C75.1, C76.1, U4.4 (VDD), U11.14 (VCC); also elsewhere on the board
+5V: C21.2, C22.2, C23.1, C54.1, C84.1, C91.1, L8.1, L16.1, L20.3 (DC), L25.1, L28.1; also elsewhere on the board
ANT_SW: R5.1, U11.1 (I), U11.5 (I); also elsewhere on the board
GND: C2.1, C3.1, C4.2, C5.2, C8.2, C10.1, C11.1, C12.2, C13.2, C14.2, C18.2, C19.2, C21.1, C22.1, C23.2, C24.2, C25.2, C28.2, C49.2, C53.2, C54.2, C64.2, C70.2, C72.1, C73.1, C74.2, C75.2, C76.2, C77.2, C80.2, C83.2, C84.2, C85.1, C90.2, C91.2, D1.C, D3.C, D4.A, D5.C, FAB1.P$1, FAB1.P$2, FAB1.P$3, FAB1.P$4, FAB1.P$5, FAB1.P$6, FAB1.P$7, FAB1.P$8, FAB1.P$9, FAB1.P$10, FAB1.P$11, FAB1.P$12, FAB1.P$13, FAB1.P$14, FAB1.P$15, FAB1.P$16, FAB1.P$17, FAB1.P$18, FAB1.P$19, FAB1.P$20, FAB1.P$21, FAB1.P$22, FAB1.P$23, FAB1.P$24, FAB2.P$1, FAB2.P$2, FAB2.P$3, FAB2.P$4, FAB2.P$5, FAB2.P$6, FAB2.P$7, FAB2.P$8, FAB2.P$9, FAB2.P$10, FAB2.P$11, FAB2.P$12, FAB2.P$13, FAB2.P$14, FAB2.P$15, FAB2.P$16, FAB2.P$17, FAB2.P$18, FAB2.P$19, FAB2.P$20, FAB2.P$21, FAB2.P$22, FAB2.P$23, FAB2.P$24, FAB3.P$1, FAB3.P$2, FAB3.P$3, FAB3.P$4, FAB3.P$5, FAB3.P$6, FAB3.P$7, FAB3.P$8, FAB3.P$9, FAB3.P$10, FAB3.P$11, FAB3.P$12, FAB3.P$13, FAB3.P$14, FAB3.P$15, FAB3.P$16, FAB3.P$17, FAB3.P$18, FAB3.P$19, FAB3.P$20, FAB3.P$21, FAB3.P$22, FAB3.P$23, FAB3.P$24, FAB4.P$1, FAB4.P$2, FAB4.P$3, FAB4.P$4, FAB4.P$5, FAB4.P$6, FAB4.P$7, FAB4.P$8, FAB4.P$9, FAB4.P$10, FAB4.P$11, FAB4.P$12, FAB4.P$13, FAB4.P$14, FAB4.P$15, FAB4.P$16, FAB4.P$17, FAB4.P$18, FAB4.P$19, FAB4.P$20, FAB4.P$21, FAB4.P$22, FAB4.P$23, FAB4.P$24, FAB5.P$1, FAB5.P$2, FAB5.P$3, FAB5.P$4, FAB5.P$5, FAB5.P$6, FAB5.P$7, FAB5.P$8, FAB5.P$9, FAB5.P$10, FAB5.P$11, FAB5.P$12, FAB5.P$13, FAB5.P$14, FAB5.P$15, FAB5.P$16, FAB5.P$17, FAB5.P$18, FAB5.P$19, FAB5.P$20, FAB5.P$21, FAB5.P$22, FAB5.P$23, FAB5.P$24, FLT1.GPAD, FLT2.1 (GND), FLT2.3 (GND), FLT2.4 (GND), FLT2.6 (GND), J1.GND1, J1.GND2 (GND3), J1.GND3 (GND2), J1.GND4, J2.GND1, J2.GND2 (GND3), J2.GND3 (GND2), J2.GND4, J3.1 (GND), J3.2 (GND), J3.3 (GND), J4.GND1, J4.GND2 (GND3), J4.GND3 (GND2), J4.GND4, J6.1 (GND), J6.2 (GND), J6.3 (GND), L2.2, L22.1, R10.1, R11.1, U1.2 (GND), U1.2@1 (GND), U2.2 (GND), U2.2@1 (GND), U3.2 (GND), U3.2@1 (GND), U4.2 (GND), U4.G2, U4.G3, U4.GP (GPAD), U6.2 (GND), U6.2@1 (GND), U8.4 (GND), U8.5 (GND), U8.6 (GND), U11.7 (GND), U11.9 (I), U11.11 (I), U11.13 (I); also elsewhere on the board
unnamed: C15.2, U3.1 (IN)
unnamed: C17.2, L1.2, L14.1 (RF), U1.3 (OUT)
unnamed: C1.2, FLT2.2 (RFIN)
unnamed: C62.1, U4.3 (RF1)
unnamed: C16.1, FLT1.2
unnamed: C6.1, U1.1 (IN)
unnamed: C9.1, J6.RF
unnamed: C7.1, D5.A, L5.1, L30.2
unnamed: C46.1, L26.1
unnamed: C5.1, C8.1, L5.2, L6.1
unnamed: C6.2, L6.2
unnamed: C1.1, U8.3 (IF)
unnamed: C60.1, C65.1, D3.A, D4.C
unnamed: C61.2, R9.1, R10.2
unnamed: C26.1, R9.2, R11.2
unnamed: C17.1, L3.1
unnamed: C27.2, L7.2, L15.1 (RF), U2.3 (OUT)
unnamed: C16.2, L8.2, L20.1 (RF), U3.3 (OUT)
unnamed: C20.1, U4.1 (RF2)
unnamed: C18.1, C19.1, L3.2, L4.1
unnamed: C20.2, L4.2
unnamed: C64.1, R5.2, U4.5 (CTRL)
unnamed: C15.1, FLT2.5 (RFOUT)
unnamed: FLT1.1, J2.RF
unnamed: C27.1, L9.1
unnamed: C25.1, C28.1, L9.2, L10.1
unnamed: C26.2, L10.2
unnamed: C50.2, C71.1, D1.A, L31.2
unnamed: C85.2, R2.1
unnamed: C29.1, J3.RF
unnamed: C53.1, L16.2, R16.2
unnamed: C72.2, C73.2, C74.1, C83.1, L27.3 (DC), L28.2
unnamed: C61.1, U8.2 (LO)
unnamed: C65.2, U4.6 (RFC)
unnamed: C13.1, L24.1, L27.1 (RF), U6.3 (OUT)
unnamed: L21.1, R2.2
unnamed: C80.1, L21.2, L23.2, U6.1 (IN)
unnamed: C71.2, J4.RF, L22.2
unnamed: C24.1, C49.1, L26.2, L29.1
unnamed: C14.1, C62.2, L24.2
unnamed: C60.2, U8.1 (RF)
unnamed: C45.2, L29.2
unnamed: C2.2, C3.2, C4.1, L1.1, L14.3 (DC), R16.1
unnamed: C45.1, U2.1 (IN)
unnamed: C50.1, C77.1, L23.1
unnamed: R13.1, U11.4 (O)
unnamed: R14.1, U11.2 (O)
unnamed: U11.3 (I), U11.6 (O)
unnamed: C10.2, C11.2, C12.1, C90.1, L7.1, L15.3 (DC), L25.2
SYNTH_OUT: C46.2; also elsewhere on the board
UHF_ACTIVE: L31.1, R14.2
UHF_IN: C7.2, J1.RF, L2.1
VHF_ACTIVE: L30.1, R13.2

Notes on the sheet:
t.elliott
914.5 - 6390 MHz LO (high-side injection)
DC - 5475 MHz Tuning. 914.5 MHz, 1 MHz BW IF
G=13dB
G=13dB
UHF PORT -> 400-1200 MHz Tuning Range, 914.5 MHz IF
If Pre-select/Harmonic filters are modified:
High-side LO
914.5 MHz IF
TEST POINT
1 MHz BW
70+dB Stop Band
For Pre-Select Filters As Shown In Design:
SAW 902-928 MHz 70+dB Stop Band Atten
Ceramic Resonator Block 914.5 MHz BPF, 45 dB Stop Band, 1 MHz BW, IL 5.3 dB
UHF RF Input
400-1160 MHz
IL 3dB, 26 MHz BW
HF/VHF RF Input
1-500 MHz
G=24dB
NF=0.5dB
HF/VHF/UHF Tuner, 914.5 MHz IF, 1 MHz BW
Dual Antenna
HF/VHF PORT -> 1-500 MHz Tuning Range, 914.5 MHz IF
Alternate IF: Change FLT2 to B39431B3730H110 , 433.92 MHz, 140 KHz BW (same footprint) Bypass FLT1 Change LO and pre-select filters May require different synth depending on min tuning freq (same series)
Potential MODS
NOTES
All amps are SOT-89 for easy replacement of amplifier with different characteristics.
OIP3=37dBm
ANT_SW HIGH=HF/VHF
ANT_SW LOW=UHF
TR SWITCH TABLE


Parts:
BAL1: HHM17147A1; TDK_BALUN_5PIN
C30, C33, C35, C92: 1uF; C0603
C31: 1.5nF; C0402@1
C32: 2.2nF; C0402@1
C34, C51, C93, C94: 330pF; C0603
C36, C55, C56, C59: 2.2uF; C0603
C37, C38, C39, C42: 1uF; C0402@1
C40, C41, C44: 0.012uF; C0402@1
C43, C47, C48: 0.1uF; C0402@1
C52: 56nF; C0402@1
C95, C96: 18pF; C0402@1
JP1: PINHD-1X10; 1X10
L11, L12: LQW18AN68NJ00D 68nH; MURATA_LQW_0603
L13: LQW32FT100M0HL 10uH; L3225M; PARTNUMBER ELJ-PA331KF
L17, L19: CBC3225T4R7MR 4.7uH; L3225M; PARTNUMBER ELJ-PA331KF
R17, R18: 71.5; R0402
R19, R24, R25, R26, R27, R28, R29: 22; R0603_COMPACT
R20: 5.9; R0603
R21, R22: 866; R0603
R23: 15; R0402
U5: LTC6948IUFD-4#PBF; QFN28_NONSQ
X1: CWX813-100.0M_ALT_TB522-100.0M; CWX8XX_5MM_7MM

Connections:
3V3: C30.1, C43.1, C44.1, C47.1, C59.1, C92.1, C93.1, C94.1, JP1.2, L11.2, L12.2, L19.1, U5.8 (VD+), U5.13 (VRF+), U5.27 (VREF+); also elsewhere on the board
!MUTE: JP1.9, R28.1; also elsewhere on the board
+5V: C40.1, C41.1, C42.1, C56.1, L17.1, R23.2, U5.23 (VVCO+); also elsewhere on the board
+5V_VIN: C55.1, JP1.1, L17.2; also elsewhere on the board
ANT_SW: R29.1; also elsewhere on the board
BALUN_N: BAL1.4 (BP1), C96.2
BALUN_P: BAL1.3 (BP2), C95.2
GND: BAL1.2 (FEED), BAL1.5 (GND), C30.2, C31.2, C32.2, C34.1, C35.2, C36.2, C37.2, C38.2, C39.2, C40.2, C41.2, C42.2, C43.2, C44.2, C47.2, C48.2, C52.2, C55.2, C56.2, C59.2, C92.2, C93.2, C94.2, JP1.3, R21.1, R22.1, U5.10 (GND), U5.17 (GND), U5.21 (GND), U5.24 (GND), U5.GPAD, X1.2 (GND); also elsewhere on the board
unnamed: R19.2, U5.2 (STAT)
unnamed: C52.1, R18.1
unnamed: C32.1, L13.2, R18.2, U5.15 (TUNE)
unnamed: L13.1, R17.2
unnamed: R24.2, U5.3 (!CS)
unnamed: R25.2, U5.4 (SCLK)
unnamed: R26.2, U5.5 (SDI)
unnamed: R27.2, U5.6 (SDO)
unnamed: C36.1, U5.16 (TB), U5.18 (CMC), U5.19 (CMB), U5.20 (CMA)
unnamed: R20.2, R22.2, X1.3 (OUTPUT)
unnamed: C33.1, U5.1 (REF+)
unnamed: C33.2, R20.1, R21.2
unnamed: C37.1, U5.28 (REF-)
unnamed: C38.1, U5.22 (BVCO)
unnamed: C39.1, U5.14 (BB)
unnamed: R23.1, U5.25 (VCP+)
unnamed: C48.1, U5.7 (LDO)
unnamed: R28.2, U5.9 (!MUTE)
unnamed: C31.1, R17.1, U5.26 (CP)
unnamed: BAL1.1 (UBAL), C51.2
unnamed: JP1.10, R29.2
unnamed: C34.2, C35.1, L19.2, X1.4 (VCC)
SYNTH_CS: JP1.5, R24.1; also elsewhere on the board
SYNTH_N: C96.1, L11.1, U5.11 (RF-)
SYNTH_OUT: C51.1; also elsewhere on the board
SYNTH_P: C95.1, L12.1, U5.12 (RF+)
SYNTH_SCLK: JP1.6, R25.1; also elsewhere on the board
SYNTH_SDI: JP1.7, R26.1; also elsewhere on the board
SYNTH_SDO: JP1.8, R27.1; also elsewhere on the board
SYNTH_STAT: JP1.4, R19.1; also elsewhere on the board

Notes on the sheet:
t.elliott
673-2700 MHz
700 - 6390 MHz
N.C.
+/- 1ppm option: TB522-100.0M
Dual Antenna
HF/VHF/UHF Tuner, 914.5 MHz IF, 1 MHz BW

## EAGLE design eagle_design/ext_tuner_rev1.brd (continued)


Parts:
C57, C58: 2.2uF; C0603
C63, C68, C69: 1uF; C0402@1
C66, C67: 18pF; C0402@1
C78, C79, C81, C82, C86, C88: 0.1uF; C0402@1
C87, C89: GRM32EC70J107ME15L 100uF; 1210K
FB14: SMB2.5R-2; SMB2.5-2
J5: 1734035-2
JP2: PINHD-1X6; 1X06
JP3: PINHD-1X2; 1X02
JP4: PINHD-2X5; 2X05
L18: CBC3225T4R7MR 4.7uH; L3225M; PARTNUMBER ELJ-PA331KF
R1, R4, R6, R7, R8, R12, R15: 22; R0603_COMPACT
R3: 866; R0603
R37: 866; 0603
R38, R39, R40, R41, R42, R43: 15; 0402$1
U7: STM32_STM32F40X_LQFP64RGT6; STM32_LQFP64
U9: MCP1826ST-3302E/DB; SOT223
X2: 8MHz; ECS_CRYSTAL_ECS-250-20-30B-DU_CRYSTAL

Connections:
3V3: C58.1, C78.1, C79.1, C81.1, C82.1, C86.1, C88.1, JP3.1, JP4.2, L18.1, R37.2, U7.1 (VBAT), U7.13 (VDDA), U7.19 (VDD), U7.32 (VDD), U7.48 (VDD), U7.64 (VDD); also elsewhere on the board
3V3_VIN: C57.1, C87.A, L18.2, U9.3 (OUT)
!MUTE: R15.2; also elsewhere on the board
+5V_VIN: C89.A, FB14.P$1, U9.1 (IN); also elsewhere on the board
ANT_SW: R12.2; also elsewhere on the board
BOOT0: JP3.2, R3.1, U7.60 (BOOT0)
FS_DM: J5.2 (DM), R43.2
FS_DP: J5.3 (DP), R42.2
GIO0: JP4.10, U7.40 (PC9)
GIO1: JP4.9, U7.39 (PC8)
GIO2: JP4.8, U7.38 (PC7)
GIO3: JP4.7, U7.37 (PC6)
GIO4: JP4.6, U7.36 (PB15-SPI2_MOSI)
GIO5: JP4.5, U7.35 (PB14-SPI2_MISO)
GIO6: JP4.4, U7.34 (PB13-SPI2_SCK)
GIO7: JP4.3, U7.33 (PB12-SPI2_NSS)
GND: C57.2, C58.2, C63.2, C66.2, C67.2, C68.2, C69.2, C78.2, C79.2, C81.2, C82.2, C86.2, C87.C, C88.2, C89.C, J5.5 (GND), J5.6 (SGND), J5.7 (SGND), J5.8 (SGND), J5.9 (SGND), JP2.3, JP4.1, R3.2, U7.12 (VSSA), U7.18 (VSS), U7.63 (VSS), U9.2 (GND), U9.4 (GND), X2.GND@1 (GND), X2.GND@2 (GND); also elsewhere on the board
unnamed: R6.1, U7.21 (PA5-SPI1_SCK)
unnamed: R8.1, U7.22 (PA6-SPI1_MISO)
unnamed: R7.1, U7.23 (PA7-SPI1_MOSI)
unnamed: R4.1, U7.20 (PA4-SPI1_NSS)
unnamed: C67.1, U7.6 (PH1), X2.1
unnamed: C66.1, U7.5 (PH0), X2.3
unnamed: R42.1, U7.45 (PA12-FS_DP)
unnamed: R43.1, U7.44 (PA11-FS_DM)
unnamed: C69.1, U7.47 (VCAP_2)
unnamed: C68.1, U7.31 (VCAP_1)
unnamed: JP2.6, R38.2
unnamed: JP2.5, R39.2
unnamed: JP2.4, R40.2
unnamed: JP2.2, R41.2
unnamed: R1.1, U7.16 (PA2)
unnamed: R12.1, U7.17 (PA3)
unnamed: R15.1, U7.41 (PA8)
NRST: C63.1, R37.1, R39.1, U7.7 (NRST)
SWCLK: R41.1, U7.49 (PA14-SWCLK-JTCK)
SWDIO: R40.1, U7.46 (PA13-SWDIO-JTMS)
SWO: R38.1, U7.55 (PB3-TRACESWO-JTDO)
SYNTH_CS: R4.2; also elsewhere on the board
SYNTH_SCLK: R6.2; also elsewhere on the board
SYNTH_SDI: R7.2; also elsewhere on the board
SYNTH_SDO: R8.2; also elsewhere on the board
SYNTH_STAT: R1.2; also elsewhere on the board
VIN_5V: FB14.P$2, J5.1 (VBUS)

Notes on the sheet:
SWD
USB Mini-B
t.elliott
Dual Antenna
DFU Program Enable
HF/VHF/UHF Tuner, 914.5 MHz IF, 1 MHz BW


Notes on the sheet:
Change mounting holes back to 2.8mm
Reduce gpad size on synth by 0.15mm in both dimensions
fix gpad on RF Switch to match documentation
done
not done
fix paste mask for synth and resonator filter. Thermals for ground planes
fix TCXO pads
add keepout under 3225 inductors
fix BOM for 0.1uF 0402 parts, some refs must be wrong
fix land pattern for 18GHz SMA connectors, std gound pads too wide
add pull-down to ANT_SW
change R19, R24, R25, R26, R27, R29 to 22 ohms
Replace TCXO with CWX813 ?, Try AST3TQ-T-40.000MHZ-28
add LED for lock status
Change R9 to zero ohm
Make C28, C49 DNP
isolate grounds on 3x3mm saw filter
add 2pF more total to UHF filter shunt cap before LNA, and 4pF more after LNA.
add attenuator before LNAs instead of IF?
change U1 to PGA-103+


Board: 4 copper layers, 150.2 x 76.7 mm, 206 parts (0 on the bottom side), 124 nets.

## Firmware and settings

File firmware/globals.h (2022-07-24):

//MIT License
//
//Copyright (c) 2018 tvelliott
//
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


#ifndef __GLOBALS_H_H__
#define __GLOBALS_H_H__

#include "stm32h7xx_hal.h"
#include <stdint.h>
#include "lwip.h"

//#define INVERT_EXT_TUNER 1

#define DEFAULT_P25_NETWORK 0x000 //change this if you don't allow all
#define DEFAULT_P25_RADIO_MANF 0x0000 //change this if you don't allow all
#define CONFIG_ADDRESS 0x000000
#define CONFIG_SIZE (4*1024)

#ifndef M_PI
#define M_PI (3.14159265358979323846)
#endif

#ifndef M_SQRT1_2
#define M_SQRT1_2  0.70710678118654752440  /* 1/sqrt(2) */
#endif

#ifndef M_E
#define M_E    2.7182818284590452354 /* e */
#endif

#define TUNER_CMD_SET_FREQ 0x01
#define TUNER_CMD_GET_FREQ 0x02
#define TUNER_CMD_SET_IF 0x03
#define TUNER_CMD_GET_IF 0x04
#define TUNER_CMD_SET_ANT 0x05
#define TUNER_CMD_GET_ANT 0x06
#define TUNER_CMD_PLL_STATUS 0x07
#define TUNER_CMD_SET_MUTE 0x08
#define TUNER_CMD_GET_LOW_FREQ 0x09
#define TUNER_CMD_GET_HIGH_FREQ 0x0a
#define TUNER_CMD_GET_LOW_IF 0x0b
#define TUNER_CMD_GET_HIGH_IF 0x0c


void init_globals( void );
int read_configuration_from_flash( void );
void write_configuration_to_flash( void );

extern int do_test_mem;
extern int do_test_flash;
extern int do_write_config;
extern int do_read_config;
extern int do_system_reset;
extern int do_iq_mode;
extern int do_rf_tx_test;
extern int do_at_dump;
extern int do_at_scan;
extern int do_at_scan_cont;

typedef struct {
  int audio_on;
  float audio_volume_f;
  int sa_mode;
  int squelch;
  int scanner_mode;
  int srate;
  int rcut;
  int bw;
  int rfgain;
  float i_off;
  float q_off;
  int p25_logging;
  int p25_radiomanf_id;
  int p25_radiomanf_id_allow_all;
  int p25_network_id;
  int p25_network_id_allow_all;
  int uart3_baudrate;
  union {
    char ip_addr[4];
    uint32_t ip_addr32;
  };
} config_t1;

typedef struct {
  union {
    config_t1 *config;
    config_t1 configt1;
    char config_zero[CONFIG_SIZE - 4];
  };
  uint32_t crc32;
} config_t;


extern config_t1 *config;
extern void main_tick( void );
extern void DelayClk3( unsigned long );
extern void delay_ms( int delay );
extern void delay_us( int delay );
extern SPI_HandleTypeDef hspi3;
extern volatile struct udp_pcb *udp_data_pcb;
extern volatile struct ip4_addr udp_saddr;
extern volatile int8_t do_handle_exti1;
extern volatile uint16_t iq_data[512];
extern void process_incoming_rf();
extern volatile int out_s;
extern volatile int out_cnt;
extern volatile int out_e;
extern volatile int is_playing;
void audio_int_config( void );
void rf900_int_config( void );
float get_current_freq( void );
float get_real_amp( void );
void reset_channel_timeout( void );
void set_channel_timeout_min( void );
volatile uint32_t uptime_sec;
void udp_send_response_demod( uint8_t *buffer, int len );
volatile int do_low_if_mix;
volatile int do_freq_offset;
volatile int do_48khz_iq_only;
#endif

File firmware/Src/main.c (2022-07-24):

//MIT License
//
//Copyright (c) 2018 tvelliott
//
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



/* Includes ------------------------------------------------------------------*/
#include <complex.h>
#include <math.h>

#include "globals.h"
#include "main.h"
#include "stm32h7xx_hal.h"
#include "lwip.h"
#include "mbelib_test_main.h"

#define ARM_MATH_CM7 1
#include "arm_common_tables.h"
#include "arm_math.h"

#include "symsync_config.h"
#include "firdes_arm32.h"
#include "symsync_rf_arm32.h"
#include "freqdem_cfrf_arm32.h"
#include "resamp_cf_arm32.h"
#include "resamp_rf_arm32.h"
#include "window_functions_arm32.h"

#include "math_arm32.h"
#include "msb_index_arm32.h"
#include "firpfb_cf_arm32.h"
#include "window_cf_arm32.h"
#include "dotprod_cf_arm32.h"
#include "resamp_cf_arm32.h"
#include "resamp2_cf_arm32.h"
#include "rkaiser_arm32.h"
#include "window_functions_arm32.h"
#include "firdes_arm32.h"
#include "resamp_config.h"
#include "symsync_config.h"
#include "firfilt_rf_arm32.h"
#include "firfilt_cf_arm32.h"
#include "nco_cf_arm32.h"
#include "freqmod_arm32.h"
#include "eqlms_rf_arm32.h"
#include "wdelay_rf_arm32.h"


#include "p25_decode.h"
#include "p25_stats.h"
#include "channel_filter.h"

#include "telnet.h"

#include "lwip/udp.h"

#include "flash_s08.h"
#include "fpga.h"
#include "at86rf215.h"

#include "main.h"

/* USER CODE BEGIN Includes */
//#include "liquid.h"

/* USER CODE END Includes */
// create resampler
void eval_fir( float *data_in, float *data_out, int len, float *zbuffer, float *coef );

#define FLT_LEN 33

float ii_off;
float qq_off;

float zbuffer_i[97];
float zbuffer_q[97];
float data_in_i[256];
float data_out_i[256];
float data_in_q[256];
float data_out_q[256];

//remove dc level
float ALPHA_D_i;
float d_alpha_i;
float d_beta_i;
float d_avg_i;

float ALPHA_D_q;
float d_alpha_q;
float d_beta_q;
float d_avg_q;



static int current_rssi = -127;

//filter len=97
float sinc_filter[] = {
  0.140496194363, 0.281820982695, -0.090696640313, -0.046851862222, -0.164575159550, -0.134356126189, -0.031023621559, 0.179854497313, 0.375539124012, 0.026221035048
  , -0.028105402365, -0.326236367226, -0.382247179747, -0.202509149909, 0.184361815453, 0.638917803764, 0.576637566090, 0.638917803764, 0.184361815453, -0.202509149909
  , -0.382247179747, -0.326236367226, -0.028105402365, 0.026221035048, 0.375539124012, 0.179854497313, -0.031023621559, -0.134356126189, -0.164575159550, -0.046851862222
  , -0.090696640313, 0.281820982695, 0.140496194363
};

static struct pbuf *p;
volatile struct ip4_addr udp_saddr;
volatile static char udp_send_addr[4] = {0xc0, 0xa8, 0x01, 0x03};

volatile int agc_locked;

#define N_SAMPLES 256

float audio_out_level = 10000.0f;

volatile int do_freq_offset = 1;

volatile int do_48khz_iq_only = 0; //1==do RF IQ resamp from 100khz to 48khz only and send that over udp

volatile int do_low_if_mix = 0; //1==do the entire dsp chain and send 48khz audio over udp with low-if 12.5khz offset
//(much better receiver performance with low-if offset)
//0==do the entire dsp chain and send 48khz audio over udp,  DONT do low-if 12.5khz offset

float32_t stddev_in[N_SAMPLES];
float32_t stddev_out;
int stddev_n;

volatile int channel_timeout;
volatile int scanner_channel = 2;
volatile uint32_t scanner_idle_time;
volatile int8_t std_dev;
//1 (1)   001 (1)   Simulcast 854.4125  854.5125  856.9375  856.9625  857.9375  857.9625  858.9375a   858.9625a

volatile int scanner_freqs = 4;
volatile int scanner_channel_mask[] = { 1, 1, 1, 1 }; //skip last channel (too weak)
//volatile float scanner_freq_p25[] = { 856.9375, 856.9625, 857.9375, 857.9625 };
volatile float scanner_freq_p25[] = { 954.5 + 1.025, 954.5 + 1, 954.5 + 0.025, 954.5 };
volatile int scanner_gain[] = {8, 12, 8, 12}; //8=good to -58dBm,  12=good to -64dBm
volatile int scanner_thresh[] = {-74, -83, -74, -83 };

volatile int did_print_channel;
static volatile float real_amp = 0.0f;

UART_HandleTypeDef huart3;
ADC_HandleTypeDef hadc1;
ADC_HandleTypeDef hadc3;
SD_HandleTypeDef hsd2;
SPI_HandleTypeDef hspi3;

void p25_net_tick( void );
void process_incoming_samples( int16_t val );
void udp_send_data( uint8_t *buffer, int len );
void p25_udp_init( void );
void udp_data_rx( void *arg, struct udp_pcb *pcb, struct pbuf *p, struct ip4_addr *addr, uint16_t port );
int _mem_free( void );
void led_tick( void );
void main_tick( void );

uint32_t second_tick;
volatile uint32_t uptime_sec;
int sample_cnt;
int found_signal;

#define IN_BUFFER_N 16

char in_buffer[1500 * IN_BUFFER_N];
char in_buffer_tmp[1500 * IN_BUFFER_N];
int in_buffer_len;

volatile int scanner_mod;

/* USER CODE BEGIN PV */
int64_t __errno;

static int set_mco2 = 0;
static float complex fm_in[8];
static float fm_out[1024];

volatile static int avg_i;
volatile static int avg_q;
volatile static int avg_iq_cnt;

volatile struct udp_pcb *udp_data_pcb;
int audio_frames_done;
int do_silent_frame;

int eqlms_trained = 0;

volatile int fm_cnt;

/* USER CODE END PV */

void SystemClock_Config( void );
static void MX_GPIO_Init( void );
static void MX_USART3_UART_Init( void );

static void MX_ADC1_Init( void );
static void MX_ADC3_Init( void );
static void MX_SDMMC2_SD_Init( void );
void MX_SPI3_Init( void );



/* USER CODE BEGIN PFP */
static void MPU_Config( void );
void tcp_iperf_init( void );
static volatile uint32_t current_time;
static uint32_t led_time;
static uint8_t led_state;
static uint32_t clk_mhz;

// initialize frame generator properties
//flexframegenprops_s fgprops;

/* USER CODE END PFP */

unsigned int did_sym = 0;

// options
int          symsync_ftype = LIQUID_FIRFILT_RRC; // filter type
unsigned int symsync_k           =   10;     // filter samples/symbol  48Ksps/4.8k symbols/sec
unsigned int symsync_m           =   2;     // number of bits/symbol  4-FSK
float        symsync_beta        = 0.365f;    //filter excess bandwidth factor (best somewhere between 0.36 to 0.37)
unsigned int symsync_npfb        = SYMSYNC_NFILTERS;  //number of polyphase filters in bank

float symsync_buf_in[1];
float symsync_buf_out[1];


struct symsync_s symsync;
struct symsync_s *q;

static uint32_t telnet_tick_time;

#define SAMPLE_FREQ (100.0e3*2.0)     //input RF sample rate
#define RF_CHANNEL_BW  12500.0f   //bw fed into FM demodulator (FM deviation)
#define POST_FM_FLT_BW  12500.0f  //bw after FM demodulator  (audio)
#define DECODER_FS  (47937.00f/1.0)     //final re-sampled rate of audio

int decimate;

//I/Q from transceiver will be 400 Ksps,  FPGA decimated to 100 Ksps
//down-sample incoming 100 Ksps I/Q from RF channel to desired rate of 48Ksps
//float ch_resamp_r           = 2.0f*(DECODER_FS/SAMPLE_FREQ); // resampling rate (output/input)
float ch_resamp_r           = 3.84 / 2.0; // resampling rate (output/input)

unsigned int ch_resamp_m    = RESAMP_CF_M;     // resampling filter semi-length (filter delay)
float ch_resamp_As          = -60.0f;  // resampling filter stop-band attenuation [dB]
//float ch_resamp_bw          = (RF_CHANNEL_BW/SAMPLE_FREQ);  // resampling filter bandwidth
//float ch_resamp_bw          = (RF_CHANNEL_BW/SAMPLE_FREQ)/2.0f;  // resampling filter bandwidth
float ch_resamp_bw          = 0.55;  // resampling filter bandwidth
unsigned int ch_resamp_npfb = RESAMP_CF_NFILTERS;     // number of filters in bank (timing resolution)
static float complex samples[256];

static struct resamp_cf_s ch_rs;
struct resamp_cf_s *ch_resamp_q;

unsigned int half_band_m = 7;
float half_band_as = -60.0f;
float complex half_band_x;
float complex half_band_2x[2];

static struct resamp2_s halfband_s;
struct resamp2_s *halfband_q;

float complex hb_samples1[256];
float complex hb_samples2[256];


// channel resamp arrays
//float complex ch_resamp_x[8];
float complex ch_resamp_y[512]; //48 is enough for 16.28/100.0
unsigned int ch_ny = 0;


//up-sample voice audio from 8 Ksps  to 16.276 Ksps
float audio_resamp_r           = 2.0345f;   //resampling rate==2.0345 (output/input) to give desired
//float audio_resamp_r           = 6.0f;   //resampling rate==2.0345 (output/input) to give desired
unsigned int audio_resamp_m    = RESAMP_RF_M;     // resampling filter semi-length (filter delay)
float audio_resamp_As          = -60.0f;  // resampling filter stop-band attenuation [dB]
float audio_resamp_bw          = 0.36f;  // resampling filter bandwidth ,  bw of 0.45 takes edge off
unsigned int audio_resamp_npfb = RESAMP_RF_NFILTERS;     // number of filters in bank (timing resolution)

static struct resamp_rf_s audio_rs;
struct resamp_rf_s *audio_resamp_q;
// audio resamp arrays
static float audio_resamp_x[160];
static float audio_resamp_y[160 * 6];
volatile short upsampled[160 * 6];
volatile int upsample_ready;


//post FM demod audio filter before being sent to decoder
static struct firfilt_rf_s audio_fir_s;
static struct firfilt_rf_s *audio_fir;
static float audio_fir_bw = ( POST_FM_FLT_BW / DECODER_FS );
static float audio_fir_as = -60.0f;
static int audio_fir_len = 4.0;
static float fm_filtered;

//RF channel fir
//static struct firfilt_cf_s channel_fir_s;
//static struct firfilt_cf_s *channel_fir;
//static float channel_fir_bw = (RF_CHANNEL_BW*2)/SAMPLE_FREQ;
//static float channel_fir_as = -80.0f;
//static int channel_fir_len = 160;
//static float complex channel_output;

struct nco_cf_s *nco;
struct freqmod_s *freqmod;

struct eqlms_rf_s *eqlms;
// options
unsigned int eqlms_k = 10;         // filter samples/symbol
unsigned int eqlms_m = 3;         // filter semi-length (symbols)
float eqlms_beta = 0.3f;          // filter excess bandwidth factor
float eqlms_mu = 0.200f;          // LMS equalizer learning rate
float eqlms_d[1];
float eqlms_dhat[1];

////////////////////////////////////////////////////////////////////////////////////////////////////////
////////////////////////////////////////////////////////////////////////////////////////////////////////
float get_real_amp( void )
{
  return real_amp;
}

////////////////////////////////////////////////////////////////////////////////////////////////////////
////////////////////////////////////////////////////////////////////////////////////////////////////////
float atan2f( float y, float x )
{
  //http://pubs.opengroup.org/onlinepubs/009695399/functions/atan2.html
  //Volkan SALMA

  const float ONEQTR_PI = M_PI / 4.0;
  const float THRQTR_PI = 3.0 * M_PI / 4.0;
  float r, angle;
  float abs_y = fabs( y ) + 1e-10f;    // kludge to prevent 0/0 condition
  if( x < 0.0f ) {
    r = ( x + abs_y ) / ( abs_y - x );
    angle = THRQTR_PI;
  } else {
    r = ( x - abs_y ) / ( x + abs_y );
    angle = ONEQTR_PI;
  }
  angle += ( 0.1963f * r * r - 0.9817f ) * r;
  if( y < 0.0f )
    return( -angle );     // negate if in quad III or IV
  else
    return( angle );


}


/**
  * @brief  The application entry point.
  *
  * @retval None
  */
int main( void )
{
  /* Reset of all peripherals, Initializes the Flash interface and the Systick. */
  HAL_Init();

  HAL_Delay( 1000 );

  MPU_Config();

  SCB_EnableICache();
  //SCB_DisableICache();

  /* USER CODE END 1 */

  /* Enable D-Cache-------------------------------------------------------------*/
  SCB_EnableDCache();
  //SCB_DisableDCache();

  /* MCU Configuration----------------------------------------------------------*/


  /* Initialize all configured peripherals */
  //MX_GPIO_Init();
  /* Initialize all configured peripherals */
  //MX_ADC1_Init();
  //MX_ADC3_Init();
  //MX_SDMMC2_SD_Init();


  /* Configure the system clock */
  SystemClock_Config();
  /* USER CODE BEGIN 1 */

  //HAL_Delay(10);
  //MX_SPI3_Init();  //must be after fpga bit-bang init
  init_globals(); //this needs to be done before uart configuration  (baud rate) and networking configuration, etc


  MX_USART3_UART_Init();
  //

  MX_LWIP_Init();

  /* USER CODE BEGIN 2 */
  // create frame generator with default properties

  printf( "\r\n\r\nInstruction Cache Enabled" );
  printf( "\r\nData Cache Enabled" );
  printf( "\r\nHAL Initialized" );

  if( set_mco2 ) printf( "\r\nconfigure MCO2 for 200 MHz" );

  clk_mhz = SystemCoreClock / 1e6;
  printf( "\r\nSTM32H743 Running @ %lu MHz", clk_mhz );


  tcp_iperf_init();
  printf( "\r\niperf3 server started on port 5201" );


  mbelib_test_init();

  //demodulate
  freqdem_init( 0.15f );

  //modulate
  //freqmod = freqmod_create( 0.15f );

  int ii;

  p25_udp_init();
  telnet_init();
  rtl_tcp_driver_init();


  q = symsync_create_rnyquist( &symsync, symsync_ftype, symsync_k, symsync_m, symsync_beta, symsync_npfb );
  ch_resamp_q = resamp_cf_create( &ch_rs, ch_resamp_r, ch_resamp_m, ch_resamp_bw, ch_resamp_As, ch_resamp_npfb );
  audio_resamp_q = resamp_rf_create( &audio_rs, audio_resamp_r, audio_resamp_m, audio_resamp_bw, audio_resamp_As, audio_resamp_npfb );
  audio_fir = firfilt_rf_create_kaiser( &audio_fir_s, audio_fir_len, audio_fir_bw, audio_fir_as, 0.0f );

  //channel_fir = firfilt_cf_create_kaiser( &channel_fir_s, channel_fir_len, channel_fir_bw, channel_fir_as, 0.0f );
  nco = nco_create( LIQUID_NCO );
  nco_set_frequency( nco, 0.25f * M_PI );

  halfband_q = resamp2_create( &halfband_s, half_band_m, 0.0f, half_band_as );

  //eqlms = eqlms_rf_create_rnyquist( LIQUID_FIRFILT_RRC, eqlms_k, eqlms_m, eqlms_beta, 0 );
  //eqlms_rf_set_bw( eqlms, eqlms_mu );

  int16_t *sptr;
  int ii_len;

  int free = _mem_free();
  printf( "\r\nheap mem free %d bytes\r\n", free );


  MX_SPI3_Init();  //must be after fpga bit-bang init
  init_flash_s08();

  init_dc_correction();




  ////////////////////////////////////////////////////////////////////////////////////////////////////////////////////////
  //  main loop
  ////////////////////////////////////////////////////////////////////////////////////////////////////////////////////////
  while( 1 ) {

    MX_LWIP_Process();
    //HAL_GPIO_WritePin( GPIOE, (GPIO_PIN_2 | GPIO_PIN_3 | GPIO_PIN_4), GPIO_PIN_RESET );

    if( in_buffer_len > 0 && in_buffer_len % 2 == 0 ) {


      if( in_buffer_len > 0 ) {
        if( config->scanner_mode == 1 && stddev_n < N_SAMPLES - 1 ) calc_stddev( ( int16_t * ) in_buffer, in_buffer_len );
      }

      ii_len = in_buffer_len;
      in_buffer_len -= ii_len;
      memcpy( in_buffer_tmp, in_buffer, ii_len );

      sptr = ( int16_t * ) &in_buffer_tmp[0];

      for( ii = 0; ii < ii_len / 2; ii++ ) {
        if( found_signal ) process_incoming_samples( ( int16_t ) *sptr++ );
        MX_LWIP_Process();
        led_tick();
      }

    }
    main_tick();
    command_tick();

    current_rssi = ( int ) get_rssi();

  }

}
/*
//////////////////////////////////////////////////////////////////////////////////////////////////////
//////////////////////////////////////////////////////////////////////////////////////////////////////
void test_resamp(void) {
    // options
    float r_r           = 1.1f;   // resampling rate (output/input)
    unsigned int r_m    = 13;     // resampling filter semi-length (filter delay)
    float r_As          = 60.0f;  // resampling filter stop-band attenuation [dB]
    float r_bw          = 0.45f;  // resampling filter bandwidth
    unsigned int r_npfb = 32;     // number of filters in bank (timing resolution)
    unsigned int r_n    = 400;    // number of input samples
    float r_fc          = 0.044f; // complex sinusoid frequency

    static struct resamp_cf_s rs;
    static struct resamp_cf_s *resamp_q;

    // arrays
    float complex r_x[413+1];
    float complex r_y[504+1];


    unsigned int i;

    // number of input samples (zero-padded)
    unsigned int nx = r_n + r_m;

    // output buffer with extra padding for good measure
    unsigned int y_len = (unsigned int) ceilf(1.1 * nx * r_r) + 4;

    printf("\r\nnx: %d", nx);
    printf("\r\nylen: %d", y_len);

    resamp_q = resamp_cf_create(&rs, r_r,r_m,r_bw,r_As,r_npfb);


    // generate input signal
    float wsum = 0.0f;
    for (i=0; i<nx; i++) {
        // compute window
        float w = i < r_n ? kaiser(i, r_n, 10.0f, 0.0f) : 0.0f;

        // apply window to complex sinusoid
        r_x[i] = cexpf(_Complex_I*2*M_PI*r_fc*i) * w;

        // accumulate window
        wsum += w;

    }


    // resample
    unsigned int ny=0;
    resamp_cf_execute_block(resamp_q, r_x, nx, r_y, &ny);


    for (i=0; i<ny; i++) {
      printf("\r\n%f, %f", creal(r_y[i]), cimag(r_y[i]) );
      MX_LWIP_Process();
    }
}
*/

/////////////////////////////////////////////////////////////////////////////////////////////////////////
/////////////////////////////////////////////////////////////////////////////////////////////////////////
void main_tick()
{

  current_time = HAL_GetTick();
  if( ( current_time - telnet_tick_time ) > 50 ) {
    telnet_tick();
    telnet_tick_time = current_time;
  }

  current_time = HAL_GetTick();
  if( current_time - second_tick > 1000 ) {
    second_tick = current_time;
    uptime_sec++;
    //printf("\r\nsamples %d", sample_cnt);
    sample_cnt = 0;

    //show_button_reg();
  }

  MX_LWIP_Process();

}

/////////////////////////////////////////////////////////////////////////////////////////////////////////
/////////////////////////////////////////////////////////////////////////////////////////////////////////
void led_tick()
{

  current_time = HAL_GetTick();

  if( ( current_time - led_time ) > 1 ) {


    p25_net_tick();

    audio_frames_done = 0;
    led_time = current_time;

    if( do_silent_frame++ > 3 ) {
      do_silent_frame = 0;
      //flush_audio();
    }


    //blink the on-board red/blue leds every 10ms so we know the code is running
    led_state ^= 1;
    if( led_state ) {
      //HAL_GPIO_WritePin( GPIOE, (GPIO_PIN_2 | GPIO_PIN_3 | GPIO_PIN_4), GPIO_PIN_SET );
    } else {
      //HAL_GPIO_WritePin( GPIOE, (GPIO_PIN_2 | GPIO_PIN_3 | GPIO_PIN_4), GPIO_PIN_RESET );
    }

    led_time = current_time;

  }
}

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
/* USER CODE BEGIN 4 */
/**
  * @brief  Configure the MPU attributes
  * @param  None
  * @retval None
  */
static void MPU_Config( void )
{
  MPU_Region_InitTypeDef MPU_InitStruct;

  /* Disable the MPU */
  HAL_MPU_Disable();

  /* Configure the MPU attributes as Device not cacheable
     for ETH DMA descriptors */
  MPU_InitStruct.Enable = MPU_REGION_ENABLE;
  MPU_InitStruct.BaseAddress = 0x30040000;
  MPU_InitStruct.Size = MPU_REGION_SIZE_256B;
  MPU_InitStruct.AccessPermission = MPU_REGION_FULL_ACCESS;
  MPU_InitStruct.IsBufferable = MPU_ACCESS_BUFFERABLE;
  MPU_InitStruct.IsCacheable = MPU_ACCESS_NOT_CACHEABLE;
  MPU_InitStruct.IsShareable = MPU_ACCESS_NOT_SHAREABLE;
  MPU_InitStruct.Number = MPU_REGION_NUMBER0;
  MPU_InitStruct.TypeExtField = MPU_TEX_LEVEL0;
  MPU_InitStruct.SubRegionDisable = 0x00;
  MPU_InitStruct.DisableExec = MPU_INSTRUCTION_ACCESS_ENABLE;

  HAL_MPU_ConfigRegion( &MPU_InitStruct );

  /* Configure the MPU attributes as Cacheable write through
     for LwIP RAM heap which contains the Tx buffers */
  MPU_InitStruct.Enable = MPU_REGION_ENABLE;
  MPU_InitStruct.BaseAddress = 0x30044000; //also defined in lwipopts.h as #define LWIP_RAM_HEAP_POINTER    (0x30044000)
  MPU_InitStruct.Size = MPU_REGION_SIZE_16KB;
  MPU_InitStruct.AccessPermission = MPU_REGION_FULL_ACCESS;
  MPU_InitStruct.IsBufferable = MPU_ACCESS_NOT_BUFFERABLE;
  MPU_InitStruct.IsCacheable = MPU_ACCESS_CACHEABLE;
  MPU_InitStruct.IsShareable = MPU_ACCESS_NOT_SHAREABLE;
  MPU_InitStruct.Number = MPU_REGION_NUMBER1;
  MPU_InitStruct.TypeExtField = MPU_TEX_LEVEL0;
  MPU_InitStruct.SubRegionDisable = 0x00;
  MPU_InitStruct.DisableExec = MPU_INSTRUCTION_ACCESS_ENABLE;

  HAL_MPU_ConfigRegion( &MPU_InitStruct );


  //FMC / FPGA address space,  16-bit
  MPU_InitStruct.Enable = MPU_REGION_ENABLE;
  MPU_InitStruct.BaseAddress = 0x60000000;
  MPU_InitStruct.Size = MPU_REGION_SIZE_64MB;
  MPU_InitStruct.AccessPermission = MPU_REGION_FULL_ACCESS;
  MPU_InitStruct.IsBufferable = MPU_ACCESS_NOT_BUFFERABLE;
  MPU_InitStruct.IsCacheable = MPU_ACCESS_NOT_CACHEABLE;
  MPU_InitStruct.IsShareable = MPU_ACCESS_NOT_SHAREABLE;
  MPU_InitStruct.Number = MPU_REGION_NUMBER2;
  MPU_InitStruct.TypeExtField = MPU_TEX_LEVEL0;
  MPU_InitStruct.SubRegionDisable = 0x00;
  MPU_InitStruct.DisableExec = MPU_INSTRUCTION_ACCESS_DISABLE;

  HAL_MPU_ConfigRegion( &MPU_InitStruct );

  /* Enable the MPU */
  HAL_MPU_Enable( MPU_PRIVILEGED_DEFAULT );
}
/* ADC1 init function */
static void MX_ADC1_Init( void )
{

  ADC_MultiModeTypeDef multimode;
  ADC_ChannelConfTypeDef sConfig;

  /**Common config
  */
  hadc1.Instance = ADC1;
  hadc1.Init.ClockPrescaler = ADC_CLOCK_ASYNC_DIV6;
  hadc1.Init.Resolution = ADC_RESOLUTION_16B;
  hadc1.Init.ScanConvMode = ADC_SCAN_DISABLE;
  hadc1.Init.EOCSelection = ADC_EOC_SINGLE_CONV;
  hadc1.Init.LowPowerAutoWait = DISABLE;
  hadc1.Init.ContinuousConvMode = DISABLE;
  hadc1.Init.NbrOfConversion = 1;
  hadc1.Init.DiscontinuousConvMode = DISABLE;
  hadc1.Init.NbrOfDiscConversion = 1;
  hadc1.Init.ExternalTrigConv = ADC_SOFTWARE_START;
  hadc1.Init.ExternalTrigConvEdge = ADC_EXTERNALTRIGCONVEDGE_NONE;
  hadc1.Init.ConversionDataManagement = ADC_CONVERSIONDATA_DR;
  hadc1.Init.Overrun = ADC_OVR_DATA_PRESERVED;
  hadc1.Init.LeftBitShift = ADC_LEFTBITSHIFT_NONE;
  hadc1.Init.BoostMode = ENABLE;
  hadc1.Init.OversamplingMode = DISABLE;
  if( HAL_ADC_Init( &hadc1 ) != HAL_OK ) {
    _Error_Handler( __FILE__, __LINE__ );
  }

  /**Configure the ADC multi-mode
  */
  multimode.Mode = ADC_MODE_INDEPENDENT;
  if( HAL_ADCEx_MultiModeConfigChannel( &hadc1, &multimode ) != HAL_OK ) {
    _Error_Handler( __FILE__, __LINE__ );
  }

  /**Configure Regular Channel
  */
  sConfig.Channel = ADC_CHANNEL_19;
  sConfig.Rank = ADC_REGULAR_RANK_1;
  sConfig.SamplingTime = ADC_SAMPLETIME_1CYCLE_5;
  sConfig.SingleDiff = ADC_SINGLE_ENDED;
  sConfig.OffsetNumber = ADC_OFFSET_NONE;
  sConfig.Offset = 0;
  if( HAL_ADC_ConfigChannel( &hadc1, &sConfig ) != HAL_OK ) {
    _Error_Handler( __FILE__, __LINE__ );
  }

}
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

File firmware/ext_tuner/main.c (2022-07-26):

//MIT License
//
//Copyright (c) 2018 tvelliott
//
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


#include "main.h"
#include "usbd_cdc_core.h"
#include "usbd_usr.h"
#include "usbd_desc.h"
#include "usbd_cdc_vcp.h"

#include "stm32f4xx_flash.h"
#include "stm32f4xx_spi.h"
#include "stm32f4_discovery.h"

#include "global.h"
#include "std_io.h"
#include "eth_hal_nxp_ngx.h"
#include "telnet.h"
#include "crc.h"
#include <math.h>
#include <ctype.h>
#include <stdio.h>
#include "config.h"

#define SPIx                           SPI2
#define SPIx_CLK                       RCC_APB1Periph_SPI2
#define SPIx_CLK_INIT                  RCC_APB1PeriphClockCmd
#define SPIx_IRQn                      SPI2_IRQn
#define SPIx_IRQHANDLER                SPI2_IRQHandler

#define SPIx_SCK_PIN                   GPIO_Pin_13
#define SPIx_SCK_GPIO_PORT             GPIOB
#define SPIx_SCK_GPIO_CLK              RCC_AHB1Periph_GPIOB
#define SPIx_SCK_SOURCE                GPIO_PinSource13
#define SPIx_SCK_AF                    GPIO_AF_SPI2

#define SPIx_MISO_PIN                  GPIO_Pin_14
#define SPIx_MISO_GPIO_PORT            GPIOB
#define SPIx_MISO_GPIO_CLK             RCC_AHB1Periph_GPIOB
#define SPIx_MISO_SOURCE               GPIO_PinSource14
#define SPIx_MISO_AF                   GPIO_AF_SPI2

#define SPIx_MOSI_PIN                  GPIO_Pin_15
#define SPIx_MOSI_GPIO_PORT            GPIOB
#define SPIx_MOSI_GPIO_CLK             RCC_AHB1Periph_GPIOB
#define SPIx_MOSI_SOURCE               GPIO_PinSource15
#define SPIx_MOSI_AF                   GPIO_AF_SPI2

#define FREQ_OFFSET ( 0.002065 )
double ppm = 2.766;

#define TRANSITION_FREQ (500.0)
double if_freq = 954.5;
#define start_freq (float) (931.2125)

void assert_param(int pass);
__ALIGN_BEGIN USB_OTG_CORE_HANDLE  USB_OTG_dev __ALIGN_END;

volatile uint8_t aRxBuffer [BUFFERSIZE];
volatile uint8_t ubRxIndex = 0;
volatile uint8_t ubTxIndex = 0;
volatile uint32_t TimeOut = 0;
extern volatile uint8_t spi_rx_int;
extern volatile uint8_t rx_len;
volatile int spi2_init=0;

uint8_t spi2_rx(void);
uint8_t spi2_tx_slave(uint8_t byte);

GPIO_InitTypeDef GPIO_InitStruct;
SPI_InitTypeDef SPI_InitStructure;

uint8_t wait_for_lock(void);
void rf_mute(void);
void rf_unmute(void);
void set_freq_mhz(double freq);
void set_freq_hz(uint32_t freq);
void set_iffreq_hz(uint32_t freq);
void delay_ms(int ms);
uint8_t synth_read_reg(uint8_t addr);
void synth_write_reg(uint8_t addr, uint8_t val);
uint8_t spi1_rx(void);
uint8_t spi1_tx(uint8_t byte);
void init_spi1(void);
void init_spi2(void);
void dump_regs(void);

void do_main_tasks(void);

__IO uint32_t TimingDelay;
__IO uint32_t tick_count;
volatile uint32_t LocalTime;
static int8_t do_dump_constant;
static int8_t do_dump;

volatile int do_freq_change=0;

/* Ethernet Driver Receive buffers  */
extern volatile uint8_t Rx_Buff[];

/* Ethernet Driver Transmit buffers */
extern volatile uint8_t Tx_Buff[];

/////////////////////////////////////////////
// delay for 3 clock cycles * ulCount
/////////////////////////////////////////////
void __attribute__((naked)) DelayClk3(unsigned long ulCount)
{
  __asm("    subs    r0, #1\n"
        "    bne     DelayClk3\n"
        "    bx      lr");
}

void handle_command(int16_t interface);

///////////////////////////////////////////////////////////////////////////////
///////////////////////////////////////////////////////////////////////////////
void handle_command(int16_t interface)
{
  int32_t count;
  double f1;

  if( strcmp(acm_in_buffer, "dreg") == 0) {
  } else if( strcmp(acm_in_buffer, "init") == 0) {
  } else if( strcmp(acm_in_buffer, "dc") == 0) {
    do_dump_constant ^= 0x01;
  } else if( strcmp(acm_in_buffer, "send") == 0) {
  } else if( strcmp(acm_in_buffer, "dump") == 0) {
    dump_regs();
  } else if( strcmp(acm_in_buffer, "debug") == 0) {
  } else if( strcmp(acm_in_buffer, "crc") == 0) {
    crc_test();
  } else if( strcmp(acm_in_buffer, "writeconfig") == 0) {
    write_config( &config );
  } else if( strcmp(acm_in_buffer, "readconfig") == 0) {
    read_config( );
  } else if( strcmp(acm_in_buffer, "defaults") == 0) {
    printf("\r\nreset configuration\r\n");
    reset_config_to_defaults( );
  } else if( strcmp(acm_in_buffer, "showconfig") == 0) {
  } else if( strncmp("iffreq", acm_in_buffer, 6) == 0) {
    acm_in_buffer[6]=0;
    f1 = (double) atof( &acm_in_buffer[7] );
    if(f1 >= 908.0 && f1 <= 960.0) {
      if_freq = (double) f1;
      config.if_frequency = if_freq;
      set_freq_mhz( config.if_frequency + config.frequency );
    }
    printf("\r\nIF frequency: %f\r\n", config.if_frequency);
  } else if( strncmp("freq", acm_in_buffer, 4) == 0) {
    acm_in_buffer[4]=0;
    f1 = (double) atof( &acm_in_buffer[5] );
    if(f1 >= 0.1 && f1 <= 1100.0) {
      config.frequency = (double) f1;
      set_freq_mhz( config.if_frequency + config.frequency );
    }
    printf("\r\nfrequency: %f\r\n", config.frequency);
  } else if( acm_scanf("txt %ld", &count) == 1) {
  } else if( strncmp("thresh", acm_in_buffer, 5) == 0) {
    acm_in_buffer[5]=0;
    f1 = (double) atof( &acm_in_buffer[6] );

    if(f1 >= 5.0 && f1 <= 1100.0) {
      config.thresh_freq = (double) f1;
      printf("\r\nthresh frequency: %f\r\n", config.thresh_freq);
      set_freq_mhz( config.if_frequency + config.frequency );
    }
  }

  uint32_t clock_mhz = SystemCoreClock / 1e6L;
  uint8_t lock = synth_read_reg(0x00);

  char lock_status[32];
  if(lock==4) sprintf(lock_status, "LOCKED @ %f, tuned to %f", config.frequency+config.if_frequency, config.frequency);
    else strcpy(lock_status, "UN_LOCKED!!");

  if(interface==ACM_INTF) {
    printf("\r\nConnected To STM32F405 Running @ %u MHz, synth is %s", (unsigned int) clock_mhz, lock_status); 
    printf( "\r\nVWR>" );

    //set_freq_mhz( start_freq );
  }
}


///////////////////////////////////////////////////////////////////////////////
// REGS are address 0 to 0x1f,   16-bit words, msb first
// a7 bit H=read,  L=write
///////////////////////////////////////////////////////////////////////////////
void dump_regs() {

uint8_t address;
uint8_t reg;

  printf("\r\n ");

  for(address=0;address<0x0f;address++) {
    reg = synth_read_reg(address);
    printf("\r\n%02x: %02x",address, reg); 
  }

  printf( "\r\n\r\nVWR>" );

}
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

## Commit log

2022-07-24 add design files
    [SDR_at86rf215.brd, SDR_at86rf215.sch]
2022-07-24 add firmware and HDL / verilog
    [ddr_in_tb.dsn]
2022-07-24 add eagle design files for the external tuner
    [ext_tuner_rev1.brd, ext_tuner_rev1.sch]
2022-07-24 add ext tuner design
    [ext_tuner_rev1.brd, ext_tuner_rev1.sch]
2022-07-25 update eagle files and schematic to reflect changes made to receiver when ext tuner was added
    [SDR_at86rf215.brd, SDR_at86rf215.sch]

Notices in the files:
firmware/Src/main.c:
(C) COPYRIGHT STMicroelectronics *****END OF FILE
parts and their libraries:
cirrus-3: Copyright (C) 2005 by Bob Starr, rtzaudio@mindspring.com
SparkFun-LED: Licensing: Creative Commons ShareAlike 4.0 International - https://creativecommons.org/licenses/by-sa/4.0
